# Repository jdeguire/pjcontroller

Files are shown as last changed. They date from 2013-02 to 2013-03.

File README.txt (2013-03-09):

I need to put something here, I guess...

Authors
-----
Jesse DeGuire, original creator

Intro
-----
This is the Projector Controller project.  The goal is to provide the DIY projector community with a robust and simple means of controlling basic functionality of their DIY light-beaming creations.  This includes things like monitoring temperature (and shutting the projector down if it gets too hot), controlling fan speed to keep the projector quiet, and turning the lamp on when the user presses the "On" button on the remote or OSD panel.

I once had a DIY projector that did much of this (rather poorly) using relays, attic fan thermostats, and way too much wiring, thus the inspiration for this project.

This project also shows that I'm terrible at coming up with clever names...

The Good Stuff
-----
The Projector Controller is made up of firmware that runs on the microcontroller on the board, software that runs on the PC and talks to the board, and the board hardware itself.

There are actually two firmwares:  the bootloader and the application.  If you plan on building either of those, you'll need the following:
--avr-gcc (Ubuntu's repo has this as 'gcc-avr' for some reason)
--avr-binutils (Ubuntu has this as 'binutils-avr')
--avr-libc
--avrdude
--scons, which in turn requires Python

The SConscript/SConstruct files assume that you are using the avr-gcc toolchain and avrdude as your
ICSP programmer.  You can modify the files if this is not the case.

To modify or run the software, you'll need:
--Python (written in v2.7)
--PySide
--PySerial

To build the software into an executable, you'll need PyInstaller and whatever prerequisites it requires.  I have been able to build a Windows executable under Windows 7 Professional Edition 64-bit without too much trouble.  This is available at /software/win32.

The schematic and board layout are created with KiCAD.  The board is currently manufactured at OSH Park (www.oshpark.com).  The Bill of Materials is available in the repo at /hardware/BoM.ods as an Open Document Spreadsheet.  LibreOffice, OpenOffice, and newer versions of Microsoft Word can open it.

More Info
-----
The Developers Guide located at /docs/devguide.pdf contains much more detailed information about the hardware, firmware, and software implementations.  Tinkerers and curious users should look at that guide and the accompanying source code and schematics.  The document is written in LaTeX and the source is in the /docs/tex directory.

Licensing
-----
The EDA design files (in hardware/pjc-kicad), along with the documents and their sources (in docs/
and docs/tex) are licensed under the Creative Commons Attribution-ShareAlike 3.0 License.  The
software and firmware code (in software/ and firmware/) , as well as their SCons build scripts, are
available under the GPLv3.

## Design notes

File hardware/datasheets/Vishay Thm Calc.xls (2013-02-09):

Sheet: user mode
 | BCcomponents
Computation spreadsheet for VISHAY BC components of reference NTCA and NTCLE
THIS FILE contains RT curves not present in the standard "RT chip-leaded & assemblies in °C" file.
The initial temperature of the table can be defined freely starting from -55 °C,and the step of temperature can be chosen between 0.1 °C and 10 °C
The maximum temperature will be fixed at 150 °C.
The reference resistance and temperature values must be given ( 25 °C or other) as well as the resistance tolerance value.
An exact B25/85 value corresponding to a selected R25 range taken from the table 1 below must be selected.
If the reference resistance for the chosen B25/85 value is not within the given limits, the following error message will
appear: "error : chosen Rref and B25/85 not compatible". Then use an adapted Rref and B25/85.
Once the B25/85 value has been chosen, the spreadsheet will show the B25/85 tolerance and the Steinhart and Hart coefficients.
In the user's mode, the example data are given for a NTCALUG03A103 (10 kOhms at 25 °C, B25/85 = 3984 K).
If the filled values are not valid, or if some values are missing, error messages will appear indicating what to do.
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

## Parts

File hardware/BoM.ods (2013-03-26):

Projector Controller Estimated Bill of Materials
Prices current as of February 23, 2013
Does not include assembly or equipment costs (eg. Solder or iron)
Prices based on minimum order quanity of 1 unit; volume discounts are not accounted for. Prices are in US Dollars.
Function | Part Number | Qty. | Vendor | Unit Price | Total Price | RoHS? | Notes
Integrated Circuits
Microcontroller | Atmel Atmega328P-PU | 1 | Mouser | 2.24 | 2.24 | Yes | DIP-28 300mil package
USB UART Interface | FTDI FT232RL | 1 | Mouser | 4.50 | 4.50 | Yes | SSOP-28 package
Ambient Temperature Sensor | Analog Devices TMP36FSZ | 1 | Digikey | 1.84 | 1.84 | Yes | SOIC-8 package
Open-Drain Buffer | TI SN74LVC1G07DBV | 1 | Digikey | 0.16 | 0.16 | Yes | SOT23-5 package
Themistor ADC | Microchip MCP3301-BI/SN | 1 | Mouser | 2.74 | 2.74 | Yes | SOIC-8 package; device is a 13-bit signed ADC
Low-Side Driver | ON Semi NUD3124DMT1G | 2 | Mouser | 0.36 | 0.72 | Yes | SOT23-6 package
5V Linear Regulator | ST Micro L78M05CDT-TR | 1 | Digikey | 0.44 | 0.44 | Yes | DPAK package
Reverse Polarity FET | Rohm Semi RSQ045N03 | 1 | Digikey | 0.78 | 0.78 | Yes | Thin SOT23-6 package
USB Suspend FET | Doides Inc. DMP2215L | 1 | Digikey | 0.40 | 0.40 | Yes | SOT23-3 package
Fan High-Side Driver | Infineon BSP762T | 1 | Digikey | 2.40 | 2.40 | Yes | SOIC-8 package
Input Optoisolator | Vishay VOM618A-4T | 1 | Mouser | 0.43 | 0.43 | Yes | SOP-4 package
Green LED | Kingbright APT3216CGCK | 1 | Mouser | 0.14 | 0.14 | Yes | 1206 SMT package; 50mcd @ 20mA, 2.1V Vf
Red LED | Kingbright APT3216SURCK | 1 | Mouser | 0.17 | 0.17 | Yes | 1206 SMT package; 220mcd @ 20mA, 1.95V Vf
Yellow LED | Kingbright APT3216SYCK | 1 | Mouser | 0.18 | 0.18 | Yes | 1206 SMT package; 150mcd @ 20mA, 2.0V Vf
20MHz Oscillator | ECS ECS-200-20-3X-EN-TR | 1 | Mouser | 0.60 | 0.60 | Yes | CSM-3X package
Passive Components
PTC 120mA Fuse | Cooper Bussmann PTS120630V012 | 5 | Digikey | 0.30 | 1.50 | Yes | 1206 SMT package
3.3kOhm Resistor | Stackpole RMCF1206FT3K30 | 3 | Digikey | 0.06 | 0.18 | Yes | 1206 SMT package; 1%, 1/4W
10kOhm Resistor | Stackpole RMCF1206FT10K0 | 8 | Digikey | 0.06 | 0.48 | Yes | 1206 SMT package; 1%, 1/4W
20kOhm Resistor | Stackpole RMCF1206FT20K0 | 1 | Digikey | 0.06 | 0.06 | Yes | 1206 SMT package; 1%, 1/4W
2.2kOhm Resistor | Stackpole RMCF1206FT2K20 | 1 | Digikey | 0.06 | 0.06 | Yes | 1206 SMT package; 1%, 1/4W
1.5kOhm Resistor | Stackpole RMCF1206FT1K50 | 1 | Digikey | 0.06 | 0.06 | Yes | 1206 SMT package; 1%, 1/4W
1kOhm Resistor | Stackpole RMCF1206FT1K00 | 1 | Digikey | 0.06 | 0.06 | Yes | 1206 SMT package; 1%, 1/4W
470Ohm Resistor | Stackpole RMCF1206FT470R | 1 | Digikey | 0.06 | 0.06 | Yes | 1206 SMT package; 1%, 1/4W
10uF Capacitor | Taiyo Yuden GMK316BJ106KL-T | 1 | Digikey | 0.36 | 0.36 | Yes | 1206 SMT package; 10%, 35V, X5R
1uF Capacitor | Taiyo Yuden UMK316B7105KL-T | 1 | Digikey | 0.25 | 0.25 | Yes | 1206 SMT package; 10%, 50V, X7R
4.7uF Capacitor | Taiyo Yuden UMK316AB7475KL-T | 1 | Digikey | 0.28 | 0.28 | Yes | 1206 SMT package; 10%, 50V, X7R
100nF Capacitor | Murata GRM319R71H104KA01D | 8 | Digikey | 0.11 | 0.88 | Yes | 1206 SMT package; 10%, 50V, X7R
10nF Capacitor | Murata GRM319R71H103KA01D | 1 | Digikey | 0.20 | 0.20 | Yes | 1206 SMT package; 10%, 50V, X7R
33pF Capacitor | Kemet C1206C330J1GACTU | 2 | Mouser | 0.11 | 0.22 | Yes | 1206 SMT package; 10%, 50V, C0G
USB Ferrite Bead | Laird MI1206L391R-10 | 1 | Digikey | 0.11 | 0.11 | Yes | 1206 SMT package
Backfeed Diode | Diodes Inc. S1M-13-F | 1 | Digikey | 0.15 | 0.15 | Yes | SMA package; 1A If, 1000V reverse voltage
Connector Headers (Onboard)
Thermistor Input | JST B2B-PH-K-S(LF)(SN) | 1 | Digikey | 0.16 | 0.16 | Yes | PH Series 2.0mm pitch 2-pos, 2A per contact
External LEDs/Relay | TE Connectivity 292207-2 | 4 | Mouser | 0.32 | 1.28 | Yes | Mini CT Series 1.5mm pitch 2-pos, 2A per contact
Switch Input | TE Connectivity 292207-3 | 1 | Mouser | 0.31 | 0.31 | Yes | Mini CT Series 1.5mm pitch 3-pos, 2A per contact
Fan Output | Molex 47053-1000 | 1 | Digikey | 0.43 | 0.43 | Yes | 4-pin PC Fan connector, 2.54mm pitch, 4A per contact
12V Input | TE Connectivity 1776275-2 | 1 | Mouser | 0.41 | 0.41 | Yes | 3.5mm pitch 2-pos screw terminal, 7A per contact
ICSP Connector | Sullins SBH11-PBPC-D05-ST-BK | 1 | Digikey | 0.61 | 0.61 | Yes | 2.54mm pitch 2x5 shrouded black, 3A per contact
USB Connector | On Shore Technology USB-M26FTR | 1 | Digikey | 0.68 | 0.68 | Yes | Mini-B USB SMD
Bootloader Enable Jumper | SparkFun PRT-00116 | 1 | SparkFun | 1.50 | 1.50 | Yes | Basic 2.54mm pitch jumper pins, sold as 40-pin breakaway headers
Connector Plug (External)
Thermistor Input | SparkFun PRT-08670 | 1 | SparkFun | 0.95 | 0.95 | Yes | JST PH Series jumper, red and black wires
External LEDs/Relay | TE Connectivity 353293-2 | 4 | Digikey | 0.26 | 1.04 | Yes | Mini CT "MT" Connector 28-26AWG, 2-pos
Switch Input | TE Connectivity 353293-3 | 1 | Digikey | 0.27 | 0.27 | Yes | Mini CT "MT" Connector 28-26AWG, 3-pos
2-pin Jumper Shunt | TE Connectivity 2-382811-1 | 1 | Mouser | 0.10 | 0.10 | Yes | Basic jumper shunt, very common part from many sources
Other
Reset Button | TE Connectivity 3-1977120-6 | 1 | Digikey | 0.10 | 0.10 | Yes | PTH 4-pin; oringally known as FSM4JH (vendors may be using this number)
MCU Socket | TE Connectivity 1-390261-9 | 1 | Mouser | 0.31 | 0.31 | Yes | DIP-28 300mil
5V Selector Switch | C&K JS102011SAQN | 1 | Digikey | 0.51 | 0.51 | Yes | 3-pin SMT
Thermistor | Vishay NTCALUG02A103G | 1 | Mouser | 1.19 | 1.19 | Yes | 10kOhm @ 25degC, Ring Terminal, M3 screw
Manufacturing
Bareboard Cost | 2-layer PCB, ~18sq. in. | 1 | OSH Park | 90.00 | 90.00 | Yes | Based on $5/sq. in. Each order is for 3 boards.
Totals
 |  | 75 |  |  | 122.50

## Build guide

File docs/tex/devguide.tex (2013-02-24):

% Copyright © 2011-2013 Jesse DeGuire
%
% This file is part of Projector Controller.
%
% This work is licensed under the Creative Commons Attribution-ShareAlike 3.0 Unported License. You
% should have received a copy of the license along with this work.  If not, see
% <http://creativecommons.org/licenses/by-sa/3.0/>.
%
% File:   devguide.tex
% Author: Jesse DeGuire
%
% LaTeX source for the PJC Developers Guide document.  This can be made into a PDF using a suitable
% LaTeX distribution such as TeX Live for GNU/Linux or MiKTeX for Windows.

\documentclass{article}

\usepackage{textcomp}
\usepackage{textgreek}
\usepackage{url}
\usepackage{longtable}
\usepackage{anysize} 
\usepackage{graphicx}
\usepackage{amsmath}
\usepackage{floatflt} 
\usepackage{enumitem}
\usepackage[pdftex]{hyperref}
\hypersetup{colorlinks=true, urlcolor=cyan, linkcolor=blue}

\marginsize{.75in}{.75in}{.75in}{.75in}

% just so that the document revision is somewhere convenient
\newcommand{\docrev}{A}

% makes a backslash
\newcommand{\bs}{$\backslash$}

% degree symbol and overbar in either math or text mode
% found these on the TeX Stack Exchange
\newcommand{\degree}{\ensuremath{^{\circ}}}
\newcommand{\textoverline}[1]{$\overline{\mbox{#1}}$}

% enclose argument in angle brackets
\newcommand{\abrackets}[1]{\textlangle #1\textrangle}

\begin{document}

% don't add extra space to sentence ends when justifying text
\frenchspacing

\noindent {\Huge Projector Controller} \\
{\large Developers Guide} Rev. \docrev \\
Author: Jesse DeGuire \\
Email: \href{mailto:jesse.a.deguire+pjc@gmail.com}{jesse.a.deguire+pjc@gmail.com} \\
Date: \today \\

\tableofcontents

% redefine \section command to start section on new page
\let\stdsection\section
\renewcommand{\section}{\newpage\stdsection}

% set spacing between paragraphs
\setlength{\parskip}{8pt}

% set up spacing for lists using 'enumitem' package
\setlist{labelindent = \parindent, itemsep=0pt}

\section*{Revision History}
\phantomsection
This section describes revisions made to this document.  Changes made to the hardware, firmware, or
software are described in their respective sections.

\begin{center}
    \begin{tabular}{c|c|p{0.6\textwidth}}
        Doc Revision & Date & Changes \\
        \hline
        A & Feb. 14, 2013 & Initial revision \\
    \end{tabular}
\end{center}

\section{Introduction}
This document provides implementation details for the various pieces of the Projector Controller
system.  The information contain within will hopefully be useful for anyone who wishes to modify or
tinker with the any part of the system or at least will satisfy an interested user's curiosity.
Anyone who is only looking to get the Controller running in his or her projector should instead
consult the \textit{Projector Controller Users Guide}.

This guide is divided up into a few sections.  The \hyperref[sec:Hardware]{Hardware} section
describes the components used on the board itself as well as the power requirements and capabilities
of the board.  The \hyperref[sec:Firmware]{Firmware} section contains information regarding the
program flow of the bootloader and application firmwares used by the Projector Controller.  This
also contains documentation for the command interfaces used by both to communicate to the host PC as
well as brief descriptions of many of the source code files.  Finally, the
\hyperref[sec:Software]{Software} section describes how the PC-side software communicates to the
board.  All sections will additionally state what tools were used in their development so that
anyone can build and modify the various pieces.

\subsection{Sources and Licenses} \label{ssec:SourceLic}
All source files used to create the board, software, and firmwares are available in a Git repository
on GitHub at \url{https://github.com/jdeguire/pjcontroller}.  The repository also contains
datasheets for the hardware components and other reference material.  This document will often
reference paths within the repository.  For example, the path \path{firmware/common/uart.c} should
be read as ``\path{[\emph{location/to/which/repository/was/cloned}]/firmware/common/uart.c}''.

The firmware and software, the sources of which are located in the \path{firmware/} and
\path{software/} directories in the aforementioned repository, are made available under the GNU
Public License Version 3.  A copy of the GPLv3 is provided in the file \path{COPYING.txt} in the
repository root or online at \url{http://www.gnu.org/licenses/}.

This document, the \textit{Users Guide}, their associated \LaTeX{} source files, and the board
design files are all made available under the Creative Commons Attribution-ShareAlike 3.0 Unported
License.  The source files for the \textit{Developers Guide} and \textit{Users Guide} are available
in the \path{docs/tex/} directory.  The board design files are found in
\path{hardware/pjc-kicad/}.  A copy of the Creative Commons BY-SA 3.0 license is provided in the
file \path{CC BY-SA 3.0 legalcode.txt} in the repository root or online at
\url{http://creativecommons.org/licenses/by-sa/3.0/}.

Where attribution is required, it is sufficient to include a statement of reasonable visibility in
the derived work or supporting documentation mentioning that the work is derived from this project
and giving this author's name.  It would be appreciated if the statement also contained the URL,
given above, for the version control repository.

Located in \path{hardware/pjc-kicad/libs/} are two files \path{SparkFun.lib} and
\path{SparkFun.mod}.  These were converted into their current form for use with KiCad from the
original Eagle libraries provided by SparkFun Electronics under the CC BY-SA 3.0 license.  The
latest such libraries can be found on GitHub at
\url{https://github.com/sparkfun/SparkFun-Eagle-Libraries}.

\subsection{Open Source Hardware} \label{ssec:OpenSourceHW}
\begin{floatingfigure}{0.22\textwidth}
    \centering
    \vspace{-6pt}
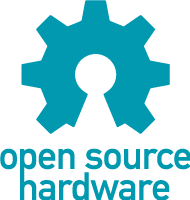
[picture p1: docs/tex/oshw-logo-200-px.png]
    
\end{floatingfigure}

As described above, all design and source code files for Projector Controller are available under
licenses allowing one to ``study, modify, distribute, make, and sell the design or hardware based on
that design''.  The project was developed using freely-available tools, most of which are also open
source, lowering the barrier to accessing the design.  Therefore, the author believes that the
Projector Controller qualifies as Open Source Hardware as given in the Open Source Hardware
Definition 1.0.  The defintions is availabe from the Open Source Hardware Association at
\url{http://www.oshwa.org/definition/}.

Note that the logo itself does not have a license associated with it, but the guidelines presented
at \url{http://www.oshwa.org/faq/} recommded its use.  Any derived works which do not adhere to the
definition of Open Source Hardware should remove the logo from any files which contain it.

\section{Hardware} \label{sec:Hardware}
The hardware was designed using KiCad EDA, an open source (GPLv2) multi-purpose EDA tool available
for various flavors of GNU/Linux, Windows, and OS X.  Get KiCad from the official site at
\url{http://www.kicad-pcb.org/display/KICAD/Download+Kicad}.  If possible, download a Snapshot build
as those contain additional features over the rather old stable release.  Ubuntu users should use
the Adam Wolf PPA given on that page.

Datasheets for the various components used are available in the repository under
\path{hardware/datasheets}.  The datasheets are provided for reference only and belong to their
respective manufacturers.

\subsection{Hardware Changes} \label{ssec:HWChanges}
This section lists the changes that have been made to the different board revisions over time.  The
revision is incremented when the board layout is changed and those changes are made into
manufactured boards.

\begin{center}
    \begin{tabular}{c|c|p{0.6\textwidth}}
        HW Revision & Date & Changes \\
        \hline
        A & Feb. 14, 2013 & Initial revision \\
    \end{tabular}
\end{center}

\subsection{Design Considerations} \label{ssec:DesignConsid}
Becuase the Projector Controller will probably never acheive high-volume production, the main
consideration was ease of assembly.  When possible, the components used are of a large form factor
(such as 1206 for resistors) and the footprints for surface-mount devices use long pads to make
accessing them with a soldering iron easier.  The board uses a socket for the 28-pin DIP
microcontroller to allow easy replacement.  These choices allow the board to be assembled by hand
for small production runs and allow the user to more easily tinker with the board.

Though not a primary consideration, the board was also designed with an eye on power consumption.
The board will be able to run certain componenets from USB power.  USB provides 5V at 100mA by
default, though a device can request up to 500mA.  The USB interface device does not identify itself
as a high-power device by default, so all 5V components will need to consume less than 100mA
combined.  The power consumption of the board is characterized in the
\hyperref[ssec:PowerUsage]{Power Usage} section.

\subsection{Circuit Details} \label{ssec:CircuitDetails}
Following are desciptions of the different circuit pieces developed for the board.  The reader of
this section may want to have the schematic handy in order to follow along.  The titles of the
descriptions will closely match the text titles used in the schematic for the different circuits.

\subsubsection{Microcontroller} \label{sssec:Microcontroller}
The heart of the Projector Controller is an Atmel ATMega328P 8-bit microcontroller.  The MCU has
32KB of flash, 4KB of which is used for the bootloader, 2KB of RAM and several useful peripherals,
such as 10-bit ADCs, SPI, PWM outputs, timers, and quite a few IO pins.  The MCU is a 28-pin DIP
package which will insert into a socket on the board, making removal and replacement easy.

An ECS 20MHz crystal oscillator provides the CPU clock.

Three LEDs--red, yellow, and green--are provided to allow the firmware to convey diagnostic
information while running.  The LED outputs also control low-side drivers, which is explained in the
\hyperref[sssec:RelayLED]{Relay and LED Outputs} description.

A jumper, pulled low, is connected to an IO pin on the microcontroller.  Shorting the jumper sets
the state of that IO pin high.  The state of this pin is read by the bootloader when it first starts
up.  If the pin state is high, the bootloader will not start the application and will instead stay
in the bootloader.  This allows one to recover from a problematic application that fails on startup.

\subsubsection{USB/UART IO} \label{sssec:USBUART}
The Projector Controller communicates with the outside world by utilizing an FTDI FT232R UART to
USB interface chip.  The chip connects to a standard USB Mini-B connector on one side and the
microcontroller's logic-level UART pins on the other, acting as a translator between the two
protocols.  The chip presents itself to the connected USB host as a virutal COM port to
allow one to communicate with the board using a terminal program such as TeraTerm or HyperTerminal.
Newer operating systems should have drivers for the device pre-installed; however, drivers are also
available from \url{http://www.ftdichip.com/FTDrivers.htm}.  Windows users may need to download the
needed drivers from Windows Update.

The circuit used is similar to the one presented in Section 6.3 of the FT232R datasheet.  Because
the 5V components on the board can be powered over USB (see the \hyperref[sssec:MainPower]{Main
  Power Input} description), this device needs to comply with USB suspend mode requirements.  When
the USB host enters USB Suspend Mode, the attached device must power down and draw less than 2.5mA
of current.  To facilitate this, pin 14 of the FT232R defaults to an active low ``Power Enable'' pin.
When entering USB suspend mode, that pin will be pulled high by the 10k\textOmega{} pullup and will
``turn off'' the Diodes Inc. DMP2215L P-channel MOSFET, essentially cutting power to the rest of the
5V system.  When the USB host exits Suspend Mode, the FT232R will pull the line low to re-active the
MOSFET.  The datasheet for the MOSFET give a current rating of 2A at 70\textcelsius{}.

The FT232R defaults to USB low-power mode, which requires that the device in question draw at most
100mA.  Given a thermal resistance of 115\textcelsius{}/W and on-resistance of 100m\textOmega{}, a
100mA draw would raise the MOSFET's temperature over ambient by

\begin{align*}
    \Delta T &= P * R_{th} \\
    &= (I^2R) * R_{th} \\
    &= (0.01 * 0.1) * 115 \\
    \Delta T &= 0.115\degree C
\end{align*}

Both the USB connector and the FT232R are fine-pitch parts, the latter using a 28-pin SSOP package.
These two are probably the most challenging parts on the board to solder, so they will need to be
placed appropriately to help make soldering them a bit easier.

\subsubsection{Main Power Input} \label{sssec:MainPower}
The board accepts a nominal 12V supply through a screw terminal rated up to 7A input, which is much
higher than the continuous current the board is designed for (see the
\hyperref[ssec:PowerUsage]{Power Usage} and \hyperref[sssec:FanControl]{Fan Control} descriptions).

To help prevent damage from occurring due to hooking up the power supply backwards, a Rohm
Semiconductor RSQ045N03 N-channel MOSFET is placed across what is normally the current return path
and the gate connected through a 3.3k\textOmega{} resistor to the normally-positive side.  When the
power is connected correctly, the gate is pulled up to 12V and the FET is fully-on.  When the power
is connected backwards, the gate is pulled low and the MOSFET is turned off.  The MOSFET has a
steady-state current rating of 4.5A and a peak rating of 18A.  The device also has a max
on-resistance of 38m\textOmega{}.  With a maximum temperature of 150\textcelsius{} and a thermal
resistance of 100\textcelsius{}/W, at 40\textcelsius{} ambient\footnote{The inside of a projector
  will certainly be warmer then the outside air temperature, with the actual ambient temperature
  depending on where inside the projector the board is placed.  The chosen 40\textcelsius{} value is
  probably on the warmer side of normal, but provides some safety margin.  This is used as the
  ambient temperature throughout this document.} the maximum power dissipated by the device is given
by

\begin{align*}
    P_{max} &= \frac{T_{max}-T_{amb}}{R_{th}} \\
    &= \frac{150 - 40}{100} \\
    P_{max} &= 1.1W
\end{align*}

which gives a maximum current of

\begin{align*}
    I &= \sqrt{\frac{P}{R_{th}}} \\
    &= \sqrt{\frac{1.1}{0.038}} \\
    I &\approx 5.38A
\end{align*}

meaning that the device is limited by the specified limit of 4.5A rather than by heat.

The 5V supply comes from an ST Microelectronics L78M05C linear regulator fed from the 12V supply.
The device is rated to output currents up to 0.5A and features thermal overload shutdown that will
cut output power in order to protect itself.  The device has a maximum temperature of
150\textcelsius{} and a worst-case thermal resistance of 100\textcelsius{}/W, assuming minimal
heatsinking.

As previously stated, the 5V devices are designed to draw at most 100mA so that they can be powered
via USB.  A selector switch allows the user to select between USB and the 5V regulator as the 5V
power source.  This is useful in the case the user needs to remove the board from the projector and
connect it to the PC for configuring it.  The switch is rated for 6VDC at 300mA or 30VDC at 100mA.
The output side of the selector switch has a Cooper Bussmann PTS120630V012 PTC fuse rated at 120mA
at 23\textcelsius{}.  Using the derating curve in the datasheet shows that the hold current drops to
about 100mA at an ambient temperature of 40\textcelsius{}.  A Diodes Inc. S1M-13-F diode, rated at
1A continuous and 1000V reverse DC voltage, is placed between the regulator and 12V input to prevent
USB current from back-feeding through the regulator.  If only a USB cable is connected to the board,
only the 5V devices will be powered.

Given a worst-case thermal resistance of 100\textcelsius{}/W and nominal voltage drop of 7V, a 100mA
draw would raise the device's temperature over ambient by

\begin{align*}
    \Delta T &= P * R_{th} \\
    &= (V*I) * R_{th} \\
    &= (7 * 0.1) * 100 \\
    \Delta T &= 70\degree C
\end{align*}

Some heatsinking can be provided by englarged pads or copper pours on the board.

\subsubsection{Programming and Reset} \label{sssec:ProgReset}
The ATMega328P microcontroller can be reprogrammed using a standard 10-pin AVR ISP header.  The
pinout used should work with most, if not all, external programmers.  The microcontroller is
programmed through the SPI lines while the device is held in reset.  The 5V pin on the header allows
the board to power the programmer so that the logic signals are at the correct voltage levels.  If
the board is powered via USB, care must be taken to not exceed a total of 100mA draw when powering
the programmer in this manner.  See \hyperref[ssec:PowerUsage]{Power Usage} for more information.

The user can reset the board using a push button connected to ground.  The device's
\textoverline{RESET} pin is active low, so it is normally pulled high and pressing the button
creates a connection to ground.

\subsubsection{Analog Inputs} \label{sssec:AnalogIn}
Two of the microcontroller's analog inputs are used to monitor the 12V input and ambient temperature
from an Analog Devices TMP36 temperature sensor.  The microcontroller's analog inputs are 10-bit
single-ended ADCs.

The 12V input is divided down using a simple resistive divider in an approximate 3:1 ratio, meaning that the
input into the ADC is about 1/4 the actual voltage.  More specifically, to determine the actual
voltage on the 12V input, multiply the ADC voltage by 4.03.

The TMP36 ``F Grade'' part used here has a worst-case accuracy of \textpm3\textcelsius{}.  At
0\textcelsius{} the device outputs 500mV and the output changes by 10mV/\textcelsius{}.

\subsubsection{Relay and LED Outputs} \label{sssec:RelayLED} 
Four 12V outputs are provided to control external devices.  The outputs are controlled using two ON
Semiconductor NUD3124DMT1G dual low-side drivers.  The drivers are meant to be single-chip solutions
for driving small motors and relays and so include a flyback diode and gate resistor.

The 4 connectors are 2-pin TE Connectivity Mini CT series connectors, which are 1.5mm pitch and
rated for 2A maximum.  The LED connectors will be grouped together and the relay connector separated
a bit to help differentiate them.

Three of the driver outputs are controlled by the three LED outputs on the microcontroller (see
\hyperref[sssec:Microcontroller]{Microcontroller} description).  The user can connect external LEDs
to these outputs and mount them to the projector's chassis so that the firmware's diagnostic
signaling is visible from outside the projector.  The outputs provide 12V power, so the user will
need to use an appropriate current-limiting resistor with the external LED.  Alternatively,
electronics stores sell LED packages with the proper resistor built in.  The current-limiting
resistors for the onboard LEDs also act as pulldowns for these outputs.

The fourth output is used as a lamp enable output and can be used to turn on, for example, an
external relay coil which in turn turns the lamp on.  This output has a 10k pulldown on it.

The high side of each output has a Cooper Bussmann PTS120630V012 PTC fuse rated at 120mA at
23\textcelsius{}.  Using the derating curve in the datasheet shows that the hold current drops to
about 100mA at an ambient temperature of 40\textcelsius{}.  Given a thermal resistance of
329\textcelsius{}/W and worst-case on-resistance of 1.1\textOmega, both outputs drawing 100mA would
raise the driver's temperature over ambient by

\begin{align*}
    \Delta T &= P * R_{th} \\
    &= (I^2R) * R_{th} \\
    &= (0.04 * 1.1) * 329 \\
    \Delta T &\approx 14.5\degree C
\end{align*}

\subsubsection{Fan Control} \label{sssec:FanControl}
A single Molex 4-pin fan header is provided for connecting a standard PWM-controlled PC fan.  The
connector is rated at 4A max per contact.  The Sense output, which acts as a tachometer signal from
the fan, is not used.  12V power is controlled by an Infineon BSP762T high-side driver.  The driver
has a worst-case on-resistance of 200m\textOmega.  With a maximum temperature of 150\textcelsius{}
and a thermal resistance of 95\textcelsius{}/W, at 40\textcelsius{} ambient the maximum power
dissipated by the device is given by

\begin{align*}
    P_{max} &= \frac{T_{max}-T_{amb}}{R_{th}} \\
    &= \frac{150 - 40}{95} \\
    P_{max} &\approx 1.15W
\end{align*}

which is below the rated absolute maximum of 1.5W and therefore gives a maximum current of

\begin{align*}
    I &= \sqrt{\frac{P}{R_{th}}} \\
    &= \sqrt{\frac{1.15}{0.2}} \\
    I &\approx 2.4A
\end{align*}

which matches the typical load current ($I_{L(nom)}$) provided in the datasheet.  Note that the
on-resistance value used will occur only when the device is operating at its max junction
temperature; the on-resistance, and therefore temperature, will usually be much lower.  Users will
be instructed to draw 2A max.

The driver has a thermal shutdown feature to protect the device in over-current or short circuit
conditions.  The device will turn the output off when in thermal overload and turn it back on when
it has cooled sufficiently.  In the case of short circuit, the driver will repeatedly turn off and
back on with a repetitive short circuit current of 7A.  The driver is not designed to continuously
operate in this state, so the user will need to take care to not leave the output shorted.

The PWM output signal is supplied from one of the microcontroller's 8-bit PWM outputs.  According to
the Intel 4-pin fan specification (available in the \path{/hardware/datasheets} directory of the
repository), the nominal PWM output is 25kHz.  The PWM signal goes through a TI SN74LVC1G07
non-inverting open-drain buffer since the fan pulls up the signal internally. The buffer has a max
switching time of 3.5ns, which is far faster then required by the PWM signal.  The Intel fan spec
recommends a current sink capability of 8mA, though the maximum current a fan is allowed to source
is 5mA.  The recommended max for the buffer is 32mA (the absolute max is 50mA), so a user could
theoretically control 4 fans using splitters assuming each fan sources less than the recommended
current sink capability of the controlling device.

If the connected fan does not have a PWM input signal (standard PC 3-pin fan), the Projector
Controller will still provide basic on/off control with the high-side driver.

The driver input and buffer input signals each have a 10k\textOmega{} pulldown.

\subsubsection{Temperature Input} \label{sssec:TempInput}
Temperature is read using a Vishay NTCALUG02A103G 10k (\textpm2\% at 25\textcelsius) thermistor,
which is enclosed in a ring terminal for easy mounting in the projector.  The ring terminal accepts
a metric M3 screw.  The user will normally want to place the thermistor as close to the monitored
object, usually the LCD panel, as he or she can.  The user may need to try a few locations to find
the best one.

The thermistor input is a 2-pin JST PH Series connector, which is 2.0mm pitch and rated for 2A maximum.

The equation for getting the temperature from a thermistor is the Steinhart-Hart equation, which is

\[
T = \frac{1}{A + B\ln(\frac{R_T}{R_{25}}) + C\ln^2(\frac{R_T}{R_{25}}) + D\ln^3(\frac{R_T}{R_{25}})}
- 273.15
\]

where $R_T/R_{25}$ is the ratio between the thermistor's actual resistance and its reference
resistance (10k\textOmega{} in this case).  The basic equation gives the result in Kelvin, so 273.15
is subtracted to convert that to Celsius.  To get the temperature, it is necessary to determine the
thermistor's actual resistance and that can be done using the voltage going into the ADC.

The ADC is a Microchip MCP3301 differential SPI ADC that returns data in 13-bit two's complement
representation.  The positive input to the ADC, $IN+$, is the output of a voltage divider formed by
the thermistor and a 10k\textOmega{} resistor.  The ADC has a separate reference voltage input,
$V_{REF}$, and the input range is $\pm V_{REF}$.  To take advantage of the full 13-bit scale, a
voltage divider with two 10k\textOmega{} resistors splits the 5V input in half and the resulting
2.5V is fed into both the $V_{REF}$ and $IN-$ inputs.  If the thermistor is 25\textcelsius{}, it
will also be at 2.5V and so the ADC reading will be 0.  The ADC reading will be negative if the
thermistor is colder than 25\textcelsius{} and positive if warmer.  To get the actual voltage going
into the ADC positive in put, convert the ADC reading to voltage (remember to sign-extend the
reading) and then add 2.5V to it.

Note that if the thermistor is not connected, the voltage at the ADC should be 0 and so the reading
should be negative full-scale (-4096).  Conversely, if the thermistor input is shorted, then the
voltage should be around 5V and so the reading should be positive full-scale (4095).  However, the
ADC is not perfect and so such conditions may be close to, but not exactly, the full-scale
conditions.

The thermistor's actual resistance can now be calculated with

\[
R_T = \frac{R_2*V_{in}}{V_{ADC}} - R_2
\]

which is just the standard resistor divider equation solved for $R1$ (which is $R_T$ in this case).
To get the ratio between the actual resistance and the reference resistance required by the 
Steinhart-Hart equation, the above equation can be divided by $R_{25}$.  Doing that and plugging in
the appropriate values for $V_{in}$ and $R_2$ yields

\begin{align*}
    \frac{R_T}{R_{25}} &= \frac{\frac{10k * 5}{V_{ADC}} - 10k}{R_{25}} \\
    &= \frac{\frac{50k}{V_{ADC}} - 10k}{10k} \\
    \frac{R_T}{R_{25}} &= \frac{5}{V_{ADC}} - 1
\end{align*}

Notice that when the ADC reading is at negative full-scale (-4096 counts), $V_{ADC}$ will be zero
and so will cause a divide by zero error.  As mentioned above, this happens when the thermistor is
not connected and is an abnormal condition.  To avoid the divide by zero problem, look for the
negative full-scale reading and treat that as a special case.  One possible solution is to clamp the
input range to \textpm 4095.

The cofficients for the Steinhart-Hart equation come from a Microsoft Excel spreadsheet on Vishay's
website at \url{http://www.vishay.com/resistors-non-linear/curve-computation-list/}.  The
spreadsheet for the NTCALUG02A103G is available in the repository at
\path{/hardware/datasheets/Vishay Thm Calc.xls}.  The coefficients are on the RTCOEF page of the
spreadsheet and are

\begin{align*}
    A &= 0.0033540164 \\
    B &= 0.0002565236 \\
    C &= 2.605970e-6 \\
    D &= 6.329261e-8
\end{align*}

These coefficients and the previous equation provide enough information to evaluate the
Steinhart-Hart equation.

\subsubsection{Projector On Input} \label{sssec:PJOnInput}
The controller card for the projector's LCD panel also controls the LCD's backlight and will output
a 5V or 12V signal to a backlight inverter to turn it on.  Since the projector discards the
backlight in favor of a high-power lamp, the Projector Controller has an input for that backlight
signal and will use that for the similar purpose of turning on the lamp.  The input connector is a
3-pin TE Connectivity Mini CT series connector, which is 1.5mm pitch and rated for 2A maximum.  A
3-pin connector was used to differentiate it from the output connectors; the middle pin is not used.

The used connector pins go to the input of a Vishay VOM618A-4T opto-isolator. The opto has a minimum
current transfer ratio (gain) of 160\% when the current through the LED is 1mA.  The output is a
collector-emitter junction with the LED acting as the base of a transistor, so if the forward
current through the LED is 1mA then the collector current will be 1.6mA (assuming the device is not
saturated).  The LED on the opto can handle a reverse voltage of 6V, so the user needs to be careful
when connecting an input greater than that and make sure to not connect it backwards.

The collector of the opto is connected to 5V and the emitter connects to the microcontroller input
pin and a 20k\textOmega{} pulldown, making the input active-high.  With a typical collector-emitter
saturation voltage of 0.12V (max is 0.4V), the collector current is

\begin{align*}
    I_C &= \frac{V_{in} - V_{CESat}}{R_L} \\
    &= \frac{5 - 0.12}{10k} \\
    I_C &= 0.244mA
\end{align*}

so the LED forward current times the current transfer ratio must be greater than 0.244mA in order to
drive the opto in to saturation.  This is much lower than the maximum allowed collector current of
50mA.

Between the positive input pin and the anode of the LED is a 3.3k\textOmega{} current-limiting
resistor.  An LCD controller board with a 5V backlight enable signal will, with a typical LED
forward voltage of 1.1V, need to be capable of supplying

\begin{align*}
    I_F &= \frac{V_{in} - V_f}{R_I} \\
    &= \frac{5 - 1.1}{3.3k} \\
    I_F &= 1.18mA
\end{align*}

of current.  This is very close to the test current at which the opto's transfer ratio is rated.
Using an ambient temperature of 40\textcelsius{} derates the ratio to 90\%, according to Figure 9 on
page 5 of the datasheet, giving a minimum ratio of 1.44.  This make the theoretical collector
current 1.70mA, driving the opto well into saturation.  Performing similar math for a 12V input
shows that it will need to be able to supply about 3.3mA of current and will provide a theoretical
collector current of 4.75mA.  Doing the same math, but with $V_F$ at the max of 1.6V, shows that a
5V backlight signal will supply about 1mA with a theoretical collector current of 1.44mA and a 12V
signal will supply 3.15mA with a collector current of about 4.53mA.  In short, LCD controller boards
that provide a 5V or 12V backlight signal should have no trouble driving the opto into saturation
and should be able to do so while supplying only a small amount of current.

Future LCD controller boards, however, could have a 3.3V or lower backlight control signal.  Doing
the above math again with a 3.3V signal yields an LED forward current of

\begin{align*}
    I_F &= \frac{V_{in} - V_f}{R_I} \\
    &= \frac{3.3 - 1.1}{3.3k} \\
    I_F &= 0.67mA
\end{align*}

when using the typical LED forward voltage rating.  Because the current is below the 1mA test
current used by the datasheet, a additional derating of the current transfer ratio needs to be
applied.  Figure 11 on page 5 of the datasheet shows a derating of about 75\% at 25\textcelsius{}
ambient.  Applying that to the already-derated current transfer ratio of 1.44 gives 1.08.  This
means that a 3.3V input will typically have a theoretical collector current of 0.72mA.  This is 3x
higher than the actual collector current, which should easily drive the opto into saturation.  Doing
the same math with the max forward voltage of 1.6V gives a forward current of 0.5mA for a collector
current of 0.54mA.  This is a bit over twice the actual collector current, so the opto should still
be driven into saturation.

It should be noted that orignially a more standard zener diode circuit was considered.  However,
zener diodes appeared to be rated with a 5mA current.  This would mean that more current is required
from LCD controller boards that output their backlight signals to this board.  Drive specificatons
are rarely, if ever, available for LCD controller boards so it was decided to aim for a lower
current draw, which the VOM618A allows since its test current is 1mA.

\subsubsection{Mounting Holes} \label{sssec:MountingHoles}
The Projector Controller will have one mounting hole on each of its four corners.  The holes have a
4mm inner diameter and 10mm outer diameter for screw head clearance.  This is the same size used for
PC motherboards, so standoffs and screws that come with PC cases should be useable with this board.
The holes will accommodate either M3 metric screws or 6-32 standard UTS screws.

\subsection{Power Usage} \label{ssec:PowerUsage}
The following tables lists the current draw of the different components on the board.  When
possible, the values used are the worst-case useage given in the data sheet; actual usage should
normally be lower.  The device has 5V and 12V power, so multiplying the current given in the table
by its voltage input will give the power used.

\begin{center}
    \begin{tabular}{|l|c|l|}
        \hline
        Component & Current (mA) & Notes \\
        \hline
        \multicolumn{3}{|c|}{\textbf{5V Components}} \\
        \hline
        ATMega328P Active Current & 23 & See Note below \\
        ECS CSM-3X 20MHz Crystal & 0.02 & Derived from ``Drive Level'' rating \\
        FT232R Operating Current & 15 & Powered only from USB VBUS \\
        FT232R USB\_PWREN Current & 0.5 & Powered only from USB VBUS \\
        12V Feedback Divider & 0.9 & R1 = 10k\textOmega{}, R2 = 3.3k\textOmega{} \\
        TMP36 Supply Current & 0.05 & \\
        BSP762T Input Current & 0.015 & Current at IN pin while device is on \\
        MCP3301 $V_{REF}$ Current &  0.15 & Current at $V_{REF}$ while clocking data \\
        MCP3301 Operating Current & 0.45 & \\
        MCP3301 2.5V Divider & 0.25 & R1 = R2 = 10k\textOmega{} \\
        Thermistor Input Current & 0.5 & Worst case is shorted thermistor \\
        VOM618A-4T Collector Current & 0.25 & Assumes $V_{CE} = 0$ \\
        Green LED & 6.1 & \\
        Yellow LED & 2 & \\
        Red LED & 1.3  & \\
        5V, 10k\textOmega{} Pulldowns (4) & 0.5 x4 & \\
        5V, 10k\textOmega{} Pullups (2) & 0.5 x2 & \\
        \textbf{Total} & \textbf{53.485} & \\ 

        \hline
        \hline

        \multicolumn{3}{|c|}{\textbf{12V Components}} \\
        \hline
        5V Component Draw & 53.485 & See above \\
        L78M05C Quiescent Current & 6 & \\
        BSP762T Operating Current & 1.3 & \\
        \textbf{Total} & \textbf{60.785} & \\
        \hline
    \end{tabular}
\end{center}

{\small \textbf{Note}: Values were taken from Section 30.7 of the datasheet and includes all peripherals and
programming current but not external IO.  This assumes a 5.0V input voltage and 20MHz clock input.}

Any external 5V devices connected to the Projector Controller, including a board-powered ISP
programmer, must keep the total current draw under 100mA.  Given the total shown above, external
devices can use up to 46mA or so.

In addition to the loads shown here, the 12V supply also needs to be able to handle the external fan
and 4 outputs.  Therefore, the user will need to determine the current draw of his or her choosen
components and size a power supply that can handle those plus another 61mA for this board.

\subsection{Microcontroller Pinout} \label{ssec:MicroPinout}
Following is a table showing how the pins on the microcontroller are used and their net names on the
schematic, if applicable.

\begin{center}
    \begin{tabular}{c|l|l|l}
        Pin \# & Pin Name & Net Name & Description \\
        \hline 
        1  & (PCINT14/\textoverline{RESET}) PC6 & \textoverline{RESET} & Active-low CPU reset line \\
        2  & (PCINT16/RXD) PD0 & UART\_RX & UART receiver input \\
        3  & (PCINT17/TXD) PD1 & UART\_TX & UART transmitter output \\
        4  & (PCINT18/INT0) PD2 & FAN\_EN & Fan power enable \\
        5  & (PCINT19/OC2B/INT1) PD3 & FAN\_PWM & 25kHz fan control PWM signal \\
        6  & (PCINT20/XCK/T0) PD4 & \abrackets{None} & Bootloader enable pin \\
        7  & VCC & \abrackets{None} & Main supply input \\
        8  & GND & \abrackets{None} & Ground \\
        9  & (PCINT6/XTAL1/TOSC1) PB6 & \abrackets{None} & 20MHz crystal oscillator input \\
        10 & (PCINT7/XTAL2/TOSC2) PB7 & \abrackets{None} & 20MHz crystal oscillator input \\
        11 & (PCINT21/OC0B/T1) PD5 & LEN\_EN\_RED & Red LED enable \\
        12 & (PCINT22/OC0A/AIN0) PD6 & LED\_EN\_YELLOW & Yellow LED enable \\
        13 & (PCINT23/AIN1) PD7 & LED\_EN\_GREEN & Green LED enable \\
        14 & (PCINT0/CLKO/ICP1) PB0 & LAMP\_EN & Lamp relay enable \\
        15 & (PCINT1/OC1A) PB1 & \abrackets{Unused} & Not used \\
        16 & (PCINT2/OC1B/SS) PB2 & \textoverline{ADC\_CS} & SPI ADC chip select \\
        17 & (PCINT3/OC2A/MOSI) PB3 & MOSI & SPI master output \\
        18 & (PCINT4/MISO) PB4 & MISO & SPI master input \\
        19 & (PCINT5/SCK) PB5 & SCK & SPI clock \\
        20 & AVCC & \abrackets{None} & Analog suppy input \\
        21 & AREF & \abrackets{None} & Analog reference voltage \\
        22 & GND & \abrackets{None} & Ground \\
        23 & (PCINT8/ADC0) PC0 & AVA\_12V\_FB & 12V supply feedback \\
        24 & (PCINT9/ADC1) PC1 & ANA\_AMBIENT & Ambient temperature reading \\
        25 & (PCINT10/ADC2) PC2 & PROJECTOR\_ON & Projector on input \\
        26 & (PCINT11/ADC3) PC3 & \abrackets{Unused} & Not used \\
        27 & (PCINT12/ADC4) PC4 & \abrackets{Unused} & Not used \\
        28 & (PCINT13/ADC5) PC5 & \abrackets{Unused} & Not used \\
    \end{tabular}
\end{center}

\subsection{Connector Pinout} \label{ssec:ConnPinout}
The following tables gives the functions of the pins on each connector.  Pin 1 on through-hole
connectors can be found by looking for the square solder pad around the through-hole.  The USB
connector is the only surface mount connector and pin 1 is denoted by a small circle next to the
pin.

\begin{description}[itemsep = 18pt]
  \item[CON1:] Communication (USB Mini-B)
    \begin{center}
        \begin{tabular}{l|l}
            Pin \# & Description \\
            \hline
            1 & VBUS \\
            2 & D- \\
            3 & D+ \\
            4 & ID (Not Used) \\
            5 & GND \\
        \end{tabular}
    \end{center}
  \item[CON2:] Projector On Input (Mini CT 3-pin)
    \begin{center}
        \begin{tabular}{l|l}
            Pin \# & Description \\
            \hline
            1 & Input positve \\
            2 & Not Used \\
            3 & Input Negative \\
        \end{tabular}
    \end{center}
  \item[CON3:] Thermistor (JST PH 2-pin)
    \begin{center}
        \begin{tabular}{l|l}
            Pin \# & Description \\
            \hline
            1 & 5V to thermistor \\
            2 & Voltage from thermistor to ADC \\
        \end{tabular}
    \end{center}
  \item[CON4:] 12V Input (Screw Terminal)
    \begin{center}
        \begin{tabular}{l|l}
            Pin \# & Description \\
            \hline
            1 & 12V \\
            2 & Ground \\
        \end{tabular}
    \end{center}
  \item[CON5:] Fan Output (4-pin PC Fan Connector)
    \begin{center}
        \begin{tabular}{l|l}
            Pin \# & Description \\
            \hline
            1 & Ground \\
            2 & 12V \\
            3 & Sense (Not Used) \\
            4 & Control (PWM) \\
        \end{tabular}
    \end{center}
  \item[CON6:] External Red LED (Mini CT 2-pin)
    \begin{center}
        \begin{tabular}{l|l}
            Pin \# & Description \\
            \hline
            1 & 12V \\
            2 & Ground \\
        \end{tabular}
    \end{center}
  \item[CON7:] External Yellow LED (Mini CT 2-pin)
    \begin{center}
        \begin{tabular}{l|l}
            Pin \# & Description \\
            \hline
            1 & 12V \\
            2 & Ground \\
        \end{tabular}
    \end{center}
  \item[CON8:] AVR ISP Header (10-pin Shrouded)
    \begin{center}
        \begin{tabular}{l|l}
            Pin \# & Description \\
            \hline
            1  & MOSI (SPI Out) \\
            2  & VCC (5V) \\
            3  & LED/NC (Not Used) \\
            4  & Ground \\
            5  & Reset \\
            6  & Ground \\
            7  & SCK (SPI Clock) \\
            8  & Ground \\
            9  & MISO (SPI In) \\
            10 & Ground \\
        \end{tabular}
    \end{center}
  \item[CON9:] External Green LED (Mini CT 2-pin)
    \begin{center}
        \begin{tabular}{l|l}
            Pin \# & Description \\
            \hline
            1 & 12V \\
            2 & Ground \\
        \end{tabular}
    \end{center}
  \item[CON10:] Lamp Relay Enable (Mini CT 2-pin)
    \begin{center}
        \begin{tabular}{l|l}
            Pin \# & Description \\
            \hline
            1 & 12V \\
            2 & Ground \\
        \end{tabular}
    \end{center}
  \item[JP1:] Bootloader Enable Jumper
    \begin{center}
        \begin{tabular}{l|l}
            Pin \# & Description \\
            \hline
            1 & Jumper Pin 1 \\
            2 & Jumper Pin 2 \\
        \end{tabular}
    \end{center}
\end{description}

\subsection{Conversion Formulas} \label{ssec:ConversionFormulas}
The conversion formulas for the analong inputs discussed earlier are available here as well for
convenience.

\subsubsection{12V Feedback}
\begin{align*}
    V_{ADC} &= \frac{5 * Counts}{1024}\\
    V_{FB}  &= V_{ADC} * 4.03
\end{align*}

\subsubsection{Ambient Temperature}
\begin{align*}
    V_{ADC} &= \frac{5 * Counts}{1024} \\
    T_{Amb} &= 100 * (V_{ADC} - 0.5)
\end{align*}

\subsubsection{Thermistor Temperature}
The MCP3301 is a signed 13-bit ADC, so the reading must be sign-extended first.  Notice that a
reading of -4096 will cause a divide by zero error with these formulas.  This indicates a
disconnected thermistor and so is an abnormal condition that the software or firmware will need to
look out for.  One way to handle this is to clamp the input to \textpm 4095 and handle -4096 as a
special case.

\begin{align*}
    V_{ADC} &= \frac{2.5 * Counts}{4096} + 2.5 \\
    R &= \frac{5}{V_{ADC}} - 1 \\
    T &= \frac{1}{A + B\ln(R) + C\ln^2(R) + D\ln^3(R)} - 273.15
\end{align*}

where

\begin{align*}
    A &= 0.0033540164 \\
    B &= 0.0002565236 \\
    C &= 2.605970e-6 \\
    D &= 6.329261e-8
\end{align*}

\section{Firmware} \label{sec:Firmware}
The onboard ATMega328P has two different firmwares on it.  The first is a small bootloader that must
be programmed on using an external programming device.  A 10-pin header is provided onboard for this
purpose.  The bootloader is reponsible for programming application code into flash, allowing field
updates without the programming device. and to make sure a functional application is present before
handing over control to it.  The second firmware is the actual application code.  This is programmed
on by the bootloader and is what actually does the projector controlling.

This section will describe functionality common to each firmware and then delve into the functions
specific to each.  First is information on how to build and program the firmwares onto the board.

\subsection{Tools Used} \label{ssec:FWTools}
The firmware was developed in various versions Ubuntu Linux with the current one as of this writing
being version 12.10 Quantal Quetzal.  The applications listed should be available on other
distributions (or they can be built from source), but they may use different package names from what
is given here.

The firmwares use the AVR GCC cross-compiler, which is at version 4.7 as of this writing, with
the associated LibC and Binutils packages.  AVRDUDE is used to program the built firmware onto the
board.  Building and programming the firmware is handled by the SCons build tool, which itself
requires Python 2.4 or higher.

On Ubuntu 12.10, the following packages need to be installed to get everything:

\begin{itemize}
  \item gcc-avr
  \item binutils-avr
  \item avr-libc
  \item avrdude
  \item scons
\end{itemize}

The \texttt{scons} package should also grab the needed Python package.  If not, then that will need to be
installed as well.

Windows users can use Atmel Studio, which is a free IDE provided by Atmel which also includes the
needed toolchain.  The IDE is available on Atmel's website at
\url{http://www.atmel.com/tools/atmelstudio.aspx?tab=overview}.  Using the IDE itself would require
one to create two projects, one each for the bootloader and application, for the IDE since they are not
provided here.  Another possibility is to install SCons for Windows and Python alongside the IDE and
build using SCons.  The SCons Windows installer is available on the SCons website at
\url{http://www.scons.org/download.php}.  SCons should be able to find the toolchain as long as it
is in the Windows PATH.

\subsection{Building With SCons} \label{ssec:FWBuilding}
SCons is a build system (essentially a replacement for GNU Make) written in Python.  The build
scripts themselves are special Python files.  In the \path{firmware/} is a file called
\path{SConstruct}.  This is the top-level build script and contains settings that are used by both
the application and bootloader, such as include file paths and some compiler options.  The
\path{firmware/bootloader/} and \path{firmware/app/} directories each contain a file called
\path{SConscript}.  These are called from the \path{SConstruct} file and contain options
specific to the app or bootloader, such as the output file path, source files, and so on.  The files
themselves are commented so that anyone who wishes to modify build options can at least figure out
what needs to change in the files.

The SCons documentation is very good and even those inexperienced with SCons can set up a build just
by following the documentation.  The documentation is available on the SCons website at
\url{http://www.scons.org/doc/production/HTML/scons-user/index.html} and a wiki is available at
\url{http://www.scons.org/wiki/}.

To use SCons, open up a command-line window or terminal and navigate to the location of the
\path{SConstruct} file, which is \path{firmware/}.  Now run \texttt{scons \abrackets{command}},
where \texttt{\abrackets{command}} is one of the following:

\begin{description}
  \item[build-bootloader]: \\
    Build the bootloader using AVR GCC and output the resulting Intel hex file to
    \path{firmware/bootloader/output/pjc-bootloader.hex}.
  \item[write-bootloader]: \\
    Write the bootloader to the microcontroller using AVRDUDE and a compatible programmer (see
    below).  The bootloader must have been built using \texttt{build-bootloader} for this to work.
  \item[read-flash]: \\
    Read the entire contents of the microcontroller's flash memory and output the contents as an
    Intel hex file to \path{firmware/bootloader/output/pjc-flash-image.hex}.
  \item[erase-device]: \\
    Erase the device's flash, EEPROM, and lock bits, but not its fuse bits.
  \item[write-fuses]: \\
    Write the proper fuse and lock bits to the device.  This should be done the first time a new
    device is programmed.
  \item[build-app]: \\
    Build the application using AVR GCC and output the resulting Intel hex file to
    \path{firmware/app/output/pjc-app.hex}.
\end{description}

Multiple commands can be executed at once by putting more than one on the command line.  For
example, running \texttt{scons build-bootloader write-bootloader} will compile the bootloader and,
if successful, program it to flash.

The actions of these commands are defined in the \path{SConscript} files.  For example. the values
of the fuse bits programmed using the \texttt{write-fuses} command are defined in the
\path{firmware/bootloader/SConscript} file.

\subsection{Programming Flash} \label{ssec:FWProgFlash}
An external programming device is required to program the bootloader onto the device.  A 10-pin
header is provided onboard for this purpose.  The header pinout is standard across AVR device
programmers and so there are multiple programmers that will work.  

The build scripts are configured to use the ``usbtiny'' programmer protocol with AVRDUDE.  Any
programmer that conforms to that protocol will work.  Two such low-cost examples are the Adafruit
USBtinyISP (available at \url{http://www.ladyada.net/make/usbtinyisp/}) and the SparkFun Pocket AVR
Programmer (available at \url{https://www.sparkfun.com/products/9825}).

To use a different programmer, open \path{firmware/bootloader/SConscript} and look for the line
that says ``\texttt{icspdevice = 'usbtiny'}''.  Change it to a programmer that AVRDUDE recognizes (find
AVRDUDE documentation online) and save the file.

Linux users may find that trying to program a device results in AVRDUDE complaining that it cannot
talk to the programmer, saying something along the lines of ``Operation not permitted''.  If this
happens, running the command as root should make it work.  Another option is to create a new udev
rule for the programmer.  Create a new file in \path{/etc/udev/rules.d/}, or wherever udev rules
are stored, and add the line

\texttt{SUBSYSTEM=="usb", ATTR{idProduct}=="0c9f", ATTR{idVendor}=="1781", MODE="0666", GROUP="adm"}

Save the file with a descriptive name, such as \path{90-avrisp.rules}.  The number determines the
order in which the rule is processed.  Higher-numbered rules override lower-numbered rules.
Disconnect and reconnect the programmer and try again.  Note that the ``idProduct'' (0c9f) and
``idVendor'' (1781) are dependent on the actual device; the values shown are for the ``usbtiny''
programmers mentioned earlier.  Use the \texttt{lsusb} command to get the correct values for
different devices.

\subsection{Fuse and Lock Bits} \label{ssec:FWFuseBits}
The AVR microcontrollers have special locations in flash memory that hold configuration registers for
the device.  These control hardware configuration options such as the size of bootloader space, the
clock source, and write-protection features.  The mappings for the fuse and lock registers are given
in Section 28 of the ATMega's datasheet.  The following table summarizes the fuse bit configuration
used by the Projector Controller.

\begin{center}
    \begin{tabular}{l|c|p{0.5\textwidth}}
        Register & Value & Notes \\
        \hline
        lfuse & 0xF7 & Use external full-swing crystal and longest startup time \\
        hfuse & 0xD8 & Defaults except set to use bootloader reset vector; that is, start in the
        bootloader rather than application \\
        efuse & 0x04 & Brown-out detection enabled at 4.3V \\
        lock  & 0x3F & Defaults; no lock features enabled \\
    \end{tabular}
\end{center}

The fuse and lock bit values programmed onto the device are stored in
\path{firmware/bootloader/SConscript}.  Use caution when changing these as the wrong values can
make the device unprogrammable.  In that case, one would need to purchase a parallel programmer to
correct the problem.  Doing a search for ``AVR fuse calculator'' online will bring up utilities that
provide help in setting the bits to the correct values.

\subsection{Intel Hex Files} \label{ssec:FWIntelHex}
The firmwares are stored as Intel hex files, which are text files that store binary information,
such as program data for the firmware.  Each line is a record which can contain program data, 
address information, or an indicator that the end of file was reached.  The file is parsed one
record at a time to ultimately yield a binary image of the data.  Below is a typical record.

\texttt{:10700000CEC00000F3C00000F1C00000EFC00000DF}

The colon (``:'') at the beginning indicates the start of the record.  Every record has this and it
does not affect the data within.

The first two hex digits give the number of bytes in the data field.  In this record, there are 0x10
(16 decimal) data bytes.  There are always 2 digits.

The next four digits are the lower 16-bits of the address for the start of the data.  The upper
16-bits of the address, if needed, are set by different record types.  This field is used only for
Data Records, which is what this record is.  Other record types leave this as 0.  Note that there
are always 4 digits.  The address is big endian, meaning that the most significant byte comes first.

Next up are 2 digits that give the record type.  There are six records types.

\begin{description}
  \item[00,] Data Record \\
    This type holds data that is part of the firmware and so would be programmed into flash.  The
    16-bit address would be added to the upper portion given by record types 02 or 04 to get the
    full address, if needed.
  \item[01,] End Of File Record \\
    Indicates that the end of the file has been reached.  This is the last record in the file and
    usually looks like \texttt{:00000001FF}.  It contains no data.
  \item[02,] Extended Segment Address Record \\
    The data field of this record contains two bytes of data that together for the upper 16 bits of
    a 20-bit address.  The address is big endian.  Shift the data left by 4 bits to get the actual
    upper portion of the address.
  \item[03,] Start Segment Address Record \\
    This record is not relevant to the AVR architecture and so is not used.
  \item[04,] Extended Linear Address Record \\
    Simiar to record 02, except the data forms the upper 16 bits of a 32-bit address.  Shift the
    data left by 16 bits to get the upper portion of the address.  The address is big endian.
  \item[05,] Start Linear Address Record \\
    This record is not relevant to the AVR architecture and so is not used.
\end{description}

The next field is the data field and its size is given by the size field at the start of the
record.  Its contents depeds on the record type.  In this case, the data field contains 16 bytes of
program data since this is a Data Record.

The final field is a checksum.  This is the two's complement of the sum of all of the other bytes in
the record.  To determine the checksum, add up the values of the bytes in the other records, XOR the
sum with 0xFF, and add 0x01.  The checksum is the lowest byte of that result.  To verify a checksum,
add up all of the bytes, including the checksum, and check that the lowest byte of the result is 0.
If so, then the checksum is good.

Software that wants to update the Projector Controller's application through the bootloader will
need to be able to parse Intel hex files.  The file \path{/software/flashimge.py} contains code
that parses the hex file and can be used as a reference.

\subsection{Linker Scripts} \label{ssec:FWLinkerScripts}
The bootloader and application directories contain linker scripts \path{pjcbootloader.x} and
\path{pjcapp.x}.  The linker scripts serve two purposes.

The first purpose is to partition the flash memory between the application and bootloader so that
they do not collide.  The ATMega328P has hardware support for a bootloader, allowing one to use fuse
bits to allocate a portion of the end of flash to a bootloader.  The Projector Controller uses the
last 4KB of flash for the bootloader and so the linker script is set up so that all bootloader
program data goes into that section of flash.  The application's linker script allocates the lower
28KB of flash to the application.

The second purpose is to allow the application to jump back into the bootloader by simply clearing a
flag and performing a soft reset.  The linker scripts define a special NOLOAD section called
``.shareddata'' that contains a single boolean variable.  A NOLOAD section is one that is not
initialized during program startup, meaning that the data within it will survive a software reset.
The bootloader can check the state of the flag to see if it was cleared.  If it was, or if the CPU
was not reset by software, the bootloader will start the app if able.  Otherwise, it will stay in
the bootloader.

Firmware support for these linker script features is implemented in \path{sharedmem.c} and
\path{sharedmem.h} in \path{firmware/common/}.  The files are commented to help explain what
they are doing.

Performing an online search for ``ld linker scripts'' will produce information about how to use
linker scripts.  One such manual can be found at
\url{http://sourceware.org/binutils/docs-2.22/ld/Scripts.html}.

\subsection{Watchdog} \label{ssec:FWWatchdog}
The firmwares make use of the ATMega's built-in watchdog timer.  The watchdog is a timer that must
be periodically cleared.  If the watchdog times out before it is cleared, it will reset the device.
The idea is that this will prevent the device from getting stuck in a never-ending loop since the
watchdog will reset it.  Both firmwares use a watchdog timeout of 250ms.

Also, because the AVR instruction set does not have a \texttt{reset} instruction, the watchdog is
used to perform a soft reset.  To reset the device, the watchdog is set to its shortest timeout of
15ms and the firmware loops until the watchdog trips.

\subsection{LEDs} \label{ssec:FWLEDs}
The firmwares use the onboard green, yellow, and red LEDs to communicate basic information to the
outside world.  If no LEDs are lit, then either the board is not powered on or the micrcontroller is
blank (that is, no firmware is on it).

If only the yellow LED is on, then the bootloader is running.  The bootloader does not use the other
two LEDs.

The green LED is on if the application is running.  The following table gives the meanings of the
possible LED combinations used by the firmwares, including the ones listed above.

\begin{center}
    \begin{tabular}{c|c|c|p{0.5\textwidth}}
        Green & Yellow & Red & Meaning \\
        \hline
        Off & Off & Off & Board not powered or no bootloader or app programmed \\
        Off & On & Off & Bootloader is running \\
        On & Off & Off & App is running, but not doing anything \\
        On & On & Off & App is running; lamp and fan are on \\
        On & Blink & Off & App is running; lamp is off and fan is on \\
        On & Off & On & App encountered error, such as over-temp or missing thermistor \\
        On & Blink & On & App encountered error and fan is on \\
        On & On & On & Not used; should never see this \\
    \end{tabular}
\end{center}

\subsection{Register Map} \label{ssec:FWRegMap}
The file \path{firmware/common/regmap.h} defines bit fields for most of the ATMega328P registers,
making accessing them easier.  Registers that do not have any bit fields in them are not defined in
this file.  All of the registers defined here follow a simple naming convention:

\texttt{REGNAMEbits.field}

where \texttt{REGNAME} is the name of the register, such as \texttt{PORTB}, and \texttt{field} is the
lower-case name of a field in the register, such as \texttt{pb1}.  In this case, the full qualified
name would be \texttt{PORTBbits.pb1}.  The register can be read from and written to in this manner.
The addresses of the registers are known at compile time, meaning that the compiler can use the most
efficient AVR instruction to access the register.

Register fields that are multiple bits wide can be accessed either as a whole field or by individual
bit.  For example the \texttt{SMCR} register, used for controlling sleep modes, has the fields
\texttt{SM0}, \texttt{SM1}, and \texttt{SM2} which could be treated as a single 3-bit field.  The
whole field can accessed with \texttt{SMCRbits.sm} or a single bit accessed with
\texttt{SMCRbits.sm1}, for example.

Section 31 of the ATMega328P datasheet has a list of all of the device's registers.

\subsection{Flash and EEPROM} \label{ssec:FWflasheeprom}
The ATMega328P has 32KB of flash memory, divded into 128-byte pages.  The top 4KB of flash are
configured for use by the bootloader, making the lower 28KB available to an application.  Since each
page is 128 bytes, there are 224 pages avilable for the application.  Flash can be programmed one
byte at a time, but must be erased one page at a time.  The bootloader will always program one page
at a time and erase the entire 28KB app space.

The last page of flash is used by the bootloader to store the application's 16-bit CRC and a key
that is present when an app is programmed.  The bootloader uses these to verify that there is an
application onboard and that it is valid.

The microcontroller also has 1KB of EEPROM that the application uses to store setting that need to
be restored on start up.  These include things like the minimum fan speed, over-tempearture limit,
and control loop settings.  The application can read and write this EEPROM space.  The bootloader
does not read it, but can be instructed to erase the contents of EEPROM.  This is useful in the case
that some bad EEPROM settings are causing the application to misbehave.

\subsection{Communication} \label{ssec:FWComm}
The firmwares use the ATMega328P's UART module for communicating to whatever PC it is connected to.
The UART lines go into the onboard FTDI FT232R, which is a UART-to-USB translator that appears to
the PC as a virtual COM port.  Any software that can talk to serial ports, such as TeraTerm or the
software used with the Projector Controller, can talk to the device provided the right drivers are
installed.  Newer operating systems should have drivers for the device pre-installed; however,
drivers are also available from \url{http://www.ftdichip.com/FTDrivers.htm}.  Windows users may need
to download the needed drivers from Windows Update.

The firmwares talk at 115200 baud using 8 bits per transfer, no parity bit, no flow control, and one
stop bit (8-N-1).  Carriage returns are used as line endings.

Communication is handled on two levels.  The first level is the handling of the actual UART
interface on the device and this is done in \path{firmware/common/uart.c} and its header
\path{uart.h}.  The module contains a transmit and receive buffer and uses interrupts to transmit
data from the transmit buffer and receive data into the receive buffer.  The transmit and receive
functions in the module access those buffers and can transmit single bytes, byte arrays, or strings.

The default size of each UART buffer is 64 bytes.  Any software talking to the firmwares is
responsible for not overflowing the buffer.

The second level is the command inteface in \path{firmware/common/cmd.c} and its header
\path{cmd.h}. This module implements a state machine to run a command prompt interface that can be
used in a program like TeraTerm or HyperTerminal.  The state machine receives data from the UART
module until either it see a carriage return or until the command buffer is full.  It will also look
for backspaces to remove the most recent character and the Escape key to clear the buffer entirely.
When a new command string is received, it assumes that everything until the first space or carriage
return is the name of the command.  It looks through its list of registered commands for a match
and, if one is found, calls the function associated with that command.  If no match is found, the
module outputs ``Unknown command'' to indicate such.

Command are registered via the \texttt{Cmd\_RegisterCommand} function.  This function takes the name
of the command, a handler function pointer, and a short help string for the command.  The handler
function signature must match \texttt{void func(const char*, uint8\_t)}, where the parameters are the
command string and its length.  The handler function would parse the command string as needed,
execute its command, and send out a response.  The module has a few common commands defined, which
can be used as examples.

The default size of the command buffer is 32 bytes plus one for a null terminator.  The default
maximum number of commands is 10.

At startup, the module will transmit the string ``\texttt{---Startup---}'' (without quotes) and a
version string.  The former string allows software to determine when the device restarted when it
should not have.

\subsection{Firmware Config} \label{ssec:FWConfig}
Both the application and bootloader have a file called \path{appcfg.h}.  This file defines
compile time configuration settings for the firmware such as baud rate or the maximum number of
serial commands.  The header files for some of the modules in \path{firmware/common} will define
certain macros if they have not been defined already.  These are what control baud rate, buffer
sizes, and the like.  To use non-default values, simply define the macros in the \path{appcfg.h}
files with the desired value.  As an example, take a look at the bootloader's config file
\path{firmware/bootloader/appcfg.h} as the bootloader uses a couple of non-default values.

Also defined in these files are a version string and version number, which is sent over the UART
when the device starts up or in reaction to the ``v'' command.  The version string for the
bootloader should contain the word ``Bootloader'' (case sensitive) in it; likewise, the application
should \emph{not} have the word ``Bootloader'' in it.  The Projector Controller software looks for
that word to determine if the device is running the bootloader.
The bootloader's \path{appcfg.h} also defines the macro \texttt{PJC\_BOOTLOADER\_\_}, which allows
common code to act differently if the bootloader is being built.  The application should not define
this macro.

\subsection{Bootloader Specific} \label{ssec:FWBootloader}
The bootloader firmware is the first to run when the microcontroller powers up and is responsible
for making sure that an application is on board and jumping to it.  The bootloader can also be told
to stay there instead of jumping to the application firmware, allowing one to perform an application
update in the field without a programmer.

\subsubsection{Version Changes} \label{sssec:FWBootChanges}
This section describes changes made to the different release versions of firmware.  Minor updates
commited only to the repository and not released for public download may not be shown here.  In that
case, take a look at the repository logs to see what has changed.

\begin{center}
    \begin{tabular}{c|c|p{0.6\textwidth}}
        Revision & Date & Changes \\
        \hline
        0 & Feb. 14, 2013 & Initial revision \\
    \end{tabular}
\end{center}

\subsubsection{Bootloader Startup} \label{sssec:FWBootStartup}
When the bootloader starts up, it goes through a series of checks to see whether it should start the
application or stay in the bootloader.

If any checks turn up something that suggest the bootloader should not start the application, the
bootloader will turn on the yellow LED and print a message to the serial console stating the reason
why the bootloader is running.  The message is formatted as ``(N) Text'', where 'N' is one of the
following numbers corresonding to a check and ``Text'' is a textual explanation of the check.  This
format allows software to simply look for the number rather than having to parse the string to
determine why the bootloader is running.  The number is always 2 digits, so an example message would
look like ``(01) Bootloader pin set''.  The message is followed by a carriage return.

\begin{enumerate}
  \item \textbf{Is the bootloader pin set?} \\
    The board has a jumper on it going into pin 6 (PD4) that can be shorted to tell the bootloader
    to not jump to the applcation.  This is useful for recovering from an application that will
    not start correctly.
  \item \textbf{Did the watchdog reset the application?} \\
    If the watchdog resets the device, it should end up back in the bootloader so that the
    application is not stuck in a reboot loop.  The application can also purposefully reset the
    CPU by waiting for the watchdog to timeout.  See the \hyperref[ssec:FWWatchdog]{Watchdog}
    section for more info.
  \item \textbf{Is there no application on the board?} \\
    The bootloader stores the application's CRC and a key indicating that an application is
    programmed onto the device.  If the key is not present or incorrect, the bootloader will
    assume that no valid application is loaded.
  \item \textbf{Is the application's CRC bad?} \\
    The bootloader calculates the CRC of the application data stored in flash memory and compares
    that to the CRC stored in flash (which is calculated when the application is updated).  If the
    CRCs do not match, the bootloader will not start the application.
\end{enumerate}

Issuing the ``j'' command over the serial interface will tell the bootloader to jump to the
appication, ignoring the above checks.  The ``s'' command will reprint the status message described
above.

If the bootloader does not start up the application, it will instead set up the UART module and the
command interface.  The bootloader will also enable the watchdog timer and enable interrupts.

\subsubsection{Bootloader Operation} \label{sssec:FWBootOperation}
If the bootloader does not jump to the application, it simply waits for incoming serial commands and
acts on them.

\subsubsection{Serial Commands} \label{sssec:FWBootCommands}
Below is a list of serial commands the bootloader recognizes.  See the
\hyperref[ssec:FWComm]{Communication} section for more information on how to talk to the
bootloader. The ``Syntax'' column shows how a valid command string is formed along with its
arguments. The command and it arguments are separated by a single space between each one.

\begin{longtable}{l|l|p{0.15\textwidth}|p{0.45\textwidth}}
    \centering
    Command & Name & Syntax & Description \\
    \hline
    \endhead
    crc & App CRC & crc & Calculate the 16-bit for the application and print it as a four-digit
    hexadecimal number. \\
    h & Help & h & Print of list of these commands with short help strings. \\
    v & Version & v & Print firmware version information. \\
    j & Jump & j & Jump to application. \\
    r & Reset & r & Reset device and stay in bootloader. \\
    ea & Erase App & ea yes & Erase the application from flash.  The first argument must be the
    word ``yes'' as a confirmation of the action. Prints a status code to indicate success. \\
    ee & Erase EEPROM & ee yes & Erase the onboard EEPROM.  The first argument must be the word
    ``yes'' as a confirmation of the action. Prints a status code to indicate success. \\
    pd & Page Data & pd \emph{offset checksum data} & Write \emph{data} to a temporary page 
    buffer, where it is stored before being programmed to flash with the ``pp'' command.  The
    \emph{offset} is the starting position in the buffer in which to put the \emph{data}.  The
    \emph{checksum} is calculated by adding all of the bytes in \emph{data}.  Prints a status
    code to indicate success. \\
    pp & Program Page & pp \emph{pagenum} & Program the flash page given by \emph{pagenum}
    with the data stored using the ``pd'' command.  The \emph{pagenum} parameter can range from
    0 to 223 for the ATMega328P.  The contents of the page are verified by comparing it to the
    data stored in the page buffer to make sure the flash ware written correctly.  Prints a
    status code to indicate success. \\
    wc & Write CRC & wc & Calculate the application's CRC and write it to a special spot in 
    flash.  Do this after all of the application pages were successfully written to complete the
    update.  The bootloader will calculate the application's CRC on startup and compare it to
    this value to make sure the app is valid before jumping to it.  Prints a status code to
    indicate success.  \\
    ps & Page Size & ps & Print the size of a single flash page, which is 128 on the ATMega328P.
    This is useful mainly for porting the bootloader to other devices.  Software can query this
    value to know how much data to load with the ``pd'' command.  The value is printed as 4
    hexadecimal digits.  \\
    pn & Number of Pages & pn & Print the number of flash pages availabe to the application,
    which is 224 on the ATMega328P.  This is useful mainly for porting the bootloader to other
    devices.  Software can query this value to know how many pages of data it must be able to
    handle.  The value is printed as 4 hexadecimal digits. \\
    s & Boot Status & s & Reprint the status message that appears when the bootloader starts
    up.  See the \hyperref[sssec:FWBootStartup]{Bootloader Startup} section for more info. \\
\end{longtable}

The first three commands are common to the bootloader and application and so are implemented in
\path{firmware/common/cmd.c}.  The rest are bootloader-specific and are implemented in
\path{firmware/bootloader/localcmd.c}.

Some of these commands return a status code to indicate what happened with the command.  The
possible codes are as follows.  The codes are printed as ``!00'' (exclamation point and two hex
digits) followed by a carriage return.

\label{tab:FWBootErrors}
\begin{center}
    \begin{tabular}{c|l|p{0.6\textwidth}}
        Code & Name & Description \\
        \hline
        00 & OK & No error; this is returned when the command executes successfully. \\
        01 & Argument Error & The command sent to the bootloader is missing a required argument.
        Verify that the arguments sent down are correct (see the list above) and they are are
        separated by a space. \\
        02 & Range Error & An argument is out of range and so is not valid.  This can happen, for
        example, when trying to write data to an offset outside of the page or when trying to
        program a page that is not in app space. \\
        03 & Mismatch Error & The command executed, but could not complete because an expected value
        was not found.  This can happen when a flash write fails or when a page checksum does not
        match the data. \\
    \end{tabular}
\end{center}

\subsubsection{Performing an Update} \label{sssec:FWBootUpdate}
A firmware update is performed using the serial commands given in the
\hyperref[sssec:FWBootCommands]{Serial Commands} section above.  In essence, the software talking to
the bootloader to do the update must parse the application's Intel hex file into a binary image of
the micontroller's memory and send that down to the bootloader in chunks to program the device.
When all of the data is sent, the software will finalize the update by telling the bootloader to
calculate and write the application's CRC to a special location at the end of flash.

Following is a basic outline of how to perform an update.  Anyone trying to write software to do
this will need to be familiar with the Intel hex file format.  There are many sources available
online that can help with this and the \hyperref[ssec:FWIntelHex]{Intel Hex Files} section above may
be of use.  This section assumes that the ATMega328P is being used, though one could conceivably
port the bootloader to a different device and follow a similar procedure.

\begin{enumerate}
  \item Make sure the microcontroller is running the bootloader.  To do this, run the ``v'' command
    to get version information and look for the word ``Bootloader'' (case sensitive).  If it is
    present, move to the next step.  If not, jump to it using the ``j'' command.  The version is
    printed during startup, so look for ``Bootloader'' again to see if the jump succeeded.
  \item Create a block of memory the size of the microcontroller's flash.  The ``ps'' and ``pn''
    commands are useful for doing this generically.  The page size of the ATMega328P is 128 bytes
    and it has 224 pages available to the application for 28KB total.  This will be referred to as
    the ``flash image''.  Initialize this so that every byte is 0xFF.
  \item Open the application's Intel hex file.  For each line, parse the record and build up the
    data for the flash image.  Remember that Data Records (type 00) are the only ones that contain
    actual flash data and that the Extended Segment Address Record (type 02) and Extended Linear
    Address Record (type 04) contain the upper portion of the flash address.  Be sure the validate
    the record's checksum and to make sure the address is within the app space (this is 0 to 0x6FFF
    for the ATMega328P).
  \item Erase the old application using the ``ea yes'' command.  The ``yes'' argument is required as
    a confirmation of the action.  It will return when the erase is complete, which may take a few
    seconds.  Move on if successful.
  \item Begin sending data to the bootloader.  Read the first 16 bytes from the flash image and send
    them using the ``pd'' command.  In this case, the \emph{offset} will be 0.  Add those 16 bytes
    together to get the \emph{checksum}.  The \emph{data} for the command is those 16 bytes
    concatenated into a string of their hex digits.  For example, if the data read from the flash
    image was \{0x00, 0x11, 0x22,\ldots, 0xEE, 0xFF\}, then the string would look like
    ``001122\ldots EEFF''. Send the command down with the arguments and look for the status code coming
    back.  If the status code indicates a problem, verify that the command was sent correctly and
    that the checksum is correct.
  \item Do the previous step 7 more times, increasing the \emph{offset} by 16 and reading the next
    16 bytes from the flash image each time.  This will have sent 128 bytes--a single page's
    worth--of data to the bootloader.
  \item Now that enough data was written to the bootloader to fill a page, program the page using
    the ``pp'' command.  The \emph{pagenum} parameter is 0 in this case since this is the first page
    being written.  Look for the status the bootloader prints to make sure the command executed
    successfully.
  \item Perform the previous three steps repeatedly while reading the next 16 bytes from the flash
    image, starting the \emph{offset} back at 0, and incrementing the \emph{pagenum} by 1 each time,
    until all of the flash data has been programmed.  Note that it is not necessary to program pages
    that have no data in them (all bytes are 0xFF).  The software can stop short if it knows where
    the program would end.  One way to do this is to find the last byte that is not equal to 0xFF
    and make the containing page the last one to be programmed.
  \item If the programming operations completed successfully, tell the bootloader to calculate a CRC
    for the application and write it to flash by sending it the ``wc'' command.  If the status code
    returned by it indicates success, then the update is complete.
  \item If the update has completed successfully, jump to the newly-programmed application by sending
    the ``j'' command.
\end{enumerate}

The Projector Controller software follows this procedure for performing an application update.  The
file \path{software/serialcomm.py} has the function \texttt{doFirmwareUpdate} that performs the
update.  It makes use of the class found in \path{software/flashimage.py} to parse the hex file and
store the data and uses the class in \path{software/pjcbootloader.py} to send the commands needed.
One familiar with Python can use this as a reference for updating application firmware.

\subsection{Application Specific} \label{ssec:FWApplication}
The application is what performs the actual controlling functions of the Projector Controller.  It
sets up and controls the microcontroller's IO pins and the various onboard devices.  More
information about these devices is available in the \hyperref[sec:Hardware]{Hardware} section.  The
\hyperref[ssec:MicroPinout]{Microcontroller Pinout} section lists the uses of the pins on the
ATMega328P device.

\subsubsection{Version Changes} \label{sssec:FWAppChanges}
This section describes changes made to the different release versions of firmware.  Minor updates
commited only to the repository and not released for public download may not be shown here.  In that
case, take a look at the repository logs to see what has changed.

\begin{center}
    \begin{tabular}{c|c|p{0.6\textwidth}}
        Revision & Date & Changes \\
        \hline
        0 & Feb. 14, 2013 & Initial revision \\
    \end{tabular}
\end{center}

\subsubsection{Application Startup} \label{sssec:FWAppStartup}
The following steps are performed when the application starts up in order to set up the needed
modules for operation.

\begin{enumerate}
  \item Light green LED to indicate the application is running.
  \item Start one-millisecond free-running timer.
  \item Set used digital IO pins to their proper input or ouput states.
  \item Initialize SPI module used to talk to MCP3301.
  \item Set up analog inputs and start conversion.
  \item Enable 250ms watchdog timer.
  \item Initialize UART module.
  \item Initialize command interface and register application commands.
  \item Enable interrupts.
\end{enumerate}

None of the external devices require an explicit setup sequence and so are immediately usable
assuming the IO ports on the microcontroller used to communicate with them are set up correctly.

\subsubsection{Application Operation} \label{sssec:FWAppOperation} 
The main task of the application is to control the fan speed while the lamp is running and shut the
lamp down if the temperature of the thermistor exceeds the programmed limit.  This is done by
running a state machine on a regular interval in which the state depends on the state of the lamp
and fan.  See the \hyperref[sssec:FWAppStateMachine]{State Machine} section for more information.
This state machine controls the yellow and red LEDs.

The application will also monitor the command interface for new commands as well as monitor the
digital and analog inputs.  The ADCs are read at 5Hz and the digital input is monitored once every
10ms.

\subsubsection{Free-Running Timer} \label{sssec:FWAppTimer}
The firmware uses Timer 0 to create a free-running millisecond timer.  Timer 0 is an 8-bit timer and
so does not have enough range to actually acheive a one-millisecond period.  Instead, it is set up
for a 100\textmu s period.  The timer will fire an interrupt when the period ends.  After the
interrupt fires 10 times, a counter will be incremented to indicate one millisecond of time.  This
interrupt routine is provided in \path{firmware/common/freetimer.c} and \path{freetimer.h} along
with a delay routine and macros to check if a given amount of time has expired.

\subsubsection{Serial Commands} \label{sssec:FWAppCommands}
Below is a list of serial commands the application recognizes.  See the
\hyperref[ssec:FWComm]{Communication} section for more information on how to talk to the bootloader.
The ``Syntax'' column shows how a valid command string is formed along with its arguments.  The
command and it arguments are separated by a single space between each one.

Command arguments are optional.  The commands with arguments will set some value if the argument is
present; otherwise, they will print the current value of the command without changing anything.
Commands that set values will not save the values; use the ``sv'' command to do that.

\begin{longtable}{l|l|p{0.15\textwidth}|p{0.45\textwidth}}
    \centering
    Command & Name & Syntax & Description \\
    \hline
    \endhead
    crc & App CRC & crc & Calculate the 16-bit for the application and print is as a four-digit
    hexadecimal number. \\
    h & Help & h & Print of list of these commands with short help strings. \\
    v & Version & v & Print firmware version information. \\
    j & Jump & j & Jump to bootloader by resetting device. \\
    r & Reset & r & Reset device and restart application. \\
    a & ADCs & a & Print a list of ADC readings with one reading per line.  Each reading is a
    four-digit hexadecimal number.  The order of the readings are:  12V input feedback, ambient
    temperature sensor, and thermistor reading (this is sign-extended). \\
    dc & Duty Cycle & dc & Print the current fan duty cycle, which is proportional to its speed, as
    a float. \\
    dcl & Duty Cycle Low & dcl \emph{dutycycle} & Set the minimum duty cycle in percent for the PWM
    controlling the fan speed and print that as a floating point value.  Range is 0 to 100\%, but
    must be lower than or equal to the Duty Cycle High value.  Setting this below 30\% is not
    recommended since the fan may not run at such a low duty cycle. \\
    dch & Duty Cycle High & dch \emph{dutycycle} & Set the maximum duty cycle in percent for the PWM
    controlling the fan speed and print that as a floating point value.  Range is 0 to 100\%, but
    must be higher than or equal to the Duty Cycle Low value.  Setting this below 30\% is not
    recommended since the fan may not run at such a low duty cycle. \\
    le & Lamp Enable & le \emph{en} & Enable or disable the lamp and print a non-zero decimal value
    if the lamp is enabled or 0 otherwise.  The state of the lamp will be overriden by the Projector
    On input, so this is only useful for testing.  This also starts the control loop and
    fan control. \\
    lod & Lamp Off Delay & lod \emph{delay} & Set the time in seconds the application will keep the
    lamp on after being told to turn it off and print the delay value as a float.  Some LCD
    controllers disable their backlight while switching inputs.  This command allows users to
    overcome that behavior by waiting to see if the LCD controller turns the lamp back on. \\
    ft & Fan Off Temperature & ft \emph{offset} & Set the temperature, relative to ambient, at which
    the fan will turn off after cooling the lamp down.  Value is in degrees Celsius and is printed
    as a float.  As an example, if this value is 5.0 and the ambient temperature is
    27\textcelsius{}, then the fan would shut off at 32\textcelsius{}.  This takes effect only when
    the lamp was turned off; the fan is always on when the lamp is on.  Range is 0 to
    125\textcelsius{}. \\
    ot & Over-temp Limit & ot \emph{limit} & Set the temperature in degrees Celsius at which the
    lamp will shut down due to an over-temp condition and print the new limit as a float. Range is 0
    to 125\textcelsius{}. \\
    tt & Target Temperature & tt \emph{target} & Set the target temperature in degrees Celsius,
    which is the temperature the application will try to maintain by controlling fan speed.  The
    closer the actual temperature is to this value, the slower the fan will spin.  Prints the target
    temperature as a float.  Range is 0 to 125\textcelsius{}. \\
    er & Print Error & er \emph{clear} & Print the most recent error code from the device as a
    hexadecimal value.  See the \hyperref[sssec:FWAppErrCodes]{Error Codes} section for a list of
    possible return values.  If \emph{clear} is present and non-zero, the error code will be cleared
    so that future calls do not return the same code. \\
    sv & Save Settings & sv & Save settings to the built-in EEPROM memory.  See the
    \hyperref[sssec:FWAppStorage]{EEPROM Storage} section to see what is stored there. \\
    clp & CLoop P-Gain & clp \emph{gain} & Set the fan control loop's proportional gain value and
    print the value as a float. \\
    cli & CLoop I-Gain & cli \emph{gain} & Set the fan control loop's integral gain value and
    print the value as a float. \\
    cld & CLoop D-Gain & cld \emph{gain} & Set the fan control loop's derivative gain value and
    print the value as a float. \\
    cls & CLoop I-Seed & cls \emph{seed} & Set the fan control loop's integral seed and
    print the value as a float. The integral seed is the initial value of the integral tank. \\
\end{longtable}

Software should read back the printed value even when setting a value.  This is because some
commands have limits they will enforce on the input.  For example, the minimum duty cycle can be in
the range 0 to 100\%.  Trying to set it to, for example, 200\% will return 100\%.

The first three commands are common to the bootloader and application and so are implemented in
\path{firmware/common/cmd.c}.  The rest are application-specific and are implemented in
\path{firmware/app/localcmd.c}.

\subsubsection{Error Codes} \label{sssec:FWAppErrCodes}
The application will keep track of the most recent error that occurred and turn on the red LED when
it does.  The error is stored as a hexadecimal value and is retrievable with the ``er'' command.
If a numerical argument is given to the ``er'' command and that argument is non-zero, then the error
code will be cleared after the command executes.  Clearing the error code will prevent it from being
reported with future calls unless the error condition goes away and returns again later.  The red
LED will remain lit until the error condition goes away, at which point the LED will turn off.

The ``er'' command will print the error as a two-digit hexadecimal value, such as ``00''.

Here is a list of error codes the application can print.  In order to make a distinction between
application and \hyperref[tab:FWBootErrors]{bootloader error codes}, application errors will start
at 0x80.  The exception is the code 0x00, which indicates no error.

\begin{center}
    \begin{tabular}{c|l|p{0.6\textwidth}}
        Code & Name & Description \\
        \hline
        00 & OK & No error was recorded since startup or since the last error was cleared. \\
        80 & Over-temp & The thermistor temperature was higher than the stored temperature limit (use
        the ``ot'' command to get and set this). The lamp will be shut down immediately and the fan
        will continue to run as normal.\\
        81 & Thermistor Short & The thermistor input is shorted and so the application cannot determine
        the actual temperature it is controlling.  This is sensed by the ADC reading being near
        positive full-scale.  If the lamp was on, it will be shut down immediately and the fan will
        run at 50\% duty cycle for 30 seconds and then shut off. \\
        82 & Thermistor Open & The thermistor input is open, which could mean that no thermistor is
        connected.  This means that the application cannot read the correct temperature.  This is
        sensed by the ADC reading being near negative full-scale. If the lamp was on, it will be
        shut down immediately and the fan will run at 50\% duty cycle for 30 seconds and then shut 
        off. \\
    \end{tabular}
\end{center}

These errors will turn the lamp off if it is on when the error occurs.  The lamp cannot be turned
back on until the error condition clears.  The lamp is not turned back on automatically.

\subsubsection{Control Loop} \label{sssec:FWAppCLoop}
A control loop runs once every 2 seconds (0.5Hz) while the fan is on.  The input to the control loop
is the temperature read from the thermistor and the output is a duty cycle value used to control the
fan PWM.  The closer the actual temperature is to the target temperature (use the ``tt'' command to
set and get this), the more slowly the fan will spin.  Fans react slowly to changes in speed since
they take time to accelerate; this is why the control loop runs so slowly.

A basic control loop algorithm is implemented in \path{firmware/common/pidloop.c} and
\path{pidloop.h}.  The \hyperref[sssec:FWAppStateMachine]{application state machine} controls when
it runs.

\subsubsection{State Machine} \label{sssec:FWAppStateMachine}
The main control function of the application firmware is implemented as a state machine, in which
each state represents a different stage of control.  The application moves between states in
reaction to external inputs, error conditions, or after a certain amount of time.  Here are the
states used.

\begin{description}
  \item[Idle] \hfill \\
    The application is in this state when the lamp and fan are both off and there are no errors,
    meaning that nothing needs to be done.
  \item[Lamp Start] \hfill \\
    This state is entered when the lamp is first turned on.  This runs the fan at 50\% duty cycle
    for 2 seconds before starting the control loop.  This gives the fan a moment to start up and
    provides a good starting point for control.  This turns on the yellow LED.
  \item[Lamp Run] \hfill \\
    The lamp has started up and the control loop is now running.  The control loop runs once every 2
    seconds.
  \item[Lamp Off Delay] \hfill \\
    The lamp was told to shut off either from the serial console or via the Projector On input.
    This will wait for the delay time set by the ``lod'' command before actually turning the lamp
    off.  The lamp can be turned back on in this state, in which case the state machine will go back
    to the Lamp Run state.
  \item[Cooldown] \hfill \\
    The lamp has been shut down normally and the fan will remain on until the projector has cooled
    sufficiently.  This is controlled by the ``ft'' command.  This goes back to the Idle state when
    completed.  This will blink the yellow LED.
  \item[Overtemp Error Init] \hfill \\
    Turns on the red LED due to an overtemp error and sets the error code, then immediately moves on
    to the Overtemp Cooldown state.
  \item[Overtemp Cooldown] \hfill \\
    This works just like the Cooldown state except it does not allow the lamp to be turned back on.
    Transitions to the normal Cooldown state when the thermistor temperature is below the over-temp
    limit and turns off the red LED in the process.  This blinks the yellow LED.
  \item[Short Error Init] \hfill \\
    Turns on the red LED and sets the error code.  If the lamp was on, it will shut the lamp off and
    move to the Bad Thermistor Cooldown state; otherwise, it will move to the Bad Thermistor Idle
    state.
  \item[Open Error Init] \hfill \\
    Turns on the red LED and sets the error code.  If the lamp was on, it will shut the lamp off and
    move to the Bad Thermistor Cooldown state; otherwise, it will move to the Bad Thermistor Idle
    state.
  \item[Bad Thermistor Cooldown] \hfill \\
    Runs the fan at 50\% duty cycle for 30 seconds and then moves to the Bad Thermistor Idle state.
    Blinks the yellow LED.
  \item[Bad Thermistor Idle] \hfill \\
    Similar to the Idle state except the lamp cannot be turned on while in this state.  This state
    is used to wait for the thermistor error to clear before transistioning to the Idle state, at
    which point the red LED will be cleared.
\end{description}

The state machine is implemented in \path{firmware/app/control.c} and \path{control.h}.

\subsubsection{Fan Control} \label{sssec:FWAppFanControl}
The fan is controlled with a 25kHz PWM from pin 5 of the microcontroller, which is port PD3 and Timer
2's OC2B output.  Timer 2 is a 8-bit timer with a PWM module attached.  The PWM output is configured
with a 8:1 prescaler and a period of 100 counts.  This gives a control resolution of 1\%, which
should be more than adequate for this application.

The fan PWM code is implemented in \path{fimrware/app/fanpwm.c} and \path{fanpwm.h}.

\subsubsection{Input Debounce} \label{sssec:FWAppDebounce}
The Projector On input goes through a software debounce routine designed to account for possible
noise from the input.  The debounce routine essentially waits for the input to stabilize before
reporting its new state to the rest of the application.  The input is checked once every 10ms.
The state of the input must remain the same for 10 readings (or 100ms) before that new state is
reported.

The debounce algorithm is implemented in \path{firmware/common/debounce.c} and \path{debounce.h}.

\subsubsection{EEPROM Storage} \label{sssec:FWAppStorage}
Most of the values settable via serial commands are stored in the microcontroller's built-in
EEPROM.  The EEPROM storage will start with a key to indicate that data exists in the EEPROM, a size
field, and a version field to allow for new additions in future application updates.

The following values are stored in the EEPROM.  If that item is not found in EEPROM, then the given
default is used.

\begin{center}
    \begin{tabular}{l|l|c}
        Item Name & Type & Default Value \\
        \hline
        Control Loop P-Gain & float & 0.002 \\
        Control Loop I-Gain & float & 0.01 \\
        Control Loop D-Gain & float & 0 \\
        Control Loop I-Seed & float & 0 \\
        Minimum Duty Cycle & float & 30.0\% \\
        Maximum Duty Cycle & float & 100.0\% \\
        Target Temperature & float & 35.0\textcelsius{} \\
        Overtemp Limit & float & 45.0\textcelsius{} \\
        Lamp Off Delay & float & 0s \\
        Fan Off Temperature & float & 5\textcelsius{} above ambient \\
    \end{tabular}
\end{center}

\section{Software} \label{sec:Software}
The software is a simple applet that allows the user to monitor information read from the connected
Projector Controller and to change settings on it.  It also has a section for performing application
updates using the bootloader.  The software is written in Python and so can be run on Windows,
GNU/Linux, Mac OS X, and possibly other Unixes.  A prebuilt binary is available for Windows; Linux
and OS X users will need to go get Python and needed libaries, but this is not too hard.

This section is more focused on how the software is architected as opposed to what the various
buttons and controls do.  For info on the latter, see the \emph{Users Guide}.

\subsection{Tools Used} \label{ssec:SWTools} 
The software is written entirely in Python, which is what allows it to be cross-platform.  The
interface uses PySide, which is the official set of Qt bindings for Python.  The communication with
the board makes use of PySerial, an independent library for serial port access (the FT232R on the
board acts as a Virtual COM Port).

The software was written with Python 2.7 and needs PySerial and PySide.  Linux users should be able
to get these from their distributions' repositories.  Ubuntu users will need the following packages
(as of Ubuntu 12.10):

\begin{itemize}
  \item python
  \item python-serial
  \item python-pyside
\end{itemize}

Windows and Mac OS X users can download the needed packages online.  Python 2.7 is available for
both at \url{http://www.python.org/download/releases/2.7/}.  Windows users can download either the
32-bit (x86) or, if using a 64-bit version of Windows, the 64-bit (x86-64) version.

PySide installers are available from \url{http://qt-project.org/wiki/PySideDownloads}.  Follow the
links at the top of the page for the correct operating system.  Windows users just need to make sure
to match the correct Python version (2.7) and architecture.  That is, get 32-bit PySide for 32-bit
Python and 64-bit PySide for 64-bit Python.

OS X users will need to get both PySide and the corresponding version of Qt.  The important thing is
to get the versions of PySide and Qt that go together.  The downloads are under the headings
showing the version numbers (eg. ``PySide 1.1.1 / Qt 4.8'').  The links at the top of the page just
go to the main Qt website, so don't bother with those.

Getting PySerial is the same on both Windows and OS X.  The instructions are availabe on the
official PySerial site at \url{http://pyserial.sourceforge.net/pyserial.html}.  Following the
instructions under the ``From Source'' heading are probably the easiest since that involves just
downloading the compressed file, extracting it, and running the command shown on that page.  Windows
users will need a program that can handle \texttt{tar.gz} files; \href{http://www.7-zip.org/}{7-Zip}
works well.  Mac OS X and many Linux distributions can open those files natively.

To make sure everything is installed properly, open up a terminal or console window and navigate to
the \path{software/} directory.  Run \texttt{./main.py} (Windows users may need to run
\texttt{python main.py}) and see if the program starts up and can connect to the device.  If not,
make sure the packages are installed correctly and see if any errors are output to the console.
Note that it might be necessary to run the program as root (or as Administrator in Windows) in order
to open the serial port.  It may also be necessary to manually type in the serial port path due to
issues certain versions of PySerial seem to have with USB serial devices.
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

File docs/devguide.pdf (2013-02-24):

# Projector Controller

Developers Guide Rev. A
Author: Jesse DeGuire
Email: jesse.a.deguire+pjc@gmail.com Date: February 23, 2013

## Contents

1 Introduction | 4
2 Hardware | 6
3 Firmware | 18

4 Software | 34

## Revision History

This section describes revisions made to this document. Changes made to the hardware, firmware, or software are described in their respective sections.

Doc Revision | Date | Changes
A | Feb. 14, 2013 | Initial revision

## 1 Introduction

This document provides implementation details for the various pieces of the Projector Controller system. The information contain within will hopefully be useful for anyone who wishes to modify or tinker with the any part of the system or at least will satisfy an interested user’s curiosity. Anyone who is only looking to get the Controller running in his or her projector should instead consult the Projector Controller Users Guide.

This guide is divided up into a few sections. The Hardware section describes the components used on the board itself as well as the power requirements and capabilities of the board. The Firmware section contains information regarding the program flow of the bootloader and application firmwares used by the Projector Controller. This also contains documentation for the command interfaces used by both to communicate to the host PC as well as brief descriptions of many of the source code files. Finally, the Software section describes how the PC-side software communicates to the board. All sections will additionally state what tools were used in their development so that anyone can build and modify the various pieces.

### 1.1 Sources and Licenses

All source files used to create the board, software, and firmwares are available in a Git repository on GitHub at https://github.com/jdeguire/pjcontroller. The repository also contains datasheets for the hardware components and other reference material. This document will often reference paths within the repository. For example, the path firmware/common/uart.c should be read as “[\emph{location/to/which/repository/was/ cloned}]/firmware/common/uart.c”.

The firmware and software, the sources of which are located in the firmware/ and software/ directories in the aforementioned repository, are made available under the GNU Public License Version 3. A copy of the GPLv3 is provided in the file COPYING.txt in the repository root or online at http://www.gnu.org/licenses/.

This document, the Users Guide, their associated LATEX source files, and the board design files are all made available under the Creative Commons Attribution-ShareAlike 3.0 Unported License. The source files for the Developers Guide and Users Guide are available in the docs/tex/ directory. The board design files are found in hardware/pjc-kicad/. A copy of the Creative Commons BY-SA 3.0 license is provided in the file CCBY-SA3. 0legalcode.txt in the repository root or online at http://creativecommons.org/licenses/by-sa/3.0/.

Where attribution is required, it is sufficient to include a statement of reasonable visibility in the derived work or supporting documentation mentioning that the work is derived from this project and giving this author’s name. It would be appreciated if the statement also contained the URL, given above, for the version control repository.

Located in hardware/pjc-kicad/libs/ are two files SparkFun.lib and SparkFun.mod. These were converted into their current form for use with KiCad from the original Eagle libraries provided by SparkFun Electronics under the CC BY-SA 3.0 license. The latest such libraries can be found on GitHub at https://github.com/sparkfun/SparkFun-Eagle-Libraries. (https://github.com/sparkfun/SparkFun-Eagle-Libraries)

### 1.2 Open Source Hardware

As described above, all design and source code files for Projector Controller are available under licenses allowing one to “study, modify, distribute, make, and sell the design or hardware based on that design”. The project was developed using freelyavailable tools, most of which are also open source, lowering the barrier to accessing the design. Therefore, the author believes that the Projector Controller qualifies as Open Source Hardware as given in the Open Source Hardware Definition 1.0. The defintions is availabe from the Open Source Hardware Association at http://www.oshwa.org/definition/.

Note that the logo itself does not have a license associated with it, but the guidelines presented at http:

//www.oshwa.org/faq/ recommded its use. Any derived works which do not adhere to the definition of Open Source Hardware should remove the logo from any files which contain it.

## 2 Hardware

The hardware was designed using KiCad EDA, an open source (GPLv2) multi-purpose EDA tool available for various flavors of GNU/Linux, Windows, and OS X. Get KiCad from the official site at http://www.kicad-pcb.org/display/KICAD/Download+Kicad. (http://www.kicad-pcb.org/display/KICAD/Download+Kicad) If possible, download a Snapshot build as those contain additional features over the rather old stable release. Ubuntu users should use the Adam Wolf PPA given on that page.

Datasheets for the various components used are available in the repository under hardware/datasheets. The datasheets are provided for reference only and belong to their respective manufacturers.

### 2.1 Hardware Changes

This section lists the changes that have been made to the different board revisions over time. The revision is incremented when the board layout is changed and those changes are made into manufactured boards.

HW Revision | Date | Changes
A | Feb. 14, 2013 | Initial revision

### 2.2 Design Considerations

Becuase the Projector Controller will probably never acheive high-volume production, the main consideration was ease of assembly. When possible, the components used are of a large form factor (such as 1206 for resistors) and the footprints for surface-mount devices use long pads to make accessing them with a soldering iron easier. The board uses a socket for the 28-pin DIP microcontroller to allow easy replacement. These choices allow the board to be assembled by hand for small production runs and allow the user to more easily tinker with the board.

Though not a primary consideration, the board was also designed with an eye on power consumption. The board will be able to run certain componenets from USB power. USB provides 5V at 100mA by default, though a device can request up to 500mA. The USB interface device does not identify itself as a high-power device by default, so all 5V components will need to consume less than 100mA combined. The power consumption of the board is characterized in the Power Usage section.

### 2.3 Circuit Details

Following are desciptions of the different circuit pieces developed for the board. The reader of this section may want to have the schematic handy in order to follow along. The titles of the descriptions will closely match the text titles used in the schematic for the different circuits.

### 2.3.1 Microcontroller

The heart of the Projector Controller is an Atmel ATMega328P 8-bit microcontroller. The MCU has 32KB of flash, 4KB of which is used for the bootloader, 2KB of RAM and several useful peripherals, such as 10-bit ADCs, SPI, PWM outputs, timers, and quite a few IO pins. The MCU is a 28-pin DIP package which will insert into a socket on the board, making removal and replacement easy.

An ECS 20MHz crystal oscillator provides the CPU clock.

Three LEDs–red, yellow, and green–are provided to allow the firmware to convey diagnostic information while running. The LED outputs also control low-side drivers, which is explained in the Relay and LED Outputs description.

A jumper, pulled low, is connected to an IO pin on the microcontroller. Shorting the jumper sets the state of that IO pin high. The state of this pin is read by the bootloader when it first starts up. If the pin state is high, the bootloader will not start the application and will instead stay in the bootloader. This allows one to recover from a problematic application that fails on startup.

### 2.3.2 USB/UART IO

The Projector Controller communicates with the outside world by utilizing an FTDI FT232R UART to USB interface chip. The chip connects to a standard USB Mini-B connector on one side and the microcontroller’s logic-level UART pins on the other, acting as a translator between the two protocols. The chip presents itself to the connected USB host as a virutal COM port to allow one to communicate with the board using a terminal program such as TeraTerm or HyperTerminal. Newer operating systems should have drivers for the device pre-installed; however, drivers are also available from http://www.ftdichip.com/FTDrivers.htm. Windows users may need to download the needed drivers from Windows Update.

The circuit used is similar to the one presented in Section 6.3 of the FT232R datasheet. Because the 5V components on the board can be powered over USB (see the Main Power Input description), this device needs to comply with USB suspend mode requirements. When the USB host enters USB Suspend Mode, the attached device must power down and draw less than 2.5mA of current. To facilitate this, pin 14 of the FT232R defaults to an active low “Power Enable” pin. When entering USB suspend mode, that pin will be pulled high by the 10kΩ pullup and will “turn off” the Diodes Inc. DMP2215L P-channel MOSFET, essentially cutting power to the rest of the 5V system. When the USB host exits Suspend Mode, the FT232R will pull the line low to re-active the MOSFET. The datasheet for the MOSFET give a current rating of 2A at 70℃.

The FT232R defaults to USB low-power mode, which requires that the device in question draw at most 100mA. Given a thermal resistance of 115℃/W and on-resistance of 100mΩ, a 100mA draw would raise the MOSFET’s temperature over ambient by

∆T = P ∗ Rth

= (I

2R) ∗ Rth

= (0.01 ∗ 0.1) ∗ 115
∆T = 0.115◦C

Both the USB connector and the FT232R are fine-pitch parts, the latter using a 28-pin SSOP package. These two are probably the most challenging parts on the board to solder, so they will need to be placed appropriately to help make soldering them a bit easier.

### 2.3.3 Main Power Input

The board accepts a nominal 12V supply through a screw terminal rated up to 7A input, which is much higher than the continuous current the board is designed for (see the Power Usage and Fan Control descriptions).

To help prevent damage from occurring due to hooking up the power supply backwards, a Rohm Semiconductor RSQ045N03 N-channel MOSFET is placed across what is normally the current return path and the gate connected through a 3.3kΩ resistor to the normally-positive side. When the power is connected correctly, the gate is pulled up to 12V and the FET is fully-on. When the power is connected backwards, the gate is pulled low and the MOSFET is turned off. The MOSFET has a steady-state current rating of 4.5A and a peak rating of 18A. The device also has a max on-resistance of 38mΩ. With a maximum temperature of 150℃ and a thermal resistance of 100℃/W, at 40℃ ambient¹
the maximum power dissipated by the device is given by

1The inside of a projector will certainly be warmer then the outside air temperature, with the actual ambient temperature depending on where inside the projector the board is placed. The chosen 40℃ value is probably on the warmer side of normal, but provides some safety margin. This is used as the ambient temperature throughout this document.

Pmax =

Tmax − Tamb

Rth

=

150 − 40
100
Pmax = 1.1W

which gives a maximum current of

I =

r
P

Rth

=

r
1.1
0.038
I ≈ 5.38A

meaning that the device is limited by the specified limit of 4.5A rather than by heat.

The 5V supply comes from an ST Microelectronics L78M05C linear regulator fed from the 12V supply. The device is rated to output currents up to 0.5A and features thermal overload shutdown that will cut output power in order to protect itself. The device has a maximum temperature of 150℃ and a worst-case thermal resistance of 100℃/W, assuming minimal heatsinking.

As previously stated, the 5V devices are designed to draw at most 100mA so that they can be powered via USB. A selector switch allows the user to select between USB and the 5V regulator as the 5V power source. This is useful in the case the user needs to remove the board from the projector and connect it to the PC for configuring it. The switch is rated for 6VDC at 300mA or 30VDC at 100mA. The output side of the selector switch has a Cooper Bussmann PTS120630V012 PTC fuse rated at 120mA at 23℃. Using the derating curve in the datasheet shows that the hold current drops to about 100mA at an ambient temperature of 40℃. A Diodes Inc. S1M-13-F diode, rated at 1A continuous and 1000V reverse DC voltage, is placed between the regulator and 12V input to prevent USB current from back-feeding through the regulator. If only a USB cable is connected to the board, only the 5V devices will be powered.

Given a worst-case thermal resistance of 100℃/W and nominal voltage drop of 7V, a 100mA draw would raise the device’s temperature over ambient by

∆T = P ∗ Rth
= (V ∗ I) ∗ Rth
= (7 ∗ 0.1) ∗ 100
∆T = 70◦C

Some heatsinking can be provided by englarged pads or copper pours on the board.

### 2.3.4 Programming and Reset

The ATMega328P microcontroller can be reprogrammed using a standard 10-pin AVR ISP header. The pinout used should work with most, if not all, external programmers. The microcontroller is programmed through the SPI lines while the device is held in reset. The 5V pin on the header allows the board to power the programmer so that the logic signals are at the correct voltage levels. If the board is powered via USB, care must be taken to not exceed a total of 100mA draw when powering the programmer in this manner. See Power Usage for more information.

The user can reset the board using a push button connected to ground. The device’s RESET pin is active low, so it is normally pulled high and pressing the button creates a connection to ground.

### 2.3.5 Analog Inputs

Two of the microcontroller’s analog inputs are used to monitor the 12V input and ambient temperature from an Analog Devices TMP36 temperature sensor. The microcontroller’s analog inputs are 10-bit single-ended ADCs.

The 12V input is divided down using a simple resistive divider in an approximate 3:1 ratio, meaning that the input into the ADC is about 1/4 the actual voltage. More specifically, to determine the actual voltage on the 12V input, multiply the ADC voltage by 4.03.

The TMP36 “F Grade” part used here has a worst-case accuracy of ±3℃. At 0℃ the device outputs 500mV and the output changes by 10mV/℃.

### 2.3.6 Relay and LED Outputs

Four 12V outputs are provided to control external devices. The outputs are controlled using two ON Semiconductor NUD3124DMT1G dual low-side drivers. The drivers are meant to be single-chip solutions for driving small motors and relays and so include a flyback diode and gate resistor.

The 4 connectors are 2-pin TE Connectivity Mini CT series connectors, which are 1.5mm pitch and rated for 2A maximum. The LED connectors will be grouped together and the relay connector separated a bit to help differentiate them.

Three of the driver outputs are controlled by the three LED outputs on the microcontroller (see Microcontroller description). The user can connect external LEDs to these outputs and mount them to the projector’s chassis so that the firmware’s diagnostic signaling is visible from outside the projector. The outputs provide 12V power, so the user will need to use an appropriate current-limiting resistor with the external LED. Alternatively, electronics stores sell LED packages with the proper resistor built in. The current-limiting resistors for the onboard LEDs also act as pulldowns for these outputs.

The fourth output is used as a lamp enable output and can be used to turn on, for example, an external relay coil which in turn turns the lamp on. This output has a 10k pulldown on it.

The high side of each output has a Cooper Bussmann PTS120630V012 PTC fuse rated at 120mA at 23℃. Using the derating curve in the datasheet shows that the hold current drops to about 100mA at an ambient temperature of 40℃. Given a thermal resistance of 329℃/W and worst-case on-resistance of 1.1Ω, both outputs drawing 100mA would raise the driver’s temperature over ambient by

∆T = P ∗ Rth

= (I

2R) ∗ Rth

= (0.04 ∗ 1.1) ∗ 329
∆T ≈ 14.5

◦C

### 2.3.7 Fan Control

A single Molex 4-pin fan header is provided for connecting a standard PWM-controlled PC fan. The connector is rated at 4A max per contact. The Sense output, which acts as a tachometer signal from the fan, is not used. 12V power is controlled by an Infineon BSP762T high-side driver. The driver has a worst-case on-resistance of 200mΩ. With a maximum temperature of 150℃ and a thermal resistance of 95℃/W, at 40℃ ambient the maximum power dissipated by the device is given by

Pmax =

Tmax − Tamb

Rth

=

150 − 40
95
Pmax ≈ 1.15W

which is below the rated absolute maximum of 1.5W and therefore gives a maximum current of

I =

r
P

Rth

=

r
1.15
0.2
I ≈ 2.4A

which matches the typical load current (IL(nom)) provided in the datasheet. Note that the on-resistance value used will occur only when the device is operating at its max junction temperature; the on-resistance, and therefore temperature, will usually be much lower. Users will be instructed to draw 2A max.

The driver has a thermal shutdown feature to protect the device in over-current or short circuit conditions. The device will turn the output off when in thermal overload and turn it back on when it has cooled sufficiently. In the case of short circuit, the driver will repeatedly turn off and back on with a repetitive short circuit current of 7A. The driver is not designed to continuously operate in this state, so the user will need to take care to not leave the output shorted.

The PWM output signal is supplied from one of the microcontroller’s 8-bit PWM outputs. According to the Intel 4-pin fan specification (available in the /hardware/datasheets directory of the repository), the nominal PWM output is 25kHz. The PWM signal goes through a TI SN74LVC1G07 non-inverting open-drain buffer since the fan pulls up the signal internally. The buffer has a max switching time of 3.5ns, which is far faster then required by the PWM signal. The Intel fan spec recommends a current sink capability of 8mA, though the maximum current a fan is allowed to source is 5mA. The recommended max for the buffer is 32mA (the absolute max is 50mA), so a user could theoretically control 4 fans using splitters assuming each fan sources less than the recommended current sink capability of the controlling device.

If the connected fan does not have a PWM input signal (standard PC 3-pin fan), the Projector Controller will still provide basic on/off control with the high-side driver.

The driver input and buffer input signals each have a 10kΩ pulldown.

### 2.3.8 Temperature Input

Temperature is read using a Vishay NTCALUG02A103G 10k (±2% at 25℃) thermistor, which is enclosed in a ring terminal for easy mounting in the projector. The ring terminal accepts a metric M3 screw. The user will normally want to place the thermistor as close to the monitored object, usually the LCD panel, as he or she can. The user may need to try a few locations to find the best one.

The thermistor input is a 2-pin JST PH Series connector, which is 2.0mm pitch and rated for 2A maximum.

The equation for getting the temperature from a thermistor is the Steinhart-Hart equation, which is

T =

1
A + B ln( RT
R25

) + C ln²
(

RT
R25

) + D ln³
(

RT
R25

)

− 273.15 where RT /R25 is the ratio between the thermistor’s actual resistance and its reference resistance (10kΩ in this case). The basic equation gives the result in Kelvin, so 273.15 is subtracted to convert that to Celsius. To get the temperature, it is necessary to determine the thermistor’s actual resistance and that can be done using the voltage going into the ADC.

The ADC is a Microchip MCP3301 differential SPI ADC that returns data in 13-bit two’s complement representation. The positive input to the ADC, IN+, is the output of a voltage divider formed by the thermistor and a 10kΩ resistor. The ADC has a separate reference voltage input, VREF , and the input range is ±VREF . To take advantage of the full 13-bit scale, a voltage divider with two 10kΩ resistors splits the 5V input in half and the resulting 2.5V is fed into both the VREF and IN− inputs. If the thermistor is 25℃, it will also be at 2.5V and so the ADC reading will be 0. The ADC reading will be negative if the thermistor is colder than 25℃ and positive if warmer. To get the actual voltage going into the ADC positive in put, convert the ADC reading to voltage (remember to sign-extend the reading) and then add 2.5V to it.

Note that if the thermistor is not connected, the voltage at the ADC should be 0 and so the reading should be negative full-scale (-4096). Conversely, if the thermistor input is shorted, then the voltage should be around 5V and so the reading should be positive full-scale (4095). However, the ADC is not perfect and so such conditions may be close to, but not exactly, the full-scale conditions.

The thermistor’s actual resistance can now be calculated with

RT =

R2 ∗ Vin

VADC

− R2

which is just the standard resistor divider equation solved for R1 (which is RT in this case). To get the ratio between the actual resistance and the reference resistance required by the Steinhart-Hart equation, the above equation can be divided by R25. Doing that and plugging in the appropriate values for Vin and R2 yields

RT

R25

=

10k∗5
VADC

− 10k

R25

=

50k
VADC

− 10k
10k
RT

R25

=

5

VADC

− 1

Notice that when the ADC reading is at negative full-scale (-4096 counts), VADC will be zero and so will cause a divide by zero error. As mentioned above, this happens when the thermistor is not connected and is an abnormal condition. To avoid the divide by zero problem, look for the negative full-scale reading and treat that as a special case. One possible solution is to clamp the input range to ±4095.

The cofficients for the Steinhart-Hart equation come from a Microsoft Excel spreadsheet on Vishay’s website at http://www.vishay.com/resistors-non-linear/curve-computation-list/. The spreadsheet for the NT-CALUG02A103G is available in the repository at /hardware/datasheets/VishayThmCalc.xls. The coefficients are on the RTCOEF page of the spreadsheet and are

A = 0.0033540164
B = 0.0002565236
C = 2.605970e − 6
D = 6.329261e − 8

These coefficients and the previous equation provide enough information to evaluate the Steinhart-Hart equation.

### 2.3.9 Projector On Input

The controller card for the projector’s LCD panel also controls the LCD’s backlight and will output a 5V or 12V signal to a backlight inverter to turn it on. Since the projector discards the backlight in favor of a high-power lamp, the Projector Controller has an input for that backlight signal and will use that for the similar purpose of turning on the lamp. The input connector is a 3-pin TE Connectivity Mini CT series connector, which is 1.5mm pitch and rated for 2A maximum. A 3-pin connector was used to differentiate it from the output connectors; the middle pin is not used.

The used connector pins go to the input of a Vishay VOM618A-4T opto-isolator. The opto has a minimum current transfer ratio (gain) of 160% when the current through the LED is 1mA. The output is a collector-emitter junction with the LED acting as the base of a transistor, so if the forward current through the LED is 1mA then the collector current will be 1.6mA (assuming the device is not saturated). The LED on the opto can handle a reverse voltage of 6V, so the user needs to be careful when connecting an input greater than that and make sure to not connect it backwards.

The collector of the opto is connected to 5V and the emitter connects to the microcontroller input pin and a 20kΩ pulldown, making the input active-high. With a typical collector-emitter saturation voltage of 0.12V (max is 0.4V), the collector current is

IC =

Vin − VCESat
RL

=

5 − 0.12
10k
IC = 0.244mA

so the LED forward current times the current transfer ratio must be greater than 0.244mA in order to drive the opto in to saturation. This is much lower than the maximum allowed collector current of 50mA.

Between the positive input pin and the anode of the LED is a 3.3kΩ current-limiting resistor. An LCD controller board with a 5V backlight enable signal will, with a typical LED forward voltage of 1.1V, need to be capable of supplying

IF =

Vin − Vf
RI

=

5 − 1.1
3.3k
IF = 1.18mA

of current. This is very close to the test current at which the opto’s transfer ratio is rated. Using an ambient temperature of 40℃ derates the ratio to 90%, according to Figure 9 on page 5 of the datasheet, giving a minimum ratio of 1.44. This make the theoretical collector current 1.70mA, driving the opto well into saturation. Performing similar math for a 12V input shows that it will need to be able to supply about 3.3mA of current and will provide a theoretical collector current of 4.75mA. Doing the same math, but with VF at the max of 1.6V, shows that a 5V backlight signal will supply about 1mA with a theoretical collector current of 1.44mA and a 12V signal will supply 3.15mA with a collector current of about 4.53mA. In short, LCD controller boards that provide a 5V or 12V backlight signal should have no trouble driving the opto into saturation and should be able to do so while supplying only a small amount of current.

Future LCD controller boards, however, could have a 3.3V or lower backlight control signal. Doing the above math again with a 3.3V signal yields an LED forward current of

IF =

Vin − Vf
RI

=

3.3 − 1.1
3.3k
IF = 0.67mA

when using the typical LED forward voltage rating. Because the current is below the 1mA test current used by the datasheet, a additional derating of the current transfer ratio needs to be applied. Figure 11 on page 5 of the datasheet shows a derating of about 75% at 25℃ ambient. Applying that to the already-derated current transfer ratio of 1.44 gives 1.08. This means that a 3.3V input will typically have a theoretical collector current of 0.72mA. This is 3x higher than the actual collector current, which should easily drive the opto into saturation. Doing the same math with the max forward voltage of 1.6V gives a forward current of 0.5mA for a collector current of 0.54mA. This is a bit over twice the actual collector current, so the opto should still be driven into saturation.

It should be noted that orignially a more standard zener diode circuit was considered. However, zener diodes appeared to be rated with a 5mA current. This would mean that more current is required from LCD controller boards that output their backlight signals to this board. Drive specificatons are rarely, if ever, available for LCD controller boards so it was decided to aim for a lower current draw, which the VOM618A allows since its test current is 1mA.

### 2.3.10 Mounting Holes

The Projector Controller will have one mounting hole on each of its four corners. The holes have a 4mm inner diameter and 10mm outer diameter for screw head clearance. This is the same size used for PC motherboards, so standoffs and screws that come with PC cases should be useable with this board. The holes will accommodate either M3 metric screws or 6-32 standard UTS screws.

### 2.4 Power Usage

The following tables lists the current draw of the different components on the board. When possible, the values used are the worst-case useage given in the data sheet; actual usage should normally be lower. The device has 5V and 12V power, so multiplying the current given in the table by its voltage input will give the power used.

Component | Current (mA) | Notes
5V Components
ATMega328P Active Current | 23 | See Note below
ECS CSM-3X 20MHz Crystal | 0.02 | Derived from “Drive Level” rating
FT232R Operating Current | 15 | Powered only from USB VBUS
FT232R USB PWREN Current | 0.5 | Powered only from USB VBUS
12V Feedback Divider | 0.9 | R1 = 10kΩ, R2 = 3.3kΩ
TMP36 Supply Current | 0.05
BSP762T Input Current | 0.015 | Current at IN pin while device is on
MCP3301 VREF Current | 0.15 | Current at VREF while clocking data
MCP3301 Operating Current | 0.45
MCP3301 2.5V Divider | 0.25 | R1 = R2 = 10kΩ
Thermistor Input Current | 0.5 | Worst case is shorted thermistor
VOM618A-4T Collector Current | 0.25 | Assumes VCE = 0
Green LED | 6.1
Yellow LED | 2
Red LED | 1.3
5V, 10kΩ Pulldowns (4) | 0.5 x4
5V, 10kΩ Pullups (2) | 0.5 x2
Total | 53.485
12V Components
5V Component Draw | 53.485 | See above
L78M05C Quiescent Current | 6
BSP762T Operating Current | 1.3
Total | 60.785

Note: Values were taken from Section 30.7 of the datasheet and includes all peripherals and programming current but not external IO. This assumes a 5.0V input voltage and 20MHz clock input.

Any external 5V devices connected to the Projector Controller, including a board-powered ISP programmer, must keep the total current draw under 100mA. Given the total shown above, external devices can use up to 46mA or so.

In addition to the loads shown here, the 12V supply also needs to be able to handle the external fan and 4 outputs. Therefore, the user will need to determine the current draw of his or her choosen components and size a power supply that can handle those plus another 61mA for this board.

### 2.5 Microcontroller Pinout

Following is a table showing how the pins on the microcontroller are used and their net names on the schematic, if applicable.

Pin # | Pin Name | Net Name | Description
1 | (PCINT14/RESET) PC6 | RESET | Active-low CPU reset line
2 | (PCINT16/RXD) PD0 | UART RX | UART receiver input
3 | (PCINT17/TXD) PD1 | UART TX | UART transmitter output
4 | (PCINT18/INT0) PD2 | FAN EN | Fan power enable
5 | (PCINT19/OC2B/INT1) PD3 | FAN PWM | 25kHz fan control PWM signal
6 | (PCINT20/XCK/T0) PD4 | 〈None〉 | Bootloader enable pin
7 | VCC | 〈None〉 | Main supply input
8 | GND | 〈None〉 | Ground
9 | (PCINT6/XTAL1/TOSC1) PB6 | 〈None〉 | 20MHz crystal oscillator input
10 | (PCINT7/XTAL2/TOSC2) PB7 | 〈None〉 | 20MHz crystal oscillator input
11 | (PCINT21/OC0B/T1) PD5 | LEN EN RED | Red LED enable
12 | (PCINT22/OC0A/AIN0) PD6 | LED EN YELLOW | Yellow LED enable
13 | (PCINT23/AIN1) PD7 | LED EN GREEN | Green LED enable
14 | (PCINT0/CLKO/ICP1) PB0 | LAMP EN | Lamp relay enable
15 | (PCINT1/OC1A) PB1 | 〈Unused〉 | Not used
16 | (PCINT2/OC1B/SS) PB2 | ADC CS | SPI ADC chip select
17 | (PCINT3/OC2A/MOSI) PB3 | MOSI | SPI master output
18 | (PCINT4/MISO) PB4 | MISO | SPI master input
19 | (PCINT5/SCK) PB5 | SCK | SPI clock
20 | AVCC | 〈None〉 | Analog suppy input
21 | AREF | 〈None〉 | Analog reference voltage
22 | GND | 〈None〉 | Ground
23 | (PCINT8/ADC0) PC0 | AVA 12V FB | 12V supply feedback
24 | (PCINT9/ADC1) PC1 | ANA AMBIENT | Ambient temperature reading
25 | (PCINT10/ADC2) PC2 | PROJECTOR ON | Projector on input
26 | (PCINT11/ADC3) PC3 | 〈Unused〉 | Not used
27 | (PCINT12/ADC4) PC4 | 〈Unused〉 | Not used
28 | (PCINT13/ADC5) PC5 | 〈Unused〉 | Not used

### 2.6 Connector Pinout

The following tables gives the functions of the pins on each connector. Pin 1 on through-hole connectors can be found by looking for the square solder pad around the through-hole. The USB connector is the only surface mount connector and pin 1 is denoted by a small circle next to the pin.

CON1: Communication (USB Mini-B)

Pin # | Description
| 1 | VBUS
| 2 | D-
| 3 | D+
| 4 | ID (Not Used)
| 5 | GND

CON2: Projector On Input (Mini CT 3-pin)

Pin # | Description
1 | Input positve
2 | Not Used
3 | Input Negative

CON3: Thermistor (JST PH 2-pin)

Pin # | Description
1 | 5V to thermistor
2 | Voltage from thermistor to ADC

CON4: 12V Input (Screw Terminal)

Pin # | Description
1 | 12V
2 | Ground

CON5: Fan Output (4-pin PC Fan Connector)

Pin # | Description
1 | Ground
2 | 12V
3 | Sense (Not Used)
4 | Control (PWM)

CON6: External Red LED (Mini CT 2-pin)

Pin # | Description
1 | 12V
2 | Ground

CON7: External Yellow LED (Mini CT 2-pin)

Pin # | Description
1 | 12V
2 | Ground

CON8: AVR ISP Header (10-pin Shrouded)

Pin # | Description
1 | MOSI (SPI Out)
2 | VCC (5V)
3 | LED/NC (Not Used)
4 | Ground
5 | Reset
6 | Ground
7 | SCK (SPI Clock)
8 | Ground
9 | MISO (SPI In)
10 | Ground

CON9: External Green LED (Mini CT 2-pin)

Pin # | Description
1 | 12V
2 | Ground

CON10: Lamp Relay Enable (Mini CT 2-pin)

Pin # | Description
1 | 12V
2 | Ground

JP1: Bootloader Enable Jumper

Pin # | Description
1 | Jumper Pin 1
2 | Jumper Pin 2

### 2.7 Conversion Formulas

The conversion formulas for the analong inputs discussed earlier are available here as well for convenience.

2.7.1 12V Feedback

VADC =

5 ∗ Counts
1024
VF B = VADC ∗ 4.03

### 2.7.2 Ambient Temperature

VADC =

5 ∗ Counts
1024
TAmb = 100 ∗ (VADC − 0.5)

### 2.7.3 Thermistor Temperature

The MCP3301 is a signed 13-bit ADC, so the reading must be sign-extended first. Notice that a reading of -4096 will cause a divide by zero error with these formulas. This indicates a disconnected thermistor and so is an abnormal condition that the software or firmware will need to look out for. One way to handle this is to clamp the input to ±4095 and handle -4096 as a special case.

VADC =

2.5 ∗ Counts
4096

+ 2.5

R =

5

VADC

− 1

T =

1
A + B ln(R) + C ln²
(R) + D ln³
(R)

− 273.15

where

A = 0.0033540164
B = 0.0002565236
C = 2.605970e − 6
D = 6.329261e − 8

## 3 Firmware

The onboard ATMega328P has two different firmwares on it. The first is a small bootloader that must be programmed on using an external programming device. A 10-pin header is provided onboard for this purpose. The bootloader is reponsible for programming application code into flash, allowing field updates without the programming device. and to make sure a functional application is present before handing over control to it. The second firmware is the actual application code. This is programmed on by the bootloader and is what actually does the projector controlling.

This section will describe functionality common to each firmware and then delve into the functions specific to each. First is information on how to build and program the firmwares onto the board.

### 3.1 Tools Used

The firmware was developed in various versions Ubuntu Linux with the current one as of this writing being version 12.10 Quantal Quetzal. The applications listed should be available on other distributions (or they can be built from source), but they may use different package names from what is given here.

The firmwares use the AVR GCC cross-compiler, which is at version 4.7 as of this writing, with the associated LibC and Binutils packages. AVRDUDE is used to program the built firmware onto the board. Building and programming the firmware is handled by the SCons build tool, which itself requires Python 2.4 or higher.

On Ubuntu 12.10, the following packages need to be installed to get everything:

- gcc-avr
- binutils-avr
- avr-libc
- avrdude
- scons

The scons package should also grab the needed Python package. If not, then that will need to be installed as well.

Windows users can use Atmel Studio, which is a free IDE provided by Atmel which also includes the needed toolchain. The IDE is available on Atmel’s website at http://www.atmel.com/tools/atmelstudio.aspx?tab=overview. (http://www.atmel.com/tools/atmelstudio.aspx?tab=overview) Using the IDE itself would require one to create two projects, one each for the bootloader and application, for the IDE since they are not provided here. Another possibility is to install SCons for Windows and Python alongside the IDE and build using SCons. The SCons Windows installer is available on the SCons website at http://www.scons.org/download.php. SCons should be able to find the toolchain as long as it is in the Windows PATH.

### 3.2 Building With SCons

SCons is a build system (essentially a replacement for GNU Make) written in Python. The build scripts themselves are special Python files. In the firmware/ is a file called SConstruct. This is the top-level build script and contains settings that are used by both the application and bootloader, such as include file paths and some compiler options. The firmware/bootloader/ and firmware/app/ directories each contain a file called SConscript. These are called from the SConstruct file and contain options specific to the app or bootloader, such as the output file path, source files, and so on. The files themselves are commented so that anyone who wishes to modify build options can at least figure out what needs to change in the files.

The SCons documentation is very good and even those inexperienced with SCons can set up a build just by following the documentation. The documentation is available on the SCons website at http://www.scons.org/doc/production/HTML/scons-user/index.html (http://www.scons.org/doc/production/HTML/scons-user/index.html) and a wiki is available at http://www.scons.org/wiki/.

To use SCons, open up a command-line window or terminal and navigate to the location of the SConstruct file, which is firmware/. Now run scons 〈command〉, where 〈command〉 is one of the following:

build-bootloader :
Build the bootloader using AVR GCC and output the resulting Intel hex file to firmware/bootloader/ output/pjc-bootloader.hex.

write-bootloader :
Write the bootloader to the microcontroller using AVRDUDE and a compatible programmer (see below). The bootloader must have been built using build-bootloader for this to work.

read-flash :
Read the entire contents of the microcontroller’s flash memory and output the contents as an Intel hex file to firmware/bootloader/output/pjc-flash-image.hex.

erase-device :
Erase the device’s flash, EEPROM, and lock bits, but not its fuse bits.

write-fuses :
Write the proper fuse and lock bits to the device. This should be done the first time a new device is programmed.

build-app :
Build the application using AVR GCC and output the resulting Intel hex file to firmware/app/output/ pjc-app.hex.

Multiple commands can be executed at once by putting more than one on the command line. For example, running scons build-bootloader write-bootloader will compile the bootloader and, if successful, program it to flash.

The actions of these commands are defined in the SConscript files. For example. the values of the fuse bits programmed using the write-fuses command are defined in the firmware/bootloader/SConscript file.
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

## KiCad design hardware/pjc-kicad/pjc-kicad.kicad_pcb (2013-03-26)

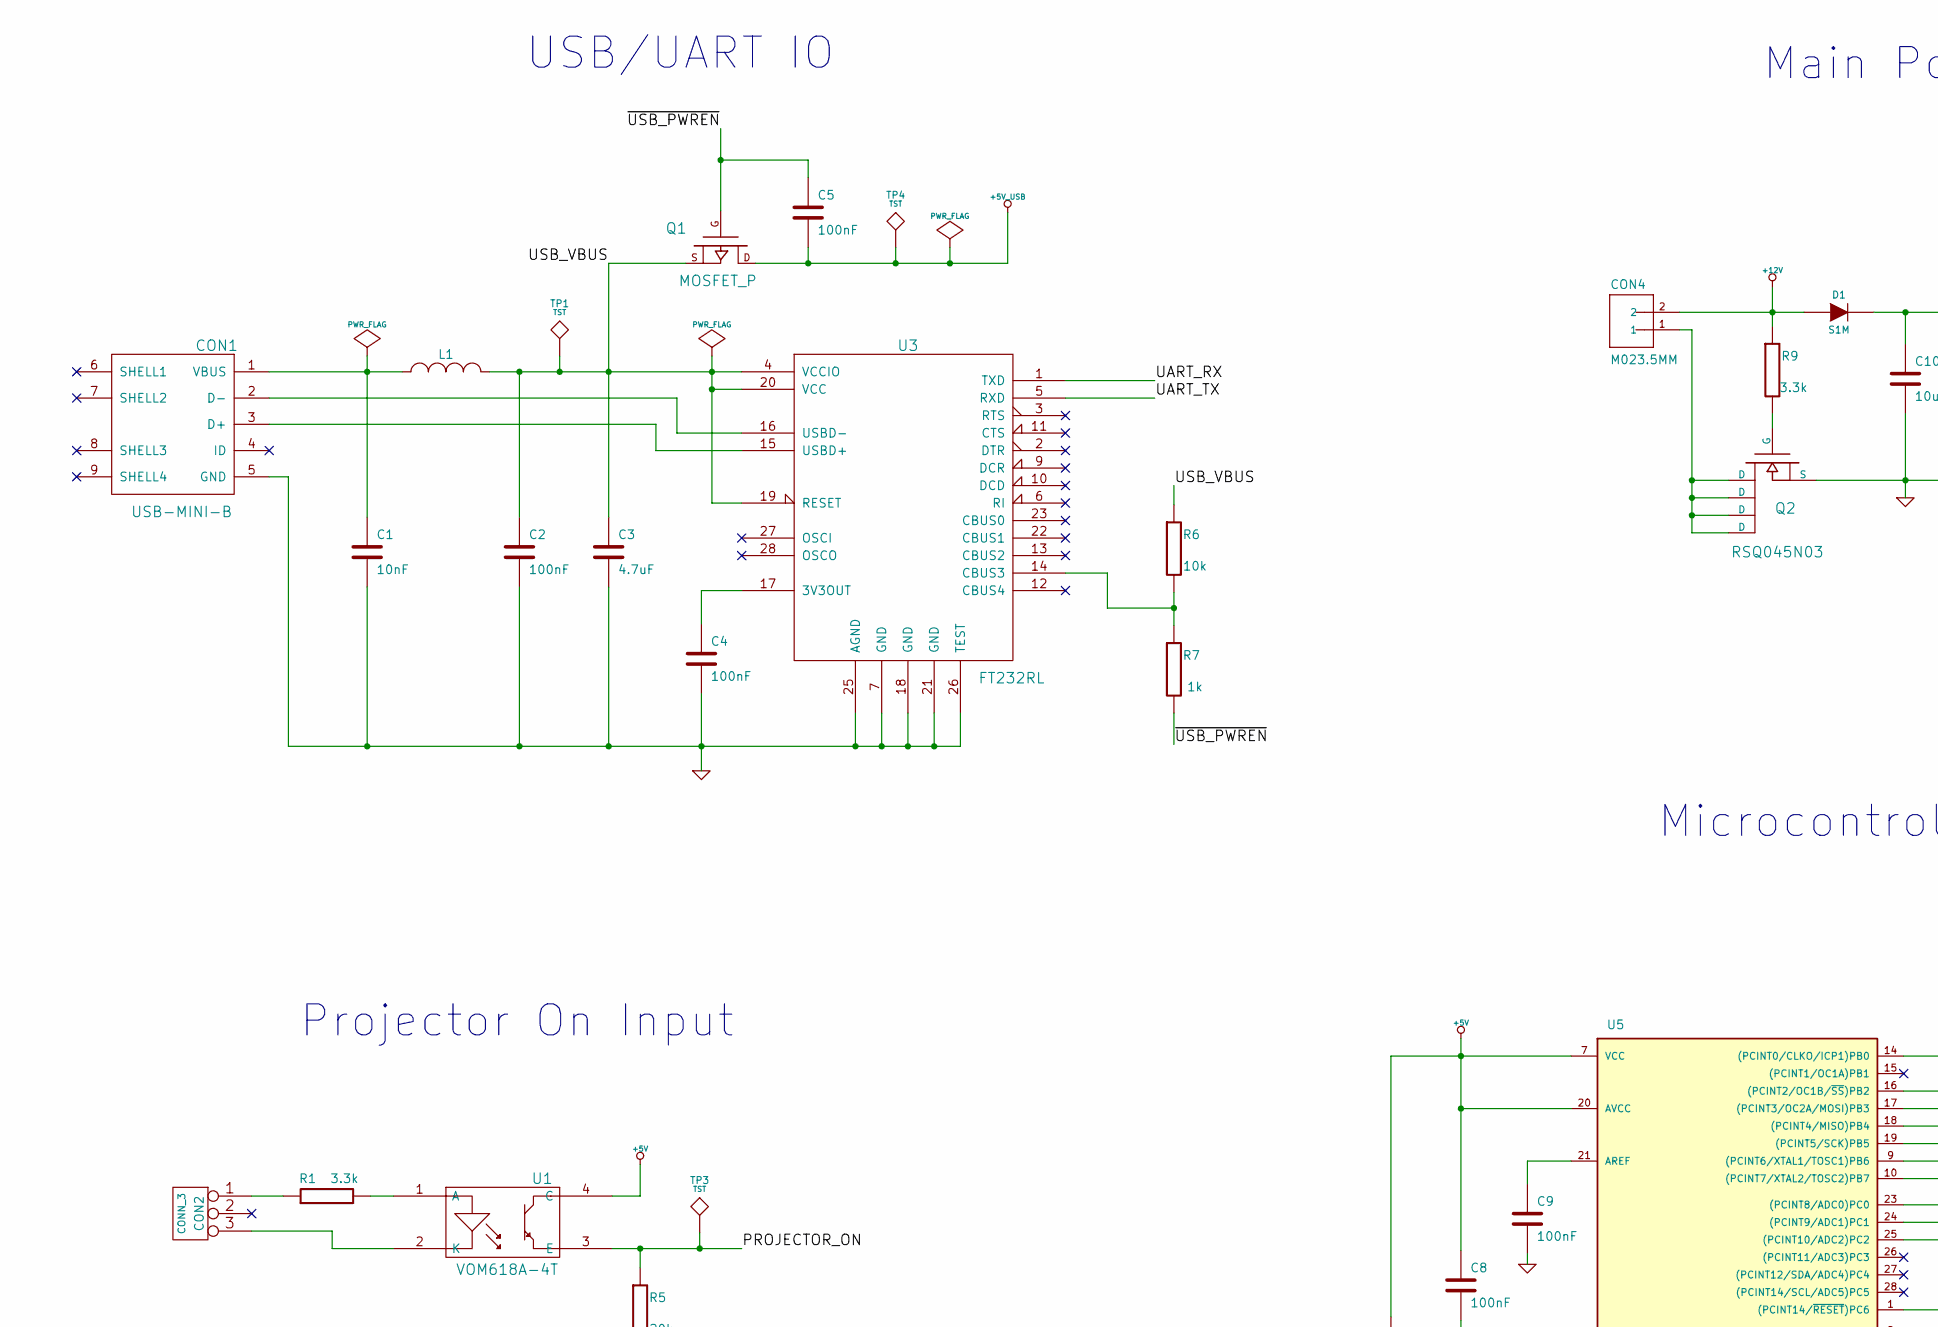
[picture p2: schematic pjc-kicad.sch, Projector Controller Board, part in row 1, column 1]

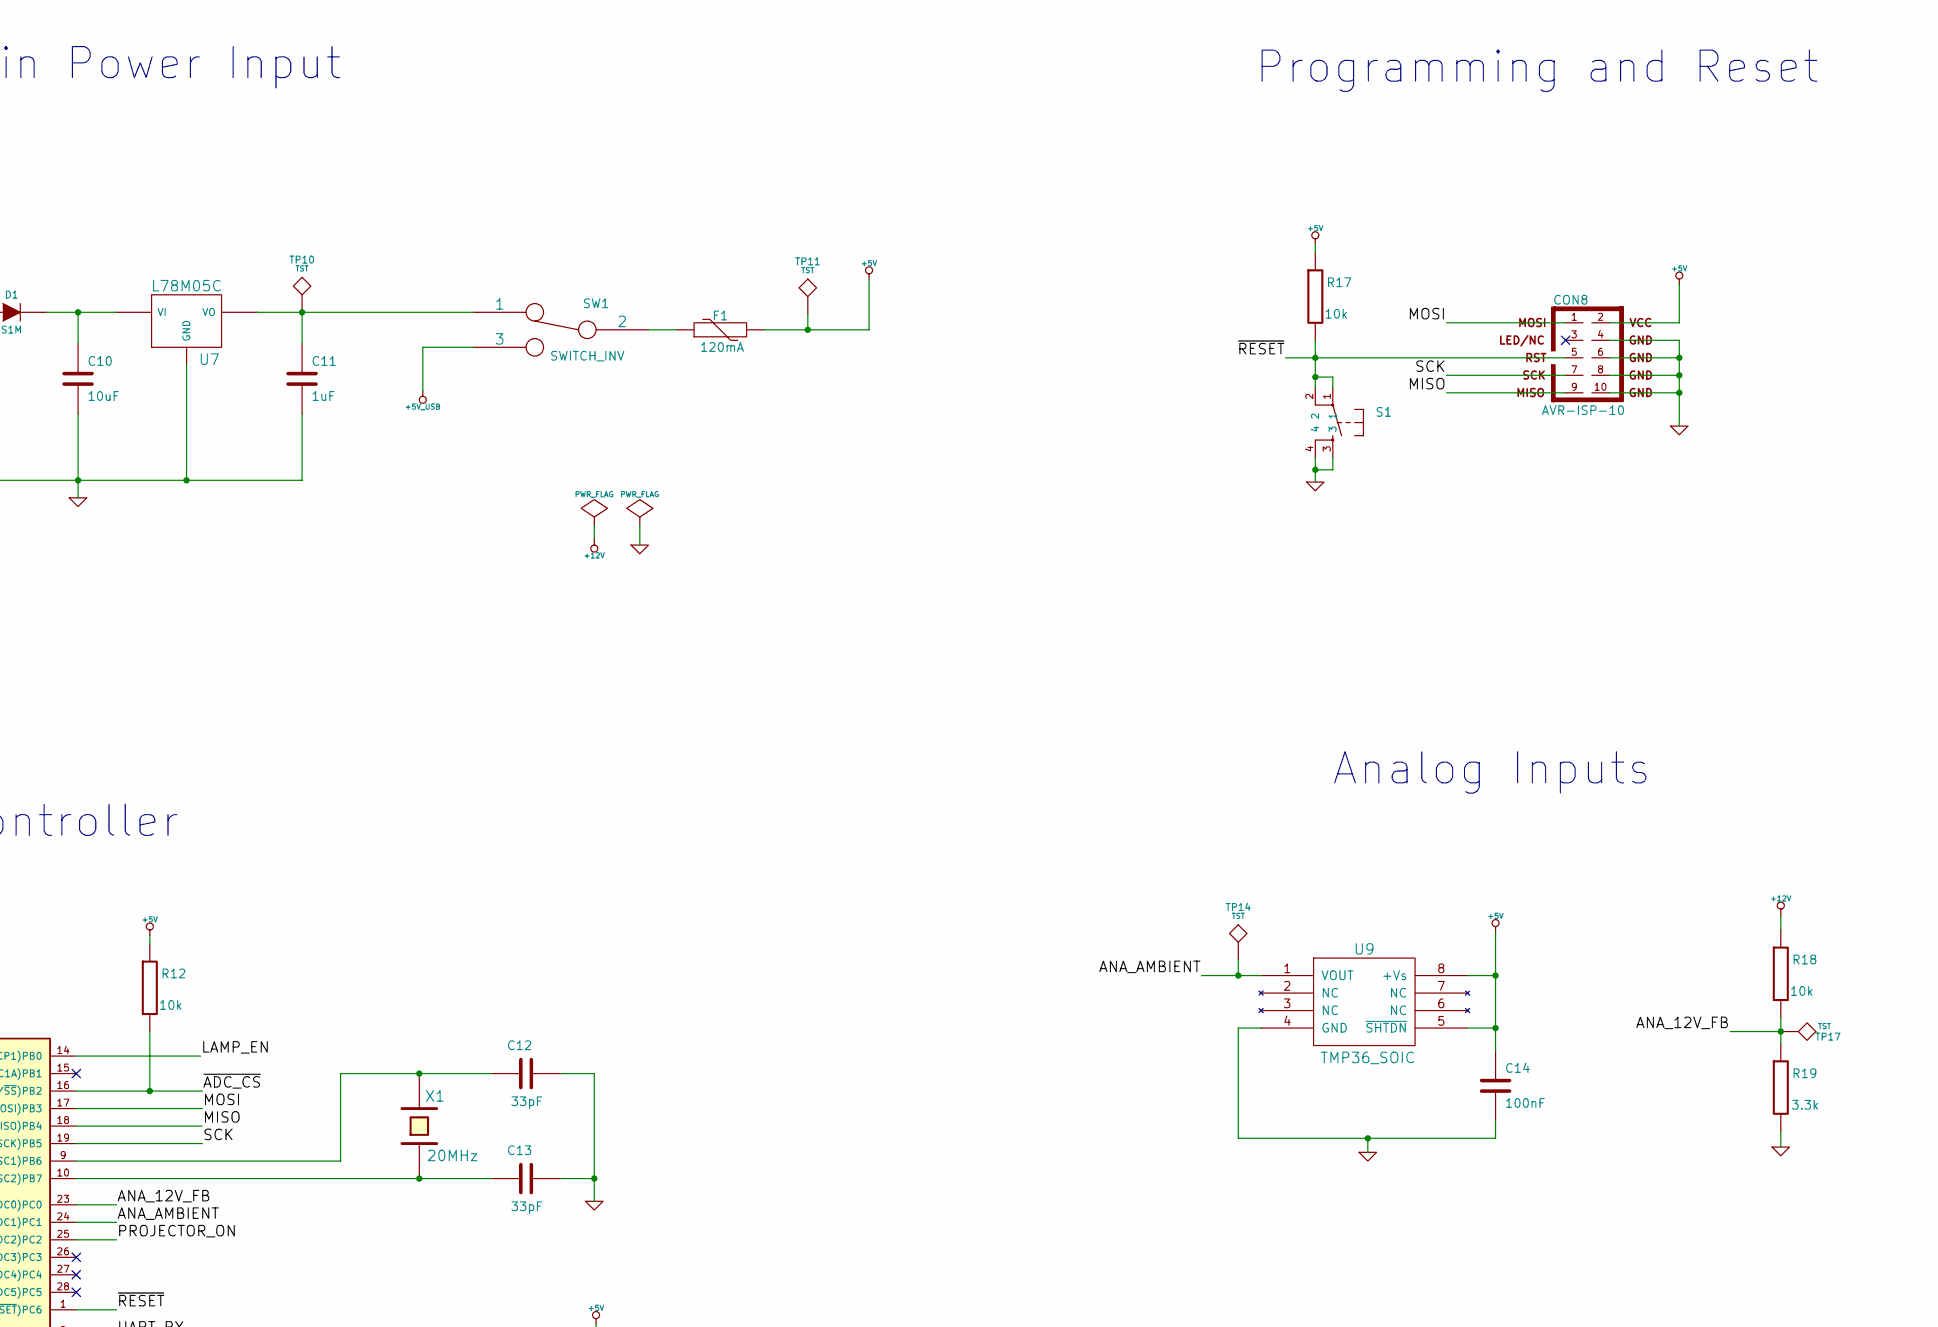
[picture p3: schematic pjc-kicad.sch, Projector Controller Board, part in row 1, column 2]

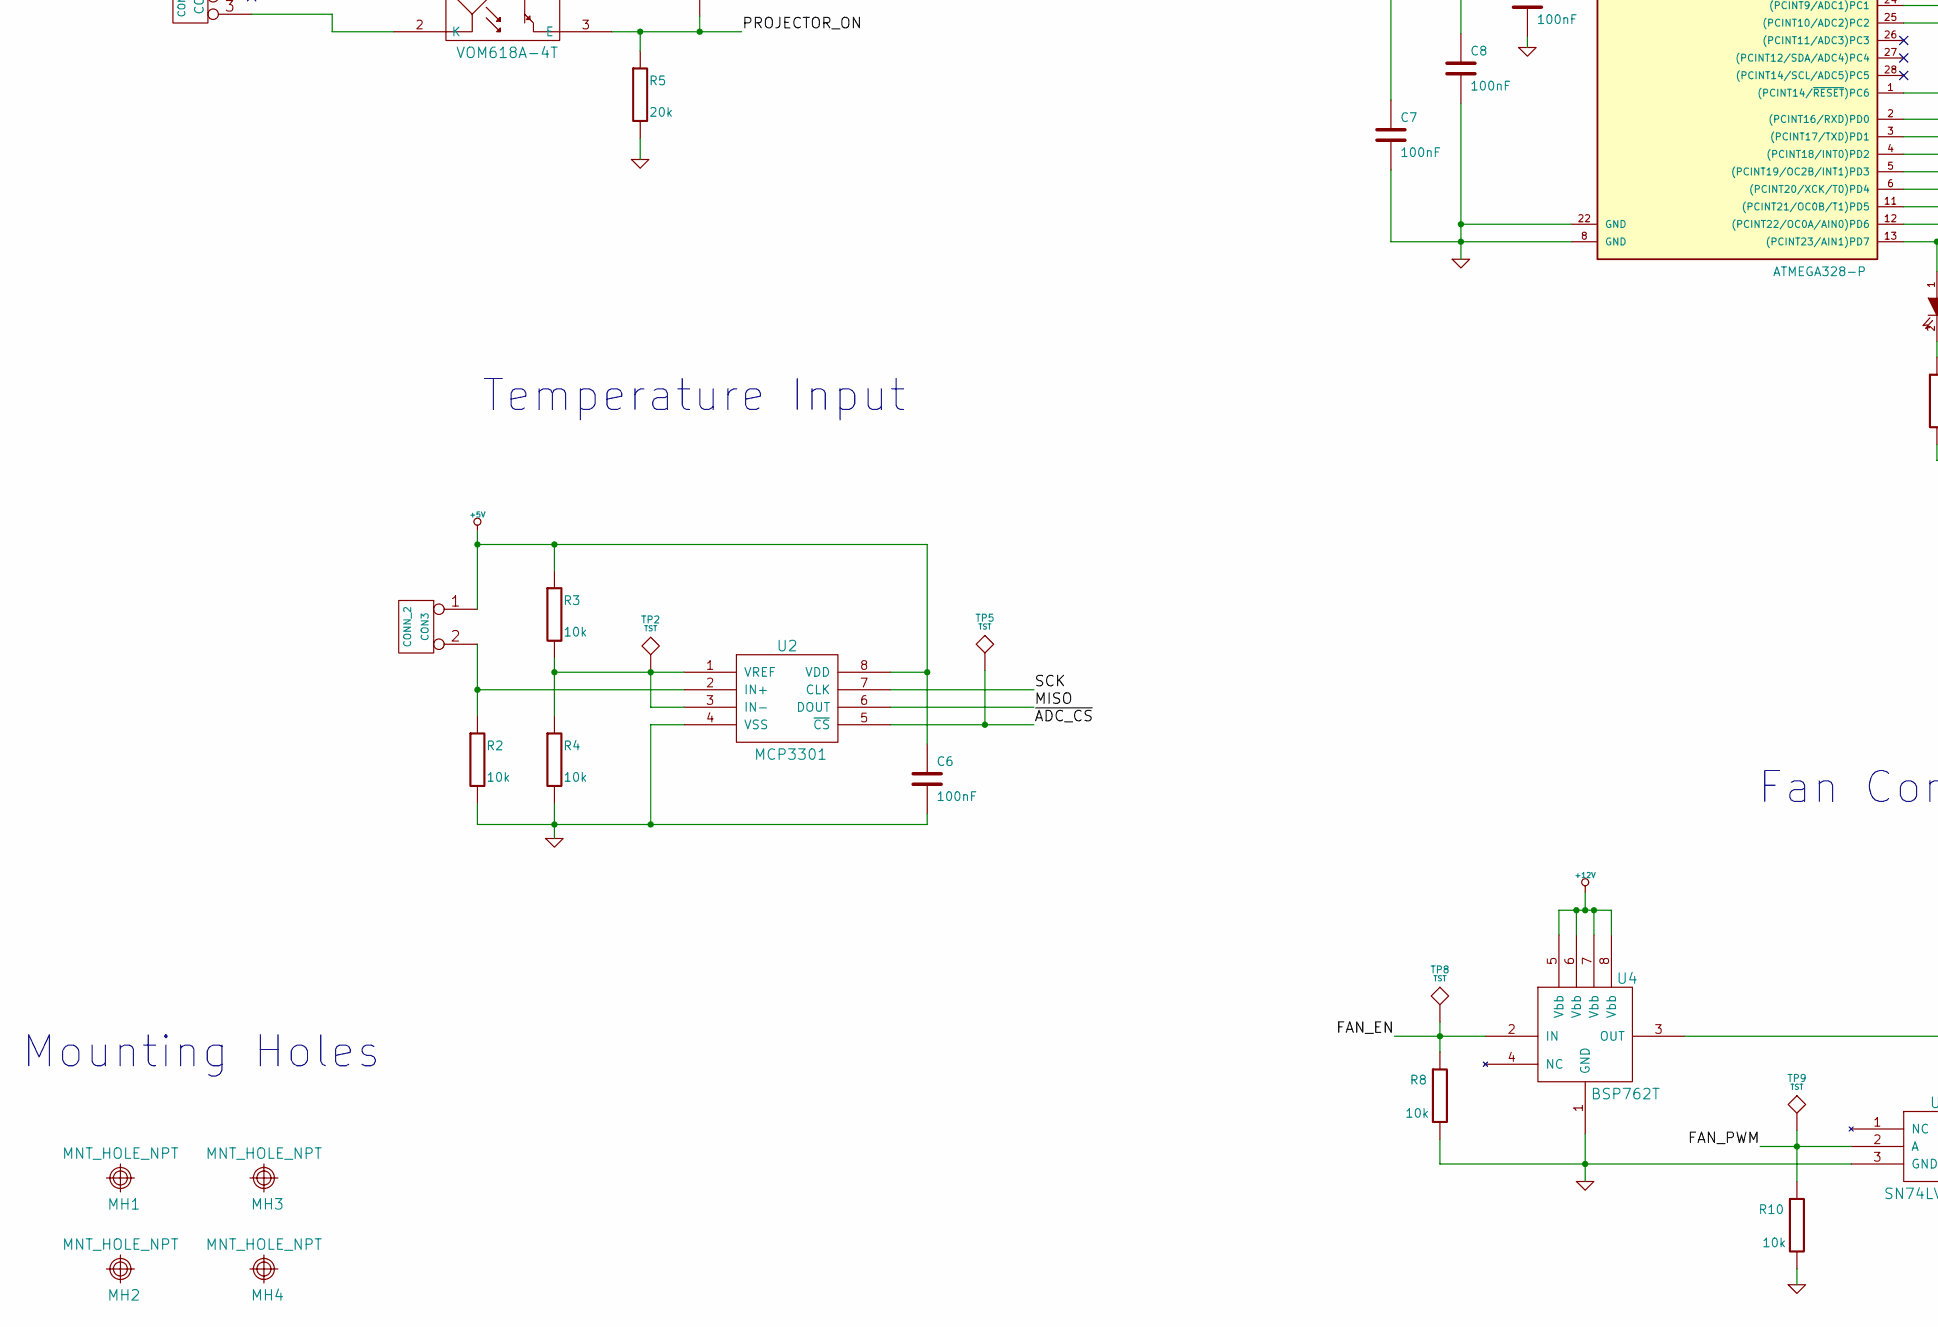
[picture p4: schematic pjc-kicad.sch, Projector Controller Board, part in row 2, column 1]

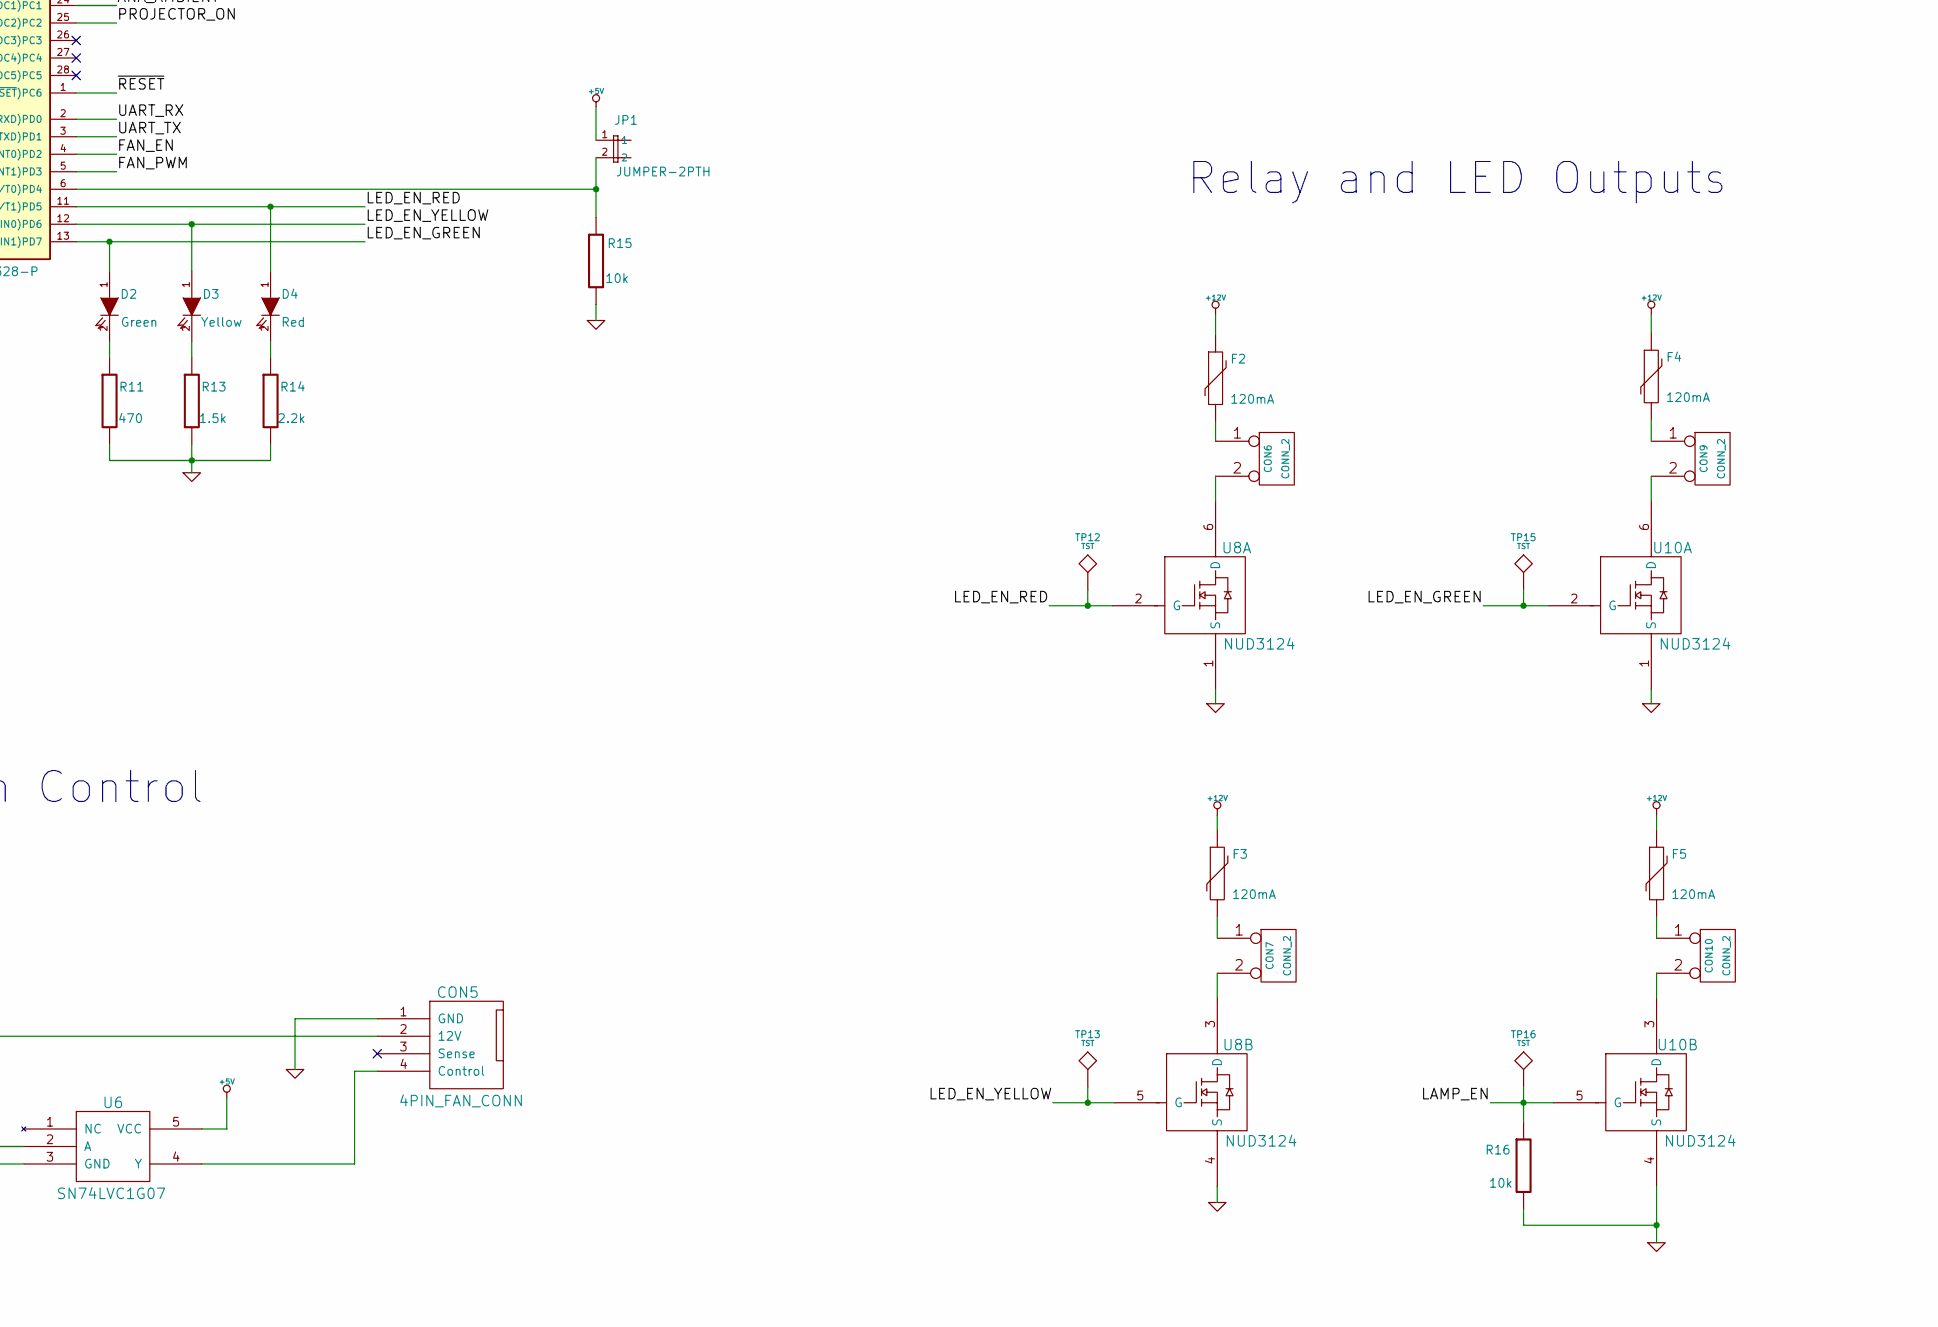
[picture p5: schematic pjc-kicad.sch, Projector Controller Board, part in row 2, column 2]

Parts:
C1: 10nF
C2, C4, C5, C6, C7, C8, C9, C14: 100nF
C3: 4.7uF
C10: 10uF
C11: 1uF
C12, C13: 33pF
CON1: USB-MINI-B
CON2: CONN_3
CON3, CON6, CON7, CON9, CON10: CONN_2
CON4: M023.5MM; SparkFun-SCREWTERMINAL-3.5MM-2
CON5: 4PIN_FAN_CONN; 4PIN_FAN_PTH
CON8: AVR-ISP-10
D1: S1M
D2: Green
D3: Yellow
D4: Red
F1, F2, F3, F4, F5: 120mA
JP1: JUMPER-2PTH; SparkFun-1X02
L1: INDUCTOR_SMALL
MH1, MH2, MH3, MH4: MNT_HOLE_NPT
Q1: MOSFET_P
Q2: RSQ045N03
R1, R9, R19: 3.3k
R2, R3, R4, R6, R8, R10, R12, R15, R16, R17, R18: 10k
R5: 20k
R7: 1k
R11: 470
R13: 1.5k
R14: 2.2k
S1: TAC_SWITCHSMD; SparkFun-TACTILE_SWITCH_SMD
SW1: SWITCH_INV
TP1, TP2, TP3, TP4, TP5, TP8, TP9, TP10, TP11, TP12, TP13, TP14, TP15, TP16, TP17: TST
U1: VOM618A-4T
U2: MCP3301
U3: FT232RL
U4: BSP762T
U5: ATMEGA328-P; DIL28
U6: SN74LVC1G07; SOT23-5
U7: L78M05C
U8, U10: NUD3124
U9: TMP36_SOIC; SO8E
X1: 20MHz

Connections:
+5V: C6.1, C7.1, C8.1, C14.1, CON3.1, CON8.2, F1.2, JP1.1, R3.1, R12.1, R17.1, TP11.1, U1.4 (C), U2.8 (VDD), U5.7 (VCC), U5.20 (AVCC), U6.5 (VCC), U9.5 (~SHTDN), U9.8 (+Vs)
+5V_USB: C5.2, Q1.D, SW1.3, TP4.1
+12V: CON4.2, D1.1 (A), F2.1, F3.1, F4.1, F5.1, R9.1, R18.1, U4.5 (Vbb), U4.6 (Vbb), U4.7 (Vbb), U4.8 (Vbb)
/ANA_12V_FB: R18.2, R19.1, TP17.1, U5.23 ((PCINT8/ADC0)PC0)
/ANA_AMBIENT: TP14.1, U5.24 ((PCINT9/ADC1)PC1), U9.1 (VOUT)
/FAN_EN: R8.1, TP8.1, U4.2 (IN), U5.4 ((PCINT18/INT0)PD2)
/FAN_PWM: R10.1, TP9.1, U5.5 ((PCINT19/OC2B/INT1)PD3), U6.2 (A)
/LAMP_EN: R16.1, TP16.1, U5.14 ((PCINT0/CLKO/ICP1)PB0), U10.5 (G)
/LED_EN_GREEN: D2.1 (A), TP15.1, U5.13 ((PCINT23/AIN1)PD7), U10.2 (G)
/LED_EN_RED: D4.1 (A), TP12.1, U5.11 ((PCINT21/OC0B/T1)PD5), U8.2 (G)
/LED_EN_YELLOW: D3.1 (A), TP13.1, U5.12 ((PCINT22/OC0A/AIN0)PD6), U8.5 (G)
/MISO: CON8.9, U2.6 (DOUT), U5.18 ((PCINT4/MISO)PB4)
/MOSI: CON8.1, U5.17 ((PCINT3/OC2A/MOSI)PB3)
/PROJECTOR_ON: R5.1, TP3.1, U1.3 (E), U5.25 ((PCINT10/ADC2)PC2)
/SCK: CON8.7, U2.7 (CLK), U5.19 ((PCINT5/SCK)PB5)
/UART_RX: U3.1 (TXD), U5.2 ((PCINT16/RXD)PD0)
/UART_TX: U3.5 (RXD), U5.3 ((PCINT17/TXD)PD1)
/USB_VBUS: C2.1, C3.1, L1.2, Q1.S, R6.1, TP1.1, U3.4 (VCCIO), U3.19 (RESET), U3.20 (VCC)
/~ADC_CS: R12.2, TP5.1, U2.5 (~CS), U5.16 ((PCINT2/OC1B/~SS~)PB2)
/~RESET: CON8.5, R17.2, S1.1, S1.2, U5.1 ((PCINT14/~RESET~)PC6)
/~USB_PWREN: C5.1, Q1.G, R7.2
GND: C1.2, C2.2, C3.2, C4.2, C6.2, C7.2, C8.2, C9.2, C10.2, C11.2, C12.2, C13.2, C14.2, CON1.5 (GND), CON5.1 (GND), CON8.4, CON8.6, CON8.8, CON8.10, Q2.4 (S), R2.2, R4.2, R5.2, R8.2, R10.2, R11.2, R13.2, R14.2, R15.2, R16.2, R19.2, S1.3, S1.4, U2.4 (VSS), U3.7 (GND), U3.18 (GND), U3.21 (GND), U3.25 (AGND), U3.26 (TEST), U4.1 (GND), U5.8 (GND), U5.22 (GND), U6.3 (GND), U7.GND, U8.1 (S), U8.4 (S), U9.4 (GND), U10.1 (S), U10.4 (S)
unnamed: D4.2 (K), R14.1
unnamed: C4.1, U3.17 (3V3OUT)
unnamed: D2.2 (K), R11.1
unnamed: D3.2 (K), R13.1
unnamed: R3.2, R4.1, TP2.1, U2.1 (VREF), U2.3 (IN-)
unnamed: CON3.2 (PM), R2.1, U2.2 (IN+)
unnamed: C9.1, U5.21 (AREF)
unnamed: C10.1, D1.2 (K), U7.VI
unnamed: CON1.2 (D-), U3.16 (USBD-)
unnamed: CON1.3 (D+), U3.15 (USBD+)
unnamed: JP1.2, R15.1, U5.6 ((PCINT20/XCK/T0)PD4)
unnamed: R6.2, R7.1, U3.14 (CBUS3)
unnamed: C1.1, CON1.1 (VBUS), L1.1
unnamed: Q2.3 (G), R9.2
unnamed: CON5.2 (12V), U4.3 (OUT)
unnamed: CON5.4 (Control), U6.4 (Y)
unnamed: CON2.1, R1.1
unnamed: R1.2, U1.1 (A)
unnamed: CON2.3, U1.2 (K)
unnamed: C11.1, SW1.1, TP10.1, U7.VO
unnamed: CON6.2 (PM), U8.6 (D)
unnamed: CON9.2 (PM), U10.6 (D)
unnamed: CON7.2 (PM), U8.3 (D)
unnamed: CON10.2 (PM), U10.3 (D)
unnamed: CON9.1, F4.2
unnamed: CON4.1, Q2.1 (D), Q2.2 (D), Q2.5 (D), Q2.6 (D)
unnamed: CON6.1, F2.2
unnamed: CON10.1, F5.2
unnamed: CON7.1, F3.2
unnamed: F1.1, SW1.2
unnamed: C13.1, U5.10 ((PCINT7/XTAL2/TOSC2)PB7), X1.1
unnamed: C12.1, U5.9 ((PCINT6/XTAL1/TOSC1)PB6), X1.2

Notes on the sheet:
USB/UART IO
Main Power Input
Programming and Reset
Microcontroller
Projector On Input
Analog Inputs
Relay and LED Outputs
Fan Control
Temperature Input
Mounting Holes

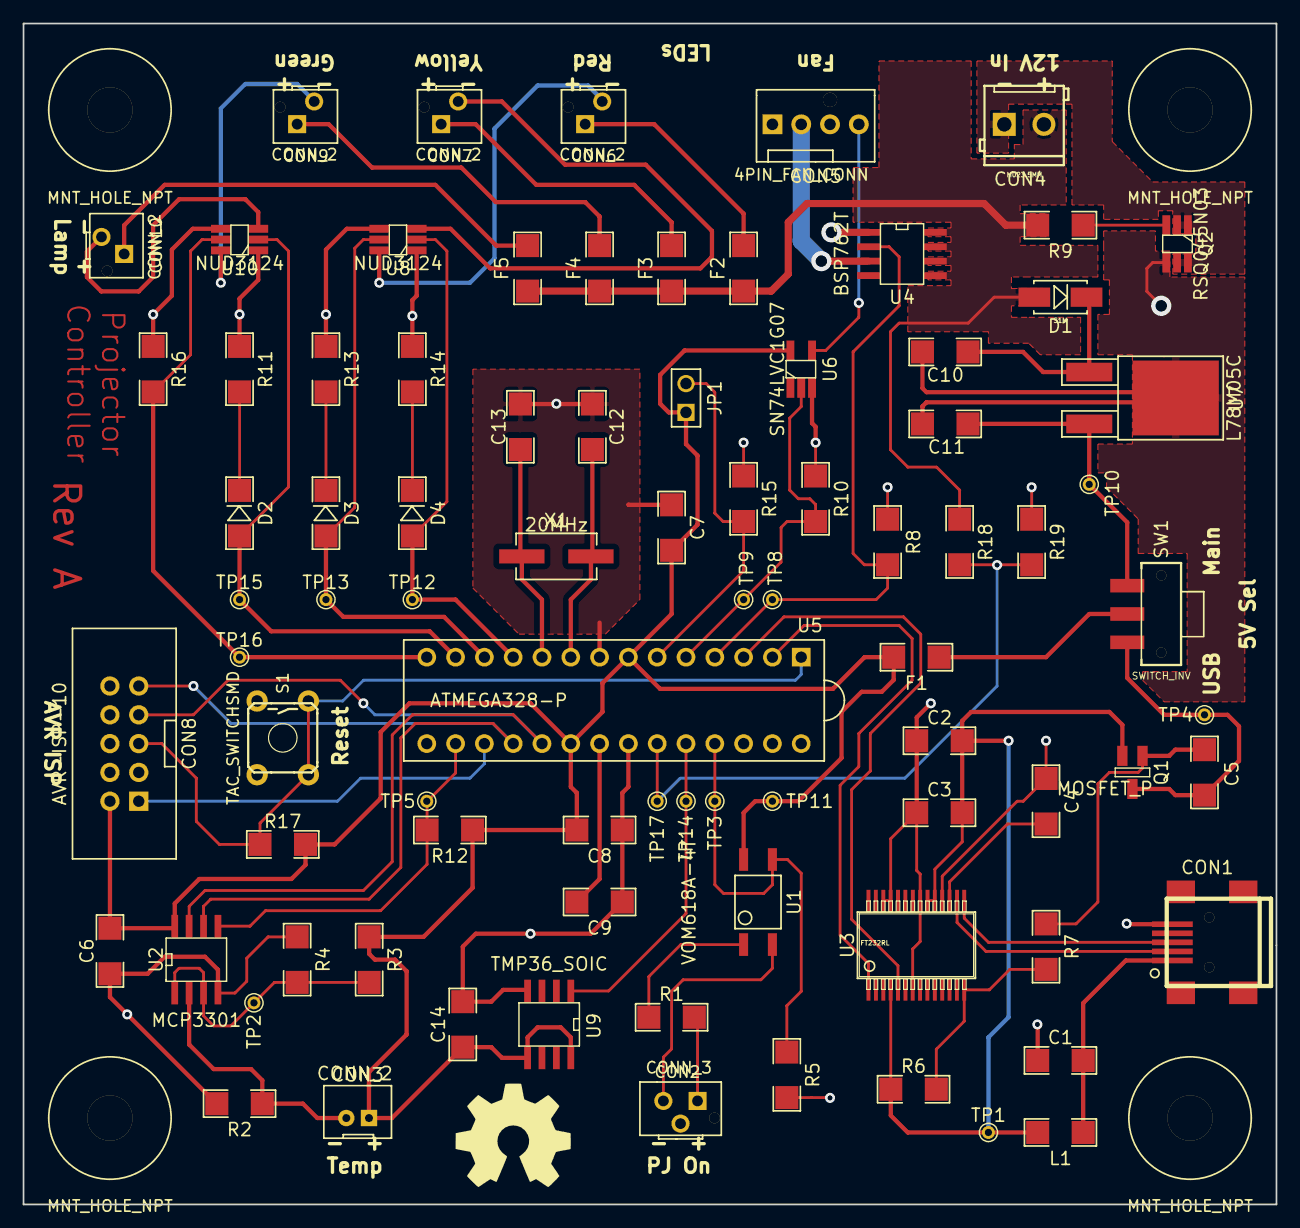
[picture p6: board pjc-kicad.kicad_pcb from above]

Board: 2 copper layers, 110.5 x 104.1 mm, 88 parts (0 on the bottom side), 54 nets.

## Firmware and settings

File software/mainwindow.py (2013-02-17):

#! /usr/bin/env python
#
# Copyright 2011-2013 Jesse DeGuire
#
# This file is part of Projector Controller.
#
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
"""
File:   mainwindow.py
Author: Jesse DeGuire

Contains the MainWindow class, which creates the main dialog frame that contains the app.
"""

from PySide import QtCore
from PySide.QtCore import *
from PySide.QtGui import *

from connmanager import ConnectionManager
from monitorpage import MonitorPage
from settingspage import SettingsPage
from updatepage import UpdatePage


class MainWindow(QDialog):
    serialopenclicked = QtCore.Signal(str)

    def __init__(self, connmgr, title):
        QDialog.__init__(self)
        self.setWindowTitle(title)

        self.serialcombo = QComboBox()
        self.serialcombo.setInsertPolicy(QComboBox.InsertPolicy.InsertAtTop)
        self.serialcombo.setEditable(True)
        self.serialcombo.setMinimumWidth(180)

        self.serialopenbutton = QPushButton('Open')
        self.serialopenbutton.setSizePolicy(QSizePolicy.Fixed, QSizePolicy.Fixed)

        self.serialrefreshbutton = QPushButton('Refresh')
        self.serialrefreshbutton.setSizePolicy(QSizePolicy.Fixed, QSizePolicy.Fixed)

        self.monitorpage = MonitorPage(connmgr)
        self.settingspage = SettingsPage(connmgr)
        self.updatepage = UpdatePage(connmgr)

        self.tabwidget = QTabWidget()
        self.tabwidget.addTab(self.monitorpage, 'Monitor')
        self.tabwidget.addTab(self.settingspage, 'Settings')
        self.tabwidget.addTab(self.updatepage, 'Update')

        self.loglabel = QLabel('Log')
        self.logbox = QTextEdit()
        self.logbox.LineWrapMode = QTextEdit.WidgetWidth
        self.logbox.setReadOnly(True)
        self.logbox.setTabChangesFocus(True)
        self.logbox.setVerticalScrollBarPolicy(Qt.ScrollBarAlwaysOn)
        self.logbox.document().setMaximumBlockCount(1024)

        self.logclearbutton = QPushButton('Clear')

        # set up external connections
        connmgr.addSignal(self.serialrefreshbutton.clicked, 'EnumerateSerial')
        connmgr.addSignal(self.serialopenclicked, 'OpenSerial')
        connmgr.addSlot(self.setSerialPortChoices, 'SerialEnumerated')
        connmgr.addSlot(self.logbox.append, 'WriteToLog')

        # connect signals to internal slots
        self.serialopenbutton.clicked.connect(self.openSerial)
        self.logclearbutton.clicked.connect(self.logbox.clear)

        # set up our control layout
        self.vbox = QVBoxLayout(self)
        self.serialhbox = QHBoxLayout()

        self.vbox.addLayout(self.serialhbox)
        self.serialhbox.addWidget(self.serialcombo)
        self.serialhbox.addWidget(self.serialopenbutton)
        self.serialhbox.addWidget(self.serialrefreshbutton)
        self.vbox.addSpacing(10)
        self.vbox.addWidget(self.tabwidget)
        self.vbox.addSpacing(10)
        self.vbox.addWidget(self.loglabel)
        self.vbox.addWidget(self.logbox)
        self.vbox.addWidget(self.logclearbutton)
        self.vbox.setAlignment(self.logclearbutton, Qt.AlignLeft)

    @QtCore.Slot()
    def openSerial(self):
        self.serialopenclicked.emit(self.serialcombo.currentText())

    @QtCore.Slot(list)
    def setSerialPortChoices(self, portlist):
        self.serialcombo.clear()
        self.serialcombo.addItems(portlist)

    def writeToLog(self, text):
        self.logbox.append(text)

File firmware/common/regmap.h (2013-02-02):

/* Copyright © 2011-2013 Jesse DeGuire
 *
 * This file is part of Projector Controller.
 *
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
 * File:   regmap.h
 * Author: Jesse DeGuire
 * 
 * A register map for the ATmega328P (and the related 168/88/48/etc.) allowing access to the
 * device's special function registers as though they were structures.	The addresses are known at
 * compile time, meaning that the compiler can use the faster SBI/CBI/IN/OUT instructions as
 * appropriate.
 */

#ifndef INCLUDE_REGMAP_H_
#define INCLUDE_REGMAP_H_

#include <avr/io.h>

struct PINBbits_t
{
	uint8_t pinb0:1; 
	uint8_t pinb1:1;
	uint8_t pinb2:1; 
	uint8_t pinb3:1;
	uint8_t pinb4:1; 
	uint8_t pinb5:1;
	uint8_t pinb6:1; 
	uint8_t pinb7:1;
};

#define PINBbits (*(volatile struct PINBbits_t *)_SFR_MEM_ADDR(PINB))


struct DDRBbits_t
{
	uint8_t ddb0:1;
	uint8_t ddb1:1;
	uint8_t ddb2:1;
	uint8_t ddb3:1;
	uint8_t ddb4:1;
	uint8_t ddb5:1;
	uint8_t ddb6:1;
	uint8_t ddb7:1;
};

#define DDRBbits (*(volatile struct DDRBbits_t *)_SFR_MEM_ADDR(DDRB))


struct PORTBbits_t
{
	uint8_t pb0:1;
	uint8_t pb1:1;
	uint8_t pb2:1; 
	uint8_t pb3:1;
	uint8_t pb4:1; 
	uint8_t pb5:1;
	uint8_t pb6:1; 
	uint8_t pb7:1;
};

#define PORTBbits (*(volatile struct PORTBbits_t *)_SFR_MEM_ADDR(PORTB))


struct PINCbits_t
{
	uint8_t pinc0:1; 
	uint8_t pinc1:1;
	uint8_t pinc2:1; 
	uint8_t pinc3:1;
	uint8_t pinc4:1; 
	uint8_t pinc5:1;
	uint8_t pinc6:1; 
	uint8_t		 :1;
};

#define PINCbits (*(volatile struct PINCbits_t *)_SFR_MEM_ADDR(PINC))


struct DDRCbits_t
{
	uint8_t ddc0:1;
	uint8_t ddc1:1;
	uint8_t ddc2:1;
	uint8_t ddc3:1;
	uint8_t ddc4:1;
	uint8_t ddc5:1;
	uint8_t ddc6:1;
	uint8_t		:1;
};

#define DDRBbits (*(volatile struct DDRBbits_t *)_SFR_MEM_ADDR(DDRB))


struct PORTCbits_t
{
	uint8_t pc0:1;
	uint8_t pc1:1;
	uint8_t pc2:1; 
	uint8_t pc3:1;
	uint8_t pc4:1; 
	uint8_t pc5:1;
	uint8_t pc6:1; 
	uint8_t	   :1;
};

#define PORTCbits (*(volatile struct PORTCbits_t *)_SFR_MEM_ADDR(PORTC))


struct PINDbits_t
{
	uint8_t pind0:1; 
	uint8_t pind1:1;
	uint8_t pind2:1; 
	uint8_t pind3:1;
	uint8_t pind4:1; 
	uint8_t pind5:1;
	uint8_t pind6:1; 
	uint8_t pind7:1;
};

#define PINDbits (*(volatile struct PINDbits_t *)_SFR_MEM_ADDR(PIND))


struct DDRDbits_t
{
	uint8_t ddd0:1;
	uint8_t ddd1:1;
	uint8_t ddd2:1;
	uint8_t ddd3:1;
	uint8_t ddd4:1;
	uint8_t ddd5:1;
	uint8_t ddd6:1;
	uint8_t ddd7:1;
};

#define DDRDbits (*(volatile struct DDRDbits_t *)_SFR_MEM_ADDR(DDRD))


struct PORTDbits_t
{
	uint8_t pd0:1;
	uint8_t pd1:1;
	uint8_t pd2:1; 
	uint8_t pd3:1;
	uint8_t pd4:1; 
	uint8_t pd5:1;
	uint8_t pd6:1; 
	uint8_t pd7:1;
};

#define PORTDbits (*(volatile struct PORTDbits_t *)_SFR_MEM_ADDR(PORTD))


struct TIFR0bits_t
{
	uint8_t	 tov0:1;
	uint8_t ocf0a:1;
	uint8_t ocf0b:1;
	uint8_t		 :5;
};

#define TIFR0bits (*(volatile struct TIFR0bits_t *)_SFR_MEM_ADDR(TIFR0))


struct TIFR1bits_t
{
	uint8_t	 tov1:1;
	uint8_t ocf1a:1;
	uint8_t ocf1b:1;
	uint8_t		 :2;
	uint8_t	 icf1:1;
	uint8_t		 :2;
};

#define TIFR1bits (*(volatile struct TIFR1bits_t *)_SFR_MEM_ADDR(TIFR1))


struct TIFR2bits_t
{
	uint8_t	 tov2:1;
	uint8_t ocf2a:1;
	uint8_t ocf2b:1;
	uint8_t		 :5;
};

#define TIFR2bits (*(volatile struct TIFR2bits_t *)_SFR_MEM_ADDR(TIFR2))


struct PCIFRbits_t
{
	uint8_t pcif0:1;
	uint8_t pcif1:1;
	uint8_t pcif2:1;
	uint8_t		 :5;
};

#define PCIFRbits (*(volatile struct PCIFRbits_t *)_SFR_MEM_ADDR(PCIFR))


struct EIFRbits_t
{
	uint8_t intf0:1;
	uint8_t intf1:1;
	uint8_t		 :6;
};

#define EIFRbits (*(volatile struct EIFRbits_t *)_SFR_MEM_ADDR(EIFR))


struct EIMSKbits_t
{
	uint8_t int0:1;
	uint8_t int1:1;
	uint8_t		:6;
};

#define EIMSKbits (*(volatile struct EIMSKbits_t *)_SFR_MEM_ADDR(EIMSK))


struct GPIORXbits_t
{
	uint8_t gpio0:1;
	uint8_t gpio1:1;
	uint8_t gpio2:1;
	uint8_t gpio3:1;
	uint8_t gpio4:1;
	uint8_t gpio5:1;
	uint8_t gpio6:1;
	uint8_t gpio7:1;
};

#define GPIOR0bits (*(volatile struct GPIORXbits_t *)_SFR_MEM_ADDR(GPIOR0))
#define GPIOR1bits (*(volatile struct GPIORXbits_t *)_SFR_MEM_ADDR(GPIOR1))
#define GPIOR2bits (*(volatile struct GPIORXbits_t *)_SFR_MEM_ADDR(GPIOR2))


union EECRbits_t
{
	struct
	{
		uint8_t	 eere:1;
		uint8_t	 eepe:1;
		uint8_t eempe:1;
		uint8_t eerie:1;
		uint8_t eepm0:1;
		uint8_t eepm1:1;
		uint8_t		 :2;
	};
	struct
	{
		uint8_t		:4;
		uint8_t eepm:2;
		uint8_t		:2;
	};
};

#define EECRbits (*(volatile union EECRbits_t *)_SFR_MEM_ADDR(EECR))


// EEDR (EEPROM Data Register) does not have any fields
// EEARL (EEPROM Address Register Low) does not have any fields
// EEARH (EEPROM Address Register High) does not have any fields


struct GTCCRbits_t
{
	uint8_t psrsync:1;
	uint8_t	 psrasy:1;
	uint8_t		   :5;
	uint8_t		tsm:1;
};

#define GTCCRbits (*(volatile struct GTCCRbits_t *)_SFR_MEM_ADDR(GTCCR))


union TCCR0Abits_t
{
	struct
	{
		uint8_t	 wgm00:1;
		uint8_t	 wgm01:1;
		uint8_t		  :2;
		uint8_t com0b0:1;
		uint8_t com0b1:1;
		uint8_t com0a0:1;
		uint8_t com0a1:1;
	};
	struct
	{
		uint8_t	 wgm0:2;
		uint8_t		 :2;
		uint8_t com0b:2;
		uint8_t com0a:2;
	};
};

#define TCCR0Abits (*(volatile union TCCR0Abits_t *)_SFR_MEM_ADDR(TCCR0A))


union TCCR0Bbits_t
{
	struct
	{
		uint8_t	 cs00:1;
		uint8_t	 cs01:1;
		uint8_t	 cs02:1;
		uint8_t wgm02:1;
		uint8_t		 :2;
		uint8_t foc0b:1;
		uint8_t foc0a:1;
	};
	struct
	{
		uint8_t cs0:3;
		uint8_t	   :5;
	};
};

#define TCCR0Bbits (*(volatile union TCCR0Bbits_t *)_SFR_MEM_ADDR(TCCR0B))


// TCNT0 (Timer 0 Counter) does not have any fields
// OCR0A (Timer 0 Output Compare Register A) does not have any fields
// OCR0B (Timer 0 Output Compare Register B) does not have any fields


union SPCRbits_t
{
	struct
	{
		uint8_t spr0:1;
		uint8_t spr1:1;
		uint8_t cpha:1;
		uint8_t cpol:1;
		uint8_t mstr:1;
		uint8_t dord:1;
		uint8_t	 spe:1;
		uint8_t spie:1;
	};
	struct
	{
		uint8_t spr:2;
		uint8_t	   :6;
	};
};

#define SPCRbits (*(volatile union SPCRbits_t *)_SFR_MEM_ADDR(SPCR))


struct SPSRbits_t
{
	uint8_t spi2x:1;
	uint8_t		 :5;
	uint8_t	 wcol:1;
	uint8_t	 spif:1;
};

#define SPSRbits (*(volatile struct SPSRbits_t *)_SFR_MEM_ADDR(SPSR))


// SPDR (SPI Data Register) does not have any fields


union ACSRbits_t
{
	struct
	{
		uint8_t acis0:1;
		uint8_t acis1:1;
		uint8_t	 acic:1;
		uint8_t	 acie:1;
		uint8_t	  aci:1;
		uint8_t	  aco:1;
		uint8_t	 acbg:1;
		uint8_t	  acd:1;
	};
	struct
	{
		uint8_t acis:2;
		uint8_t		:6;
	};
};

#define ACSRbits (*(volatile union ACSRbits_t *)_SFR_MEM_ADDR(ACSR))


union SMCRbits_t
{
	struct
	{
		uint8_t	 se:1;
		uint8_t sm0:1;
		uint8_t sm1:1;
		uint8_t sm2:1;
		uint8_t	   :4;
	};
	struct
	{
		uint8_t	  :1;
		uint8_t sm:3;
		uint8_t	  :4;
	};
};

#define SMCRbits (*(volatile union SMCRbits_t *)_SFR_MEM_ADDR(SMCR))


struct MCUSRbits_t
{
	uint8_t	 porf:1;
	uint8_t extrf:1;
	uint8_t	 borf:1;
	uint8_t	 wdrf:1;
	uint8_t		 :4;
};

#define MCUSRbits (*(volatile struct MCUSRbits_t *)_SFR_MEM_ADDR(MCUSR))


struct MCUCRbits_t
{
	uint8_t	 ivce:1;
	uint8_t ivsel:1;
	uint8_t		 :2;
	uint8_t	  pud:1;
	uint8_t bodse:1;
	uint8_t	 bods:1;
	uint8_t		 :1;
};
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

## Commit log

2010-11-06 Blinking an LED: it's like "Hello, world!" for microcontrollers.
    Just got a breadboard together and used this to verify that it works. It does!
2010-11-06 Fixed permissions issues. Now maybe stuff will commit.
    [main.c]
2010-11-12 Found a better way to define SFRs as bitfields. See main.c.
    It turns out that defining addresses in the linker script has the effect of treating
    all SFRs, even ones in the special I/O space, as normal RAM locations (probably because
    the compiler doesn't know where they go, the linker does). This means that I/O registers
    don't use the quicker SBI/CBI-type instructions.
    [main.c]
2010-11-16 New UART module.
    Current just has macros to convert a desired baud rate into a value for the baud
    rate register and for computing the baud rate error. This also throws an error if
    the baud rate generated by the baud rate register is off from the desired baud rate
    by more than 2%.
    [main.c, uart.c]
2010-11-21 Now have a working UART interface.
    I also needed to make a change to the SConstruct file to tell the linker what
    MCU I'm using.
2010-12-04 Added program memory functions to UART code and working on memlayout module for stuff shared between the bootloader and app.
2010-12-05 Added watchdog, shared data, and fixed deviceprog module, among other things.
    The processor can be reset using the watchdog and either land in the bootloader or
    restart the application. This is done with a new linker output section called
    .shareddata that is not initialized on startup. The section allows data to be shared
    by the application and bootloader that is retained across device resets. A function
    tests whether or not this data is valid. This was tested and does appear to work. Also,
    flash programming seems to work since I could program a dummy appinfo_t struct to
    flash, even when it crosses page boundaries.
    [main.c]
2010-12-05 The device will no longer start up in the bootloader when first powered on.
    If the device was reset by the watchdog, we check a flag that says whether or not we
    should restart the app or stay in the bootloader. If it was reset by a different source,
    such as the external reset or power-on reset, then we'll load the app since that's the
    expected behavior.
2010-12-09 Working on a serial command interface.
    The interface will be the means of communication between the PC
    and the device. It is set up so that most commands will be text-
    based, so that you can use them through a terminal like GTKTerm or
    TeraTerm. The only exception so far is when writing program data
    to the bootloader; a binary interface will probably be used for
    speed and space concerns.
    Right now, there are bootcmd.c.h and cmd.c.h. I thought that the
    latter would end up too big for the bootloader, so the former were
    created. However, it might turn out that I can go back to a
    single module. I'll have to see what the space requirements are
    like.
    [cmd.c, main.c, uart.c]
2011-01-28 More work on serial command interface.
    Moved back to a common codebase for the interface code. Added
    command for printing out help function for all of the functions
    as well as commands to restart the app or bootloader. I may move
    those out of common code later since there's conditional macros
    for those anyway.
    Also will need to make a way to choose if help strings are in RAM
    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
2011-01-31 Numerous improvments to bootloader.
    Removed the appinfo_t structure that was going to store the app
    CRC and number of pages within application space. Instead, I no
    longer care about the number of pages and the app's CRC will be
    stored in bootloader space. This simplifies code quite a bit as I
    was able to remove quite a bit of stuff from sharedmem.c.h and
    deviceprog.c.h, as well as the linker script.
    Also implemented all of the needed interface commands for the
    bootloader and added a new module (localcmd.c) for them; however,
    the bootloader is now too big for the 4KB limit. I'll have to
    slim it down.
    [cmd.c, localcmd.c]
2011-02-04 main() is ready to go.
    Got rid of testing stuff and broke out startup items into functions.
    Still need to shrink down the bootloader size.
    Changed lockbits in SConscript so that we can write to the bootloader
    section. Still debating whether to keep CRC at end of boot space or
    application space.
    [main.c]
2011-02-05 Bootloader now actually fits in bootloader space.
    Removed use of strtoul() in PageProgram_CMD and used atol() and strchr()
    instead. Also shortened the command help strings a bit to save a tiny
    bit of space.
    Then added function to "rewind" all of the settings that
    the bootloader sets up when starting up. This is called when the
    jump to app command is run.
    [cmd.c, localcmd.c, main.c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]
2011-02-28 Learnin' me some Python. Awwwww yeah!
    Currently working on the interface to the PJC bootloader, which will
    comprise of one class, PJCBootloader, within the pjcbootloader.py
    module. The module also contains a small helper class representing
    an Intel Hex record that is used by the PJCBootloader class.
2011-02-28 Fixed SConstruct and SConscript so that common modules are not built in the 'common/' directory.
    [pjcbootloader.py]
2011-03-18 Added method to jump from the bootloader to the app. Also fixed problems with receiving serial data from the device.
    [pjcbootloader.py]
2011-03-22 More bootloader improvements.
    --Default baud rate is 115200, up from 57600.
    --Print help command is part of interface state machine. This will stop the help command from
    taking up time sitting and spinning.
    --Macro names prefixed with module name to help avoid conflicts.
    --Fixed some comments.
    --Cleaned up unneeded prog_char arrays in cmd.c and localcmd.c.
    --Changed script so that avrdude programs much faster (added "-B1" to command string).
    [cmd.c, localcmd.c, regmap.h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]
2011-03-23 Fixed EraseApp and EraseEEPROM commands.
    [localcmd.c]
2011-03-23 Forgot about the Bootloader Status ('s') command.
    Also updated the baud rate to 115200 and changed the eraseEEPROM() method to wait up to six seconds
    for the device to respond. This is because the EEPROM erase can take a very long time.
2011-05-14 The bootloader actually works now!
    I was able to download a small application with a test script in pjcbootloader.py after making some fixes to both the Python and the bootloader code.
    Also, the bootloader is a bit smaller now. The very last page of flash is dedicated to just the app validation key and CRC, which simplified a little of the bootloader code. The old code was the cause of an update problem, so that was another reason to remove it.
    [localcmd.c, main.c, pjcbootloader.py]
2011-08-20 Dusting off the repo with some PySide.
    Adding a main.py so I can keep track of what I'm doing with PySide while I'm learning it.
2011-10-12 Some work on UI thread/Serial thread communication.
    Oh, there are threads now. A Dispatcher object was created to handle communication between threads and it seems to work okay so far. Now comes the task of making it work with the firmware.
2012-05-28 Add new document for Intel's 4-pin fan connector specification.
    The controller will use the standard 4-pin connector for its fans since that makes the board easier to design and 4-pin fans are pretty common and cheap.
2012-05-28 Minor update to the connectors I want to use.
    I also put some LED info in there only because that'll come in handly later on.
2012-05-28 Split the eCmdHelp state in Cmd_ProcessInterface() into two states to make it a bit easier to follow.
    Uart.c has a couple of small typos fixed. Localcmd.c starts the status codes at 0 instead of 0x80.
    [cmd.c, localcmd.c, uart.c]
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2012-06-03 Forgot to put these in the last commit.
    Adding a new file for the communication thread and removing the dispatcher since it is no longer needed (now using Qt signals and slots).
    [commthread.py]
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2012-07-08 Multiple changes to bootloader code, including change in how updates are performed.
    Renamed system.h to appcfg.h since that seems more appropriate for what the file does (did this for app as well).
    Made filling the AVR's flash write latches a separate function from programming a page.
    Erasing EEPROM now manually uses the AVR erase-only mode and erases only cells that are not already clear. This no longer uses the AVR libc function for writing to EEPROM since that always uses erase-and-write mode.
    Loading page data is now a separate serial command from programming the page. This makes programming easier since one no longer has a small window in which to write binary data over the serial por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
    [cmd.c, localcmd.c]
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2012-07-10 Add commands to the app and fix an issue in common code.
    Clear watchdog when grabbing new command data in Cmd_ProcessInterface. Weird errors were popping up while testing the software and this seemed to be the issue.
    Add a few basic serial commands to the application and have it run the command interface. This now allows the app to work with the software, which assumes that the app can jump to the bootloader and return version information.
    [cmd.c, localcmd.c, main.c]
2012-07-15 Added new signal/slot manager class and fixed the worker thread.
    The new ConnectionManager class makes it easier to pair signals with slots by conecting signals and slots with the same given name automatically.
    It also turns out that you are not supposed to inherit from QThread but rather create your separate class and move it to a new QThread using the moveToThread() method. See http://labs.qt.nokia.com/2010/06/17/youre-doing-it-wrong/.
    [connmanager.py, main.py, pages.py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]
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2012-09-07 App is mostly complete, with all of the currently-planned pages and features available.
    Still needs testing and a bit more error handling. I may look into setting the app up for translations in the future. I still need to figure out how to use Py2Exe to get a Windows vesrion.
    [connmanager.py, main.py, mainwindow.py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]
2012-09-09 Firmware will now print "---Startup---" at bootup, which the software will look for so that it can report an Unexpected Restart Error (unless it was supposed to restart, like with a Jump or Reset com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
    [cmd.c, mainwindow.py, monitorpage.py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]
2012-09-09 Software now feature complete and handles various errors appropriately.
    The firmware now uses macros for their LED pins.
    [main.c, main.py, mainwindow.py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]
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2013-01-06 Add new KiCAD project
    [pjc-kicad.sch]
2013-01-07 More work on schematic and moved some stuff around.
    [pjc-kicad.kicad_pcb, pjc-kicad.sch]
2013-01-07 Created thermistor section using MCP3301 ADC and created TMP36 symbol.
    [pjc-kicad.sch]
2013-01-14 Add more datasheets as schematic moves toward completion.
    [pjc-kicad.sch]
2013-01-15 Schematic layout closer to completion
    [pjc-kicad.sch]
2013-01-22 lots more datasheets as schematic moves very close to completion
    [pjc-kicad.sch]
2013-01-27 Schematic mostly complete and reorganized datasheets
    [pjc-kicad.sch]
2013-01-29 Add pull-downs where needed to outputs and fix test points
    [pjc-kicad.sch]
2013-02-02 Added GPLv3 header to source code files.
    [pjc-kicad.sch]
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2013-02-08 More work on Hardware section of Developers Guide.
    Also added 1k resistor and 100nF cap to USB Enable P-MOSFET to more closely match circuit in FT23R datasheet.
    [pjc-kicad.sch]
2013-02-09 Completed circuit descriptions
    [Vishay Thm Calc.xls]
2013-02-10 Finished Hardware section in Dev Guide
    [pjc-kicad.sch]
2013-02-15 More work on Firmware section of doc and put 20kOhm pulldown on opto collector to reduce the current needed to saturate it (useful for 3.3V inputs).
    [pjc-kicad.sch]
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2013-02-17 Switch from Py2Exe to PyInstaller.
    PyInstaller claims to be able to make OS X executables and is actively
    developed. It also doesn't seem to require users install a specific
    version of the Visual C Redistributable Runtime.
2013-02-22 Completed Dev Guide draft.
    Changed 20MHz oscillator to one with smaller package.
    [pjcexcept.py]
2013-02-23 Added ADC conversion formulas and application error codes to software, making it mostly complete.
    Also updated devguide with minor fixes.
    [monitorpage.py]
2013-02-23 Modify wording for how to handle Microchip ADC reading of -4096, which indicates a missing thermistor.
2013-02-24 Replace Rohm RSQ035N03 with RSQ045N03 since the former appears to be discontinued. The latter has better specs anyway.
    [pjc-kicad.sch]
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2013-02-24 We now have a REAL Bill of Materials!
    [BoM.ods]
2013-02-24 Fix schematic errors found by KiCad and create symbol<-->footprint associations
    [BoM.ods, pjc-kicad.sch]
2013-02-25 Began laying out board
    [pjc-kicad.kicad_pcb, pjc-kicad.sch]
2013-02-27 More work on layout
    [pjc-kicad.kicad_pcb, pjc-kicad.sch]
2013-03-01 Completed USB portion of layout
    [pjc-kicad.kicad_pcb]
2013-03-02 Use 33pF caps on crystal instead of 22pF in order to more closely match the crystal's load capacitance
    [BoM.ods]
2013-03-03 Much closer to finished layout.
    Redid decoupling caps so that both ends connect directly to IC devices.
    [pjc-kicad.kicad_pcb]
2013-03-04 Changed crystal oscillator caps to 33pF
    [pjc-kicad.sch]
2013-03-04 More layout work.
    Rearranged a couple of pieces to reduce space (still working on that) and wired up more areas, including the ISP connector.
    [pjc-kicad.kicad_pcb]
2013-03-06 Layout: almost there...
    [pjc-kicad.kicad_pcb]
2013-03-08 Board layout done!
    Need to change NPTH mechanical holes to PTH holes since KiCad generates a second drill file for NPTH holes, which won't work.
    [pjc-kicad.kicad_pcb]
2013-03-09 Changed NPTHs to be PTHs with no pad since otherwise KiCAD will generate two drill files.
    KiCAD generates a separate drill file for NPTHs (non-plated through holes), which OSH Park does not want. Oh, I've decided to manufacture the boards at OSH Park. Should probably mention that.
    [pjc-kicad.kicad_pcb]
2013-03-09 Change from BatchPCB manufacture to OSH Park.
    [BoM.ods]
2013-03-09 Just sent board for manufacture!
    The modules in pjc.mod that were derived from the SparkFun library had the reference text on the wrong layer, so those had to be corrected by hand.
    [pjc-kicad.kicad_pcb]
2013-03-09 Add Gerber files to repo.
    Zip these up and submit to OSH Park to manufacture the board as-is.
    [pjc-kicad-B_Cu.gbl, pjc-kicad-B_Mask.gbs, pjc-kicad-Edge_Cuts.gbr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]
2013-03-09 Update README.txt to make it not totally worthless.
    Minor update to BoM.
    [BoM.ods]
2013-03-26 Fix a few footprints whose through-holes were not on the B.Mask layer, meaning that the bottom of the holes were covered in solder mask
    [BoM.ods, pjc-kicad.kicad_pcb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]

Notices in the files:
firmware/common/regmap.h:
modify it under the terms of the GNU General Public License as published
